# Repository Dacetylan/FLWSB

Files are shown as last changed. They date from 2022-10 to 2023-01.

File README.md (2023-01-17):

# FLSWB

Op deze webpagina kan je alle documentatie vinden over het Flexible LoRaWAN Development Board en alle onderdelen die daarbij horen.

Het project bestaat uit verschillende onderdelen:
- Printplaat met LoRaWAN verbinding
- Weerstation dat mee is geïntegreerd
- Backend die inkomende data verwerkt en opslaat
- Frontend om de metingen te kunnen weergeven

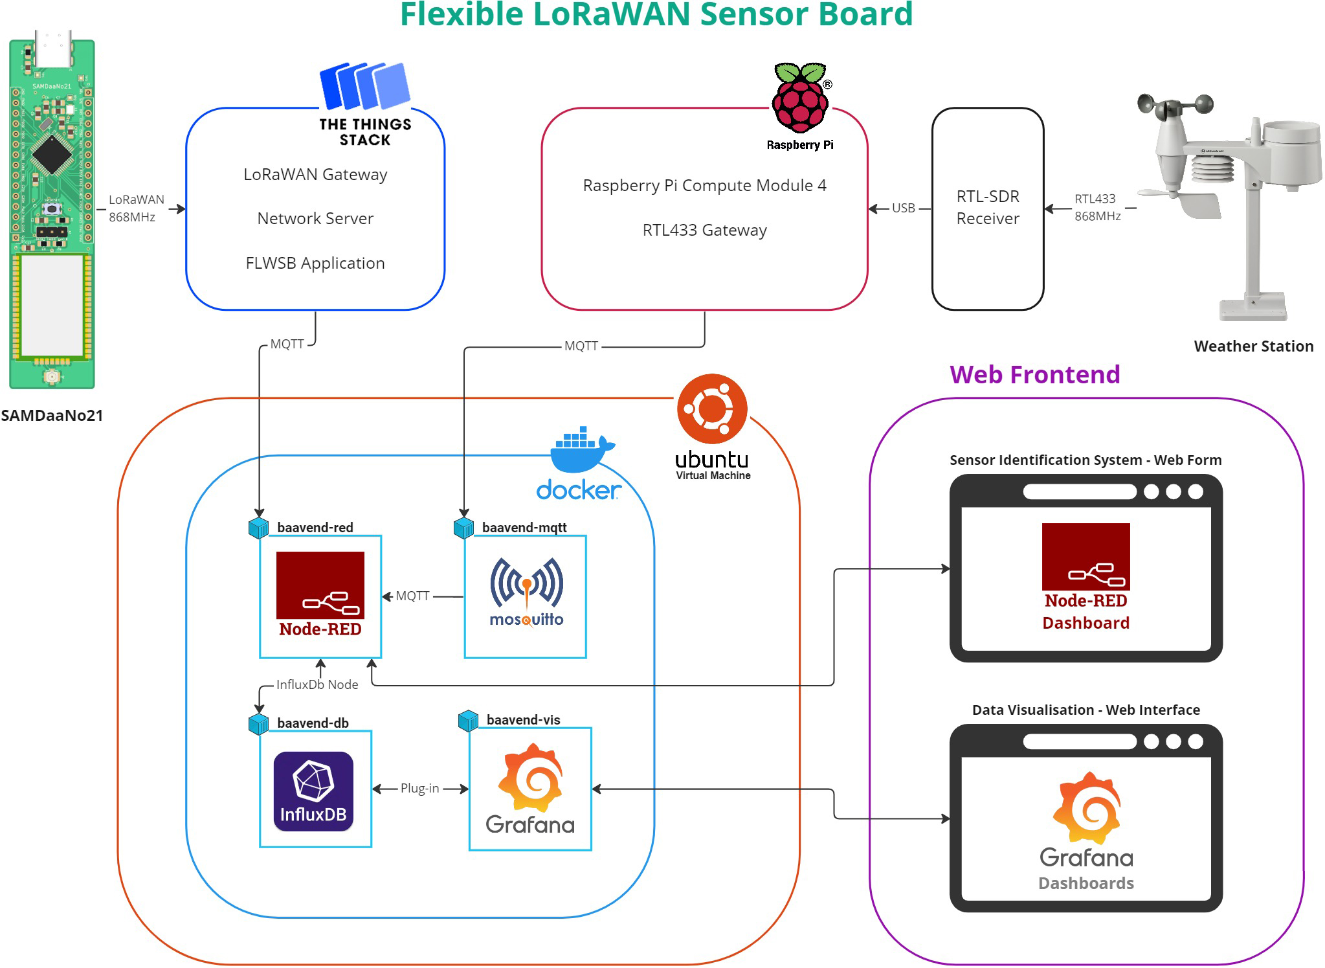
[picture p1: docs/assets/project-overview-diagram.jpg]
FLWSB Project overzichtsdiagram. Figuur 1: FLWSB Project overzichtsdiagram.


## Printplaat met LoRaWAN verbinding

* [Schema en bijhorende documentatie](./schematics/main-board.md)
* [Printplaat ontwerp en bijhorende documentatie](./printed-circuit-boards/main-board.md)
* [Connector Board schema en documentatie](./schematics/connector-board.md)

## Weerstation dat mee is geïntegreerd

* [Reverse Engineering](./weather-station/reverse-engineering.md)
* [Reading/Sending Data](./weather-station/data.md)

## Backend die inkomende data verwerkt en opslaat

* [BaaVend](./backend/baavend.md)

## Frontend om de metingen te kunnen weergeven

* [Mockup](./frontend/mockup.md)
* [Node-RED Dashboard](./frontend/dashboard.md)
* [Grafana](./frontend/grafana.md)

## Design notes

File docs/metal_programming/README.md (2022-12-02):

# Documentatie SAMDaaNo21 Programmatie

Dit is een korte handleiding om op weg te geraken met het programmeren van de SAMDaaNo21 (en andere SAMD chips). Deze handleiding gebruikt OpenOCD en gcc-arm-embedded in plaats van Atmel Studios. Atmel Studios maakt gebruik van dezelfde tools, toch werkt Atmel Studios enkel op Windows. Dit is geen optie aangezien er 3 operating systemen gebruikt worden in ons team (Windows, Mac OS, Linux Mint21). Het gebruik van open source tools zoals OpenOCD en gcc-arm-embedded maakt het een stuk makkelijker om samen de SAMDaaNo21 te programmeren.

Het is ook mogelijk de SAMDaaNo21 te programmeren zonder Atmel ICE. Dit kan met een RaspberryPI.

## Installatie

#### Mac OS

Om verder te kunnen is [Brew.sh](https://brew.sh/) nodig. Dit is een cli tool gelijkaardig aan apt-get op linux.

---

`brew install openocd --cask`

`brew install gcc-arm-embedded`

OpenOCD is een geweldige debug tool die met een groot bereik van microcontrollers werkt. Documentatie van OpenOCD is [hier](https://openocd.org/pages/documentation.html) te vinden. OpenOCD is ook verantwoordelijk voor het programmeren van de chip (de C code moet je uiteraard zelf nog schrijven).

gcc-arm-embedded is wat de C code compileert naar een binary file.

---

tijdens dat brew openocd aan het installeren is moet je een file aanmaken.

`touch openocd.cfg`

in deze file zet je het volgende:

```editorconfig
# Atmel-ICE JTAG/SWD in-circuit debugger.
interface cmsis-dap

# Chip info
set CHIPNAME at91samd21g16
source [find target/at91samdXX.cfg]
```

Als je een andere chip dan de SAMD21g16b gebruikt dan moet dit aangepast worden in de config file.

---

#### Windows

#### Linux

#### Raspberry Pi

## Verbinden

#### Atmel ICE

Op de user guide van de Atmel Ice ([hier te vinden](https://ww1.microchip.com/downloads/en/DeviceDoc/Atmel-ICE_UserGuide.pdf)) is een beschrijving van de pinout van de Atmel Ice. Deze is te vinden op pagina 22 onderaan in een tabel. De verbindingen met de SAMDaaNo21 zijn de volgende:

| Atmel Ice (SAM Port) | SAMDaaNo21 |
| --- | --- |
| SWDCLK | SWCLK |
| SWDIO | SWDIO |
| nSRST | RESET |
| VTG | 3V3 |
| GND | GND |

#### Raspberry Pi

## Compileren

#### Mac OS

Om op Mac OS een `.C` file te compileren naar een binaire file die geprogrammeerd kan worden op de SAMDaaNo21 moet er eerst een Makefile aangemaakt worden. 

`touch Makefile`

Zet de volgende code in de Makefile:

```makefile
# vervang hier samd21g16b_flash.ld en 
# __SAMD21G16B__ door de juiste chip als er 
# een andere chip gebruikt wordt.
LDSCRIPT = samd21g16b_flash.ld
PTYPE=__SAMD21G16B__

CC=arm-none-eabi-gcc
LD=arm-none-eabi-gcc
AR=arm-none-eabi-ar
AS=arm-none-eabi-as

ELF=$(notdir $(CURDIR)).elf
# vervang hier ./xdk-asf-3.52.0 door
# de juiste path naar ASF3.
# Let op. Dit kan een andere versie zijn!
ASF_ROOT=./xdk-asf-3.52.0

INCLUDES= \
        sam0/utils/cmsis/samd21/include \
        sam0/utils/cmsis/samd21/source \
        thirdparty/CMSIS/Include \
        thirdparty/CMSIS/Lib/GCC 

OBJS = startup_samd21.o main.o 

LDFLAGS+= -T$(LDSCRIPT) -mthumb -mcpu=cortex-m0 -Wl,--gc-sections
CFLAGS+= -mcpu=cortex-m0 -mthumb -g
CFLAGS+= $(INCLUDES:%=-I $(ASF_ROOT)/%) -I .
CFLAGS+= -D$(PTYPE)
CFLAGS+=-pipe -Wall -Wstrict-prototypes -Wmissing-prototypes -Werror-implicit-function-declaration \
-Wpointer-arith -std=gnu99 -fno-strict-aliasing -ffunction-sections -fdata-sections \
-Wchar-subscripts -Wcomment -Wformat=2 -Wimplicit-int -Wmain -Wparentheses -Wsequence-point \
-Wreturn-type -Wswitch -Wtrigraphs -Wunused -Wuninitialized -Wunknown-pragmas -Wfloat-equal \
-Wundef -Wshadow -Wbad-function-cast -Wwrite-strings -Wsign-compare -Waggregate-return \
-Wmissing-declarations -Wformat -Wmissing-format-attribute -Wno-deprecated-declarations \
-Wpacked -Wredundant-decls -Wnested-externs -Wlong-long -Wunreachable-code -Wcast-align \
--param max-inline-insns-single=500

$(ELF):    $(OBJS)
        $(LD) $(LDFLAGS) -o $@ $(OBJS) $(LDLIBS)

# compile and generate dependency info

%.o:    %.c
        $(CC) -c $(CFLAGS) $< -o $@
        $(CC) -MM $(CFLAGS) $< > $*.d

%.o:    %.s
        $(AS) $< -o $@

info:       
        @echo CFLAGS=$(CFLAGS)
        @echo OBJS=$(OBJS)

clean:
        rm -f $(OBJS) $(OBJS:.o=.d) $(ELF) $(CLEANOTHER)

debug:    $(ELF)
        arm-none-eabi-gdb -iex "target extended-remote localhost:3333" $(ELF)

-include    $(OBJS:.o=.d)
```

Vervolgens moet ASF (Advanced Software Framework) geïnstalleerd worden. ASF is gelijkaardig aan de Arduino Core, maar dan ontwikkeld door Atmel en gemaakt voor onder andere SAMD chips.

Download en unzip [hier](https://www.microchip.com/en-us/tools-resources/develop/libraries/advanced-software-framework#) ASF3. Hoewel er `Windows (x86/x64)` staat werkt deze ook op Mac OS.

Zet dan de unzipped ASF3 folder in je projectfolder. Er zijn een aantal files die nodig zijn uit deze framework. Deze kan je best ook kopieren naar je projectfolder. Met het commando `cp` is dit simpel.

`VERVANG_DIT_DOOR_ASF3_FOLDER/sam0/utils/cmsis/samd21/source/gcc/startup_samd21.c`

`VERVANG_DIT_DOOR_ASF3_FOLDER/sam0/utils/linker_scripts/samd21/gcc/samd21g16b_flash.ld`

Maak nu een `main.c` file. Hierin komt de `.C` code voor de SAMDaaNo21. Om te testen of dat compileren goed werkt is het mogelijk om het volgende blinky scriptje toe te voegen aan `main.c`. Verbind dan een LED aan PA02.

```c
#include <samd21.h>

static void delay(int n)
{
    int i;

    for (;n >0; n--)
    {
        for (i=0;i<100;i++)
            __asm("nop");
    }
}

int main(void)
{
    REG_PORT_DIR0 |= (1<<2);
    while (1)
    {
        REG_PORT_OUT0 &= ~(1<<2);
        delay(500);
        REG_PORT_OUT0 |= (1<<2);
        delay(500);
    }
}
```

Om nu deze `main.c` te compileren hoef je enkel nog een heel simpel commando uit te voeren:

`make`

#### Windows

#### Linux

#### Raspberry Pi

## Programmeren

Als OpenOCD en gcc-arm-embedded goed geïnstalleerd zijn dan zou het programmeren van de SAMDaaNo21 overal hetzelfde moeten werken.

Open een terminal venster, navigeer naar je projectfolder en voer daar het volgende commando in uit:

`openocd`

Open nu een tweede terminal venster, alle volgende commando's zullen uitgevoerd worden in dit tweede terminal venster

`telnet 127.0.0.1 4444`

> Als je een error krijgt dat telnet niet geïnstalleerd is dan kan je dat installeren met het volgende commando

> `sudo port install inetutils`

> Daarna is het mogelijk `telnet` te vervangen met `gtelnet`.

Eens deze opstelling behaald is kan de chip geprogrammeerd worden door het stappenplan hieronder te volgen

1. `init`

2. `targets`

3. `reset halt`

4. `at91samd21 bootloader 0`

5. `flash write_image [path naar de .elf file dat er gegenereerd is]`
   
   - Error bij dit commando?
     
     - `at91samd21 bootloader 0`
     
     - `at91samd21 chip-erase`
     
     - `reset`
     
     - druk op de reset knop van de SAMDaaNo21 en begin opnieuw vanaf stap 1

6. `flash verify_image [path naar de .elf file dat er gegenereerd is]`
   
   - Error bij dit commando?
     
     - `at91samd21 bootloader 0`
     
     - `at91samd21 chip-erase`
     
     - `reset`
     
     - druk op de reset knop van de SAMDaaNo21 en begin opnieuw vanaf stap 1

7. `at91samd21 bootloader 8192`

8. `reset`

9. druk op de reset knop van de SAMDaaNo21

Normaal gezien is nu de chip correct geprogrammeerd. Om na te kijken of dat dit ook werkt door met `targets` te kijken of er bij status `running` staat.

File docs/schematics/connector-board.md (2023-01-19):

# Connector board

Het connector board dient als verbindingspunt voor de SAMDaaNo21. Het is de tussenschakel om allerlei onderdelen te kunnen verbinden met de SAMD21 microcontroller. De focus ligt hier ook op fast prototyping en flexibiliteit. Dit wilt zeggen dat er enkel connectoren voorzien worden en geen sensoren rechtstreeks op dit bord zullen komen.

## Schema

FLWSB Connector Board schema v1.1

Het Connector Board is voorzien op een hele hoop aansluitingen:
 - Pin header voor SAMDaaNo21.
 - Pin header voor de Solar Power Manager.
 - Pin header voor +5 en +3V3 output naar sensoren.
 - Pin headers voor specifieke breakoutboard van sensoren.

 De laatst genoemde pin headers voor sensoren hebben een specifieke pinout voor bepaalde breakoutboards. Zo kunnen deze eenvoudig aangesloten worden op female pin headers, of rechtstreeks gesoldeerd. Maar deze kunnen uiteraard ook met andere sensoren verbonden worden, met aandacht voor de variërende pinouts.

Op de huidige iteratie van de SAMDaaNo21 zijn er geen LED's aanwezig voor visuele feedback. Dit geeft een lager stroomverbruik, maar voor debugging is dit niet zo handig.
Om die reden zijn er op dit Connector Board een aantal LED's aanwezig, te zien op het schema:
 - VIN (5V) van de SAMDaaNo21.
 - 3V3 van de SAMDaaNo21.
 - +3V3 op het Connector Board (LDL1117S33R).
 - RX en TX lijnen van UART connectoren.
 - RX en TX van de LoRa module.

Er is verder nog een pin header voorzien voor de LoRa RX en TX als testpunten.

## Blokdiagram

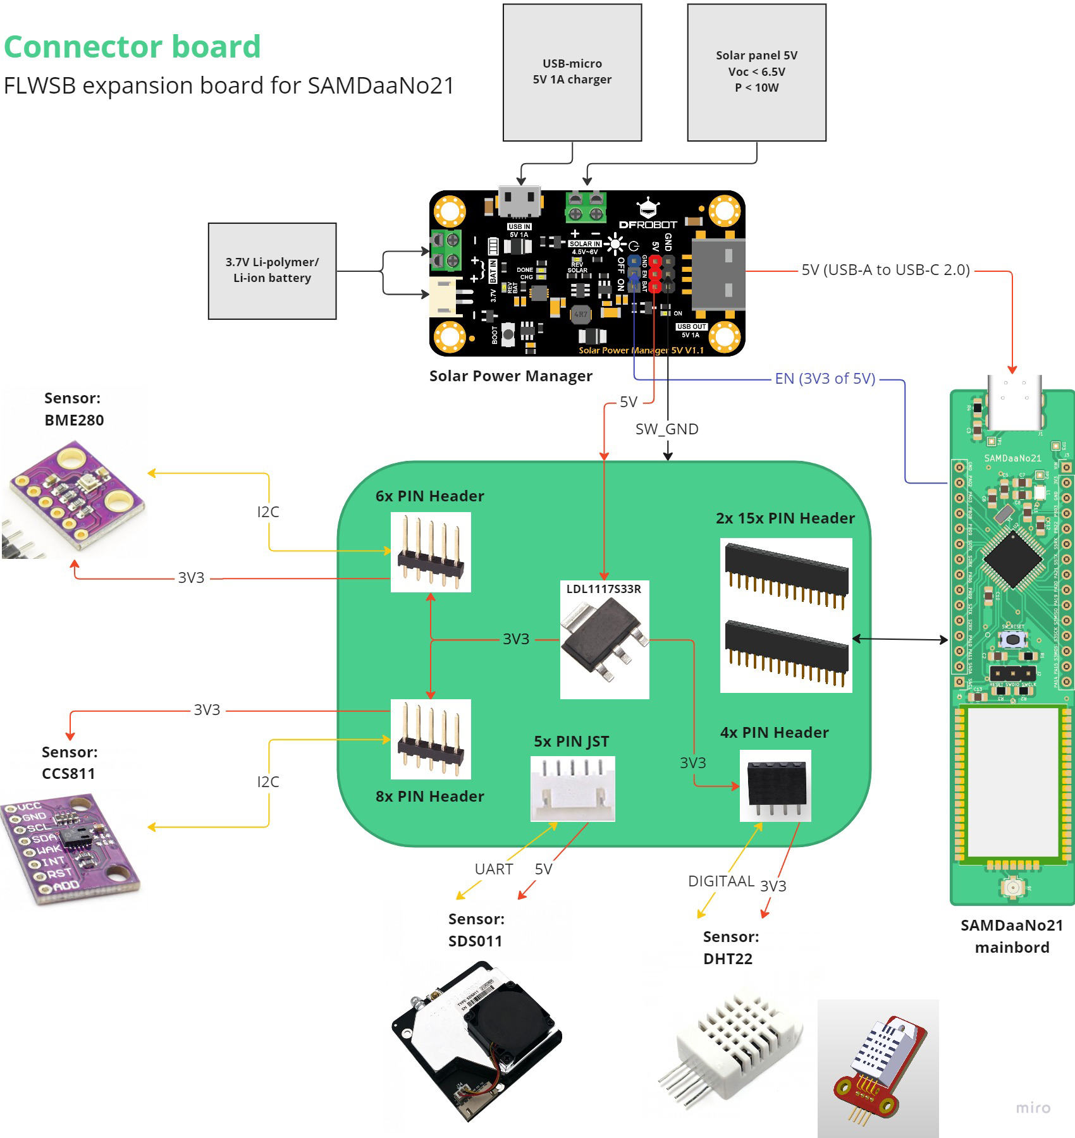
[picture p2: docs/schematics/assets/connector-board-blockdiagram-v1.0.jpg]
FLWSB Connector Board blokdiagram v1.0


*Note: in het ontwerp moet rekening gehouden worden met mechanische sterkte. De SAMDaaNo21 wordt gevoed via USB kabel. Deze kan echter loskomen. Dit moet voorkomen worden door het design.*

### Te connecteren onderdelen

- SAMDaaNo21 moederbord
- Zonne-energie (Solar Power) manager voor continu gebruik tussen batterij en zonnenpaneel.
- Sensoren:
  - [CCS811](https://www.sciosense.com/products/environmental-sensors/ccs811/): TVOC sensor met I2C op 1V8-3V3
  - [SDS011](https://www.tinytronics.nl/shop/nl/sensoren/lucht/stof/nova-sds011-hoge-precisie-laser-stofsensor): fijnstof sensor met UART 3V3 op 5V
  -  [BME280](https://www.bosch-sensortec.com/products/environmental-sensors/humidity-sensors-bme280/): temperatuur, barometer en luchtvochtigheid sensor met I2C op 1V8-3V3
  - ([DHT22](https://www.tinytronics.nl/shop/nl/sensoren/lucht/vochtigheid/dht22-thermometer-temperatuur-en-vochtigheids-sensor): temperatuur en luchtvochtigheid sensor alternatief met Digitale I/O op 3V3-6V)

### Uitbreidingsmogelijkheden

- 2x Extra I2C 3V3 met 3V3 voeding
- 1x Extra I2C met 5V voeding
- 1x Extra UART 3V3 met 3V3 voeding
- Mogelijke sensoren:
  - [SCD41](https://sensirion.com/products/catalog/SCD41/): CO2 met I2C op 3V3-5V
  - [SGP41](https://sensirion.com/products/catalog/SGP41/): TVOC en NOx met I2C op 1V8-3V3
  - [SPS30](https://sensirion.com/products/catalog/SPS30/): HVAC PM1.0, PM2.5, PM4 en PM10 met I2C en UART op 5V
  - [GY-NEO6MV2](https://www.tinytronics.nl/shop/nl/communicatie-en-signalen/draadloos/gps/modules/gy-neo6mv2-gps-module): GPS met UART 3V3 op 3V3-5V

### Stroomverbruik

Stroomverbruik per onderdeel en maximum wanneer alles aan is.

| Component | Stroomverbruik in operatie | Start-up | Meet periode | Stroomverbruik standby |
| --- | --- | --- | --- | --- |
| ATSAMD21G18A | I = 1 - 6 mA | n/a | n/a | I<sub>25-85°</sub> = 2.70 - 55.2µA |
| LDL1117S33R | ? | n/a | n/a | I<sub>Q typ.</sub> = 250µA
| CCS811  | I<sub>DD</sub> = 30mA , I<sub>DD peak</sub> = 54mA | 18 - 20ms | ? | I<sub>DD</sub> = 19µA |
| SDS011  | I<sub>rated</sub> = 70mA ±10mA | ? | <10s + 1s read | I < 4mA |
| BME280  | I<sub>DD H/P/T (1V8)</sub> = 340 / 714 / 350µA , I<sub>weather monitoring mode</sub> = 0.16µA | 2ms | <1s | I<sub>DD SB (1V8-3V6)</sub> = 0.2 - 0.5µA |
| DHT22  | I<sub>measuring (3V3)</sub> = 1mA | 1s | >2s | I<sub>stand-by (3V3)</sub> = 40µA |

*I<sub>Q</sub> = [Quiescent current](https://forum.digikey.com/t/what-is-quiescent-current-and-why-is-it-important/3894)*

I<sub>max. totaal</sub> = 6mA + (250µA * 2) + 54mA + 80mA + 714µA + 1mA

__I<sub>max. totaal</sub> = 142.214 mA__

---

#### Notes from the CCS811 datasheet

> Modes of Operation
The CCS811 has 5 modes of operation as follows
- Mode 0: Idle, low current mode
- Mode 1: Constant power mode, IAQ measurement every
second / 1 seconds
- Mode 2: Pulse heating mode IAQ measurement every 10
seconds
- Mode 3: Low power pulse heating mode IAQ
measurement every 60 seconds
- Mode 4: Constant power mode, sensor measurement
every 250ms

> In Modes 1, 2, 3, the equivalent CO2 concentration (ppm) and
eTVOC concentration (ppb) are calculated for every sample.
- Mode 1 reacts fastest to gas presence, but has a higher
operating current
- Mode 3 reacts more slowly to gas presence but has the
lowest average operating current.

> When a sensor operating mode is changed to a new mode with a
lower sample rate (e.g. from Mode 1 to Mode 3), it should be
placed in Mode 0 (Idle) for at least 10 minutes before enabling
the new mode. When a sensor operating mode is changed to a
new mode with a higher sample rate (e.g. from Mode 3 to Mode
1), there is no requirement to wait before enabling the new
mode.

> Mode 4 is intended for systems where an external host system
wants to run an algorithm with raw data and this mode provides
new sample data every 250ms. Mode 4 is also recommended
for end-of-line production test to save test time. For additional
information please refer to application note ScioSense
AN000373: CCS811 Factory test procedure.

---

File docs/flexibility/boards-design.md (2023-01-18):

# Flexibiliteit

## Introductie

Eén van de hoofddoelen van dit **Flexible LoRaWAN Sensor Board** project is een zo flexibel mogelijk modulair systeem bekomen. Hiervoor moet er rekening gehouden worden met dat er op elk afzonderlijk FLWS-board andere sensoren kunnen worden aangesloten. De metingen van deze sensoren moeten vervolgens draadloos verzonden worden aan de hand van LoRaWAN. Dit protocol verzend data geformatteerd in een bitstream. Hierbij moet er ook in acht genomen worden dat dit een batterij gevoede toepassing is. Elke extra bit die verzonden moet worden kost stroom en moet dus tot een minimum beperkt worden.
Om deze vraag te beantwoorden is er een modulair hardware design uitgewerkt samen met het **Sensor Identification System (SIS)**.

---

## Boards Design

Om tot een flexibel en modulair hardware systeem te komen is er gekozen om een opdeling te maken in twee boards. Een hoofd, of main, board die de microcontroller en LoRa radio module bevat, en een tweede connectie, of connector, board waar alle andere componenten op kunnen worden aangesloten.

Om deze twee boards van voeding te voorzien, aan de hand van batterij en zonne-energie, wordt er nog een derde Solar Power Manager board aangekocht.

In dit deel worden de ontwerp beslissingen rond deze drie boards besproken.

1. Main Board met LoRaWAN (SAMDaaNo21)
2. Connector Board
3. Solar Power Manager

Een behuizing hoort niet tot deze iteratie van het project en er zijn dus ook geen vereisten voor opgelegd.
In het hoofdstuk [Enclosure, of Behuizing](./enclosure/considerations.md), is wel een kijk genomen naar enkele overwegingen die in acht kunnen worden genomen. Er moet namelijk toch over nagedacht worden en rekening mee gehouden worden bij het ontwerpen.

#### Blokdiagram

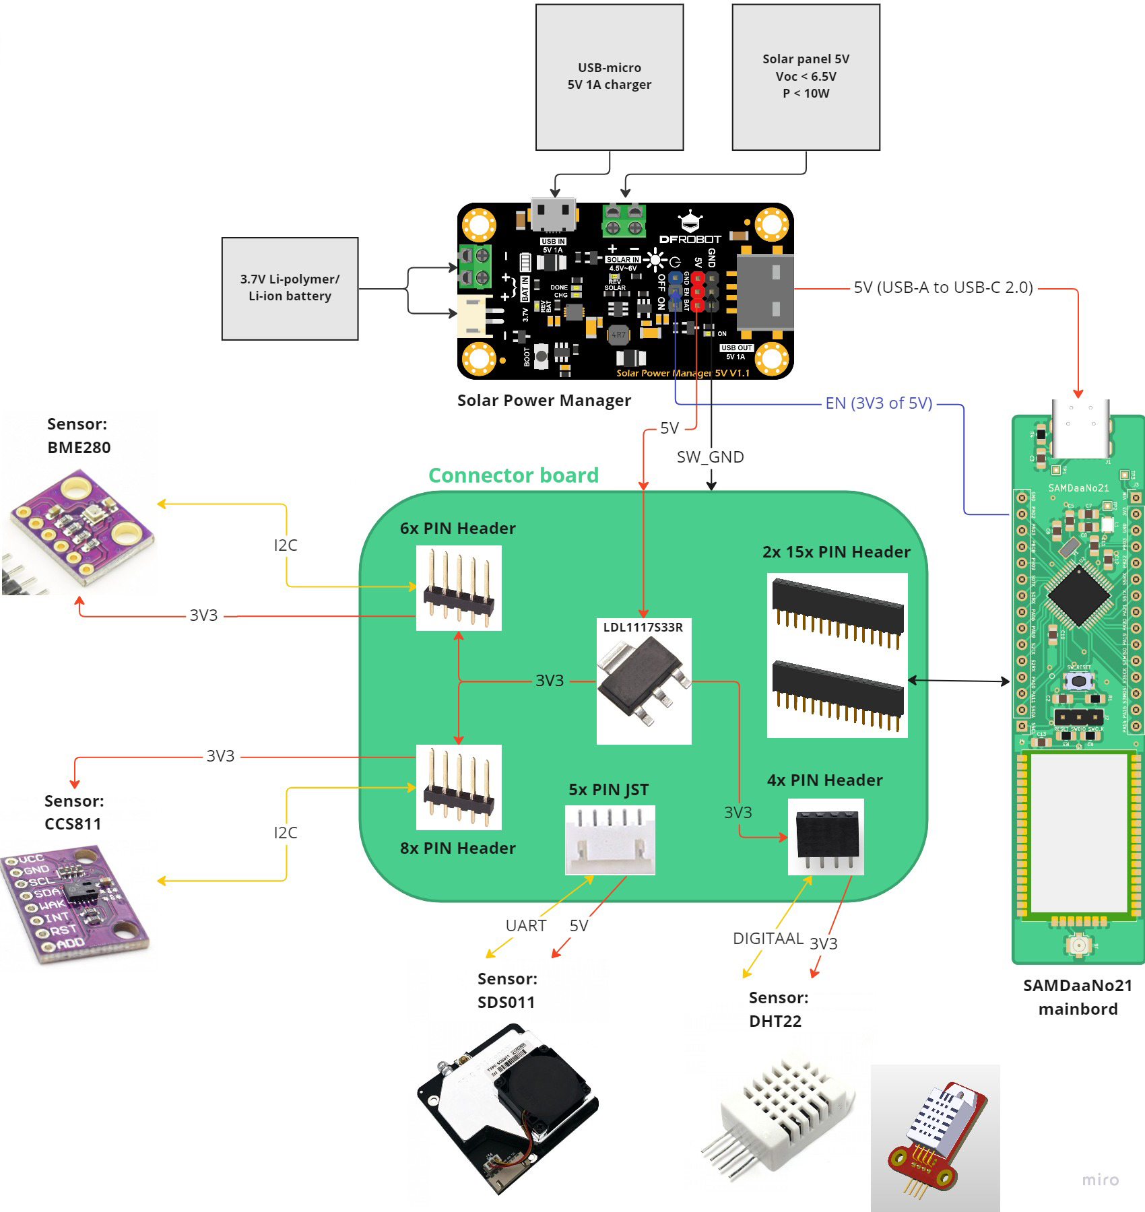
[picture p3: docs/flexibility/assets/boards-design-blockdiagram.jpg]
FLWSB Connector Board blokdiagram v1.0 Figuur 1: Overzicht blokdiagram van de drie boards.


*Note: in het ontwerp moet rekening gehouden worden met mechanische sterkte. De SAMDaaNo21 wordt gevoed via USB kabel. Deze kan echter loskomen. Dit moet voorkomen worden door het design.*

---

### Main Board met LoRaWAN (SAMDaaNo21)

Het FLWSB Main Board is een microcontroller bord gebaseerd op de ATSAM D21 in de vormfactor vergelijkbaar met een Arduino Nano. Het moet gemakkelijk zijn om dit bord in een breadboard te prikken en zo testen uit te voeren of schakelingen te bouwen.

De LoRa radio module zit hierop reeds geïntegreerd om zo de hoofdfunctie van het verzenden over LoRaWAN centraal te plaatsen.

#### Blokdiagram

Blokdiagram werking SAMDaaNo21 Figuur 2: Blokdiagram werking SAMDaaNo21.

---

### Connector Board

Het connector board dient als verbindingspunt voor de SAMDaaNo21. Het is de tussenschakel om allerlei onderdelen te kunnen verbinden met de SAMD21 microcontroller. De focus ligt hier ook op fast prototyping en flexibiliteit. Dit wilt zeggen dat er enkel connectoren voorzien worden en geen sensoren rechtstreeks op dit bord zullen komen.

#### Veresiten

##### Te connecteren onderdelen

- SAMDaaNo21 moederbord
- Zonne-energie (Solar Power) manager voor continu gebruik tussen batterij en zonnepaneel.
- Sensoren:
  - [CCS811](https://www.sciosense.com/products/environmental-sensors/ccs811/): TVOC sensor met I2C op 1V8-3V3
  - [SDS011](https://www.tinytronics.nl/shop/nl/sensoren/lucht/stof/nova-sds011-hoge-precisie-laser-stofsensor): fijnstof sensor met UART 3V3 op 5V
  -  [BME280](https://www.bosch-sensortec.com/products/environmental-sensors/humidity-sensors-bme280/): temperatuur, barometer en luchtvochtigheid sensor met I2C op 1V8-3V3
  - ([DHT22](https://www.tinytronics.nl/shop/nl/sensoren/lucht/vochtigheid/dht22-thermometer-temperatuur-en-vochtigheids-sensor): temperatuur en luchtvochtigheid sensor alternatief met Digitale I/O op 3V3-6V)

##### Uitbreidingsmogelijkheden

- 2x Extra I2C 3V3 met 3V3 voeding
- 1x Extra I2C met 5V voeding
- 1x Extra UART 3V3 met 3V3 voeding
- Mogelijke sensoren:
  - [SCD41](https://sensirion.com/products/catalog/SCD41/): CO2 met I2C op 3V3-5V
  - [SGP41](https://sensirion.com/products/catalog/SGP41/): TVOC en NOx met I2C op 1V8-3V3
  - [SPS30](https://sensirion.com/products/catalog/SPS30/): HVAC PM1.0, PM2.5, PM4 en PM10 met I2C en UART op 5V
  - [GY-NEO6MV2](https://www.tinytronics.nl/shop/nl/communicatie-en-signalen/draadloos/gps/modules/gy-neo6mv2-gps-module): GPS met UART 3V3 op 3V3-5V

#### Sensoren

Sensor analyse uit [AirQualitySensor documentatie](https://ap-it-gh.github.io/ssys21-docs-luchtsensor/#/./pagina/Hardware/PCB) (DHT22 toegevoegd):
<table>
    <tbody><tr>
        <th>Naam</th>
        <th width="40%">Eigenschappen</th>
        <th width="30%">Argumentatie</th>
        <th>Links</th>
    </tr>
    <tr>
        <td>CCS811</td>
        <td>
            <ul>
                <li><b>Temperatuur, eCO en eTVOC<sup>2</sup></b></li>
                <li>V<sub>cc</sub> = 1.8V-3.3V</li>
                <li>I<sub>max</sub> = 54mA</li>
                <li><a target="_blank" href="https://en.wikipedia.org/wiki/I%C2%B2C">I²C</a> protocol 3.3V</li>
                <li>Meetbereik temperatuur: -40°C ~ +85°C</li>
                <li>Meetbereik luchtvochtigheid: 10% ~ 95% </li>
                <li>Meetbereik eCO²: 400ppm<sup>1</sup> ~ 32768ppm</li>
                <li>Meetbereik eTVOC: 0ppb<sup>5</sup> ~ 29206ppb</li>
                <li>Leessnelheid: 100kHz (0.01ms)</li>
            </ul>
        </td>
        <td>Een minder bekende sensor maar zeker wel bekend in IoT toepassingen. Het kan temperatuur, eCO² en eTVOC meten. Het heeft geen opwarm tijd dus is direct bruikbaar en is ook een SMD component wat zeker een voordeel is om het zo compact mogelijk te maken.</td>
        <td>
            <a target="_blank" href="https://www.tinytronics.nl/shop/nl/sensoren/ccs811-luchtkwaliteit-sensor">Winkel</a><br>
            <a target="_blank" href="https://www.sciosense.com/wp-content/uploads/documents/SC-001232-DS-2-CCS811B-Datasheet-Revision-2.pdf">Datasheet</a><br>
            <a target="_blank" href="https://github.com/adafruit/Adafruit_CCS811">Bibliotheek</a>
        </td>
    </tr>
    <tr>
        <td>SDS011</td>
        <td>
            <ul>
                <li><b>Fijnstof</b></li>
                <li>V<sub>cc</sub> = 5V</li>
                <li>I<sub>rated</sub> = 70mA ±10mA</li>
                <li><a target="_blank" href="https://en.wikipedia.org/wiki/Universal_asynchronous_receiver-transmitter">UART</a> protocol 3.3V</li>
                <li>Baudrate: 9600</li>
                <li>Meetbereik PM2.5<sup>3</sup> &amp; PM10<sup>4</sup>: 0μg/m3 ~ 999.9 μg/m3</li>
                <li>Meetbereik luchtvochtigheid: 10% ~ 95% </li>
                <li>Leessnelheid: 1Hz (1s)</li>
            </ul>
        </td>
        <td>De SDS011 is een veel gebruikte fijnstof sensor voor DIY-projecten. Het zal niet de nauwkeurigste zijn, maar het geeft toch al een sterke indicatie van wat het fijnstof gehalte is in de lucht. Daarnaast het een goedkope modele.<br><br>
        Het werkt met een ventilator die de lucht binnentrekt. Het zal dus eerst moeten opgezet wordne om de huidige lucht erin te trekken vooraleer we kunnen meten.</td>
        <td>
            <a target="_blank" href="https://www.tinytronics.nl/shop/nl/sensoren/nova-sds011-hoge-precisie-laser-stofsensor">Winkel</a><br>
            <a target="_blank" href="https://cdn-reichelt.de/documents/datenblatt/X200/SDS011-DATASHEET.pdf">Datasheet</a><br>
            <a target="_blank" href="https://www.arduinolibraries.info/libraries/sds011-sensor-library">Bibliotheek</a>
        </td>
    </tr>
    <tr>
        <td>BME280</td>
        <td>
            <ul>
                <li><b>Temperatuur, Barometer &amp; Luchtvochtigheid</b></li>
                <li>V<sub>cc</sub> = 1.8 - 3.6V</li>
                <li>I<sub>max</sub> = 4.5mA</li>
                <li><a target="_blank" href="https://en.wikipedia.org/wiki/I%C2%B2C">I²C</a> protocol 3.3V</li>
                <li>Meetbereik temperatuur: -40°C ~ +85°C</li>
                <li>Meetbereik luchtvochtigheid: 0% ~ 100%</li>
                <li>Meetbereik luchtdruk: 300hPa ~ 1100hPa</li>
                <li>Leessnelheid: 1Hz (1s)</li>
            </ul>
        </td>
        <td>Deze digitale IC heeft een tal van metingen aanboord (temperatuur, luchtvochtigheid en druk). Het is ook een SMD component, dus makkelijk integreerbaar op een pcb.</td>
        <td>
            <a target="_blank" href="https://www.tinytronics.nl/shop/nl/sensoren/temperatuur-lucht-vochtigheid/bme280-digitale-barometer-druk-en-vochtigheid-sensor-module">Winkel</a><br>
            <a target="_blank" href="https://www.mouser.com/datasheet/2/783/BST-BME280_DS001-11-844833.pdf">Datasheet</a><br>
            <a target="_blank" href="https://github.com/adafruit/Adafruit_BME280_Library">Bibliotheek</a>
        </td>
    </tr>
    <tr>
        <td>DHT22</td>
        <td>
            <ul>
                <li><b>Temperatuur, Luchtvochtigheid</b></li>
                <li>V<sub>cc</sub> = 3.3-6V DC</li>
                <li>I<sub>max</sub> = ? mA</li>
                <li>Digital signal via single-bus (zie datasheet)</li>
                <li>Meetbereik temperatuur: -40°C ~ +80°C</li>
                <li>Meetbereik luchtvochtigheid: 0% - 100%</li>
                <li>Leessnelheid: 2Hz (~2s)</li>
            </ul>
        </td>
        <td>Een handige temperatuur én vochtigheid sensor.</td>
        <td>
            <a target="_blank" href="https://www.tinytronics.nl/shop/nl/sensoren/lucht/vochtigheid/dht22-thermometer-temperatuur-en-vochtigheids-sensor">Winkel</a><br>
            <a target="_blank" href="https://www.tinytronics.nl/shop/index.php?route=product/product/get_file&file=136/DHT22.pdf">Datasheet</a><br>
            <a target="_blank" href="">Bibliotheek</a>
        </td>
    </tr>
</tbody></table>

---

### Voeding

De flexibiliteit wordt ook doorgevoerd in de voeding van de schakeling.
Er is gekozen voor een voeding op batterij gecombineerd met zonnepanelen.
Zo kan de schakeling op batterij functioneren wanneer er geen zonlicht is, en wanneer die er wel is kan de voeding over gaan op zonne-energie waarmee ook de batterij terug wordt opgeladen.

#### Stroomverbruik

Stroomverbruik per onderdeel en maximum wanneer alles aan is.

| Component | Stroomverbruik in operatie | Start-up | Meet periode | Stroomverbruik standby |
| --- | --- | --- | --- | --- |
| ATSAMD21G18A | I = 1 - 6 mA | n/a | n/a | I<sub>25-85°</sub> = 2.70 - 55.2µA |
| LDL1117S33R | ? | n/a | n/a | I<sub>Q typ.</sub> = 250µA
| CCS811  | I<sub>DD</sub> = 30mA , I<sub>DD peak</sub> = 54mA | 18 - 20ms | ? | I<sub>DD</sub> = 19µA |
| SDS011  | I<sub>rated</sub> = 70mA ±10mA | ? | <10s + 1s read | I < 4mA |
| BME280  | I<sub>DD H/P/T (1V8)</sub> = 340 / 714 / 350µA , I<sub>weather monitoring mode</sub> = 0.16µA | 2ms | <1s | I<sub>DD SB (1V8-3V6)</sub> = 0.2 - 0.5µA |
| DHT22  | I<sub>measuring (3V3)</sub> = 1mA | 1s | >2s | I<sub>stand-by (3V3)</sub> = 40µA |

*I<sub>Q</sub> = [Quiescent current](https://forum.digikey.com/t/what-is-quiescent-current-and-why-is-it-important/3894)*

I<sub>max. totaal</sub> = 6mA + (250µA * 2) + 54mA + 80mA + 714µA + 1mA

__I<sub>max. totaal</sub> = 142.214 mA__

---

#### Zonne-energie manager

Eén van de doelen van het connector board is om continue stroom te kunnen voorzien. Dit door te kunnen schakelen tussen een oplaadbare batterij en een zonnepaneel die da batterij ook kan opladen.
Verder moet het ook voldoende spanning en stroom kunnen voorzien. De SAMDaaNo21 beschikt reeds over een 3V3 lineaire regelaar die gevoed kan worden via een VIN pin waarop ook een 5V USB-C poort zit. De zonne-energie manager moet best 5V kunnen leveren om sensoren op 5V ook te kunnen voeden en ook de VIN van de SAMDaaNo21.

Er wordt gekozen voor de DFRobot Zonne-energie Manager 5V v1.1 DFR0559.
Deze laat toe een heroplaadbare batterij op te laden

DFROBOT-DFR0559 foto Figuur 3: Foto van de DFROBOT-DFR0559.

##### Eigenschappen

- Model: DFROBOT-DFR0559
- Solar Power Management IC: CN3165
- Solar Input Voltage (SOLAR IN): 4.5V ~ 6V
  - Maximum open circuit voltage < 6.5V
- Battery Input (BAT IN): 3.7V Single cell Li-polymer/Li-ion Battery
- Charge Current(USB/SOLAR IN):
  - 900mA Max trickle charging
  - constant current
  - constant voltage three phases charging
- Charging Cutoff Voltage (USB/SOLAR IN): 4.2V ±1%
- Regulated Power Supply: 5V 1A
- Voltage Regulator IC: MT3608 DC-DC Boost 5V
- Regulated Power Supply Efficiency (3.7V BAT IN): 86% @ 50%Load
- USB/Solar Charge Efficiency: 73% @ 3.7V 900mA BAT IN
- Quiescent Current: <1 mA
- Operation Temperature: -40℃ ～ 85℃
- Dimension: 33.0mm x 63.0mm
- Protection Functions:
  - BAT IN: over charge/over discharge/over current/reverse connection protection
  - 5V/USB OUT: short circuit/over current/over heat protection
  - SOLAR IN: reverse connection protection
- Prijs: €9,50 per stuk op [TinyTronics](https://www.tinytronics.nl/shop/nl/power/bms-en-laders/zonneladers/dfrobot-zonne-energie-manager-5v)
- [DFRobot webshop pagina](https://www.dfrobot.com/product-1712.html)
- [Documentatie](https://wiki.dfrobot.com/Solar_Power_Manager_5V_SKU__DFR0559)
- [Schema](./assets/DFROBOT-DFR0559/DFR0559-schematic.pdf)

##### Features

- Constant voltage MPPT algorithm, maximizing solar panel efficiency
- Designed for 5V solar panel
- Double charging mode: solar/USB charger (900mA max charge current)
- 5V ON/OFF controllable regulated power supply for low-power applications
- All-round protection functions
- USB connector with ESD shell

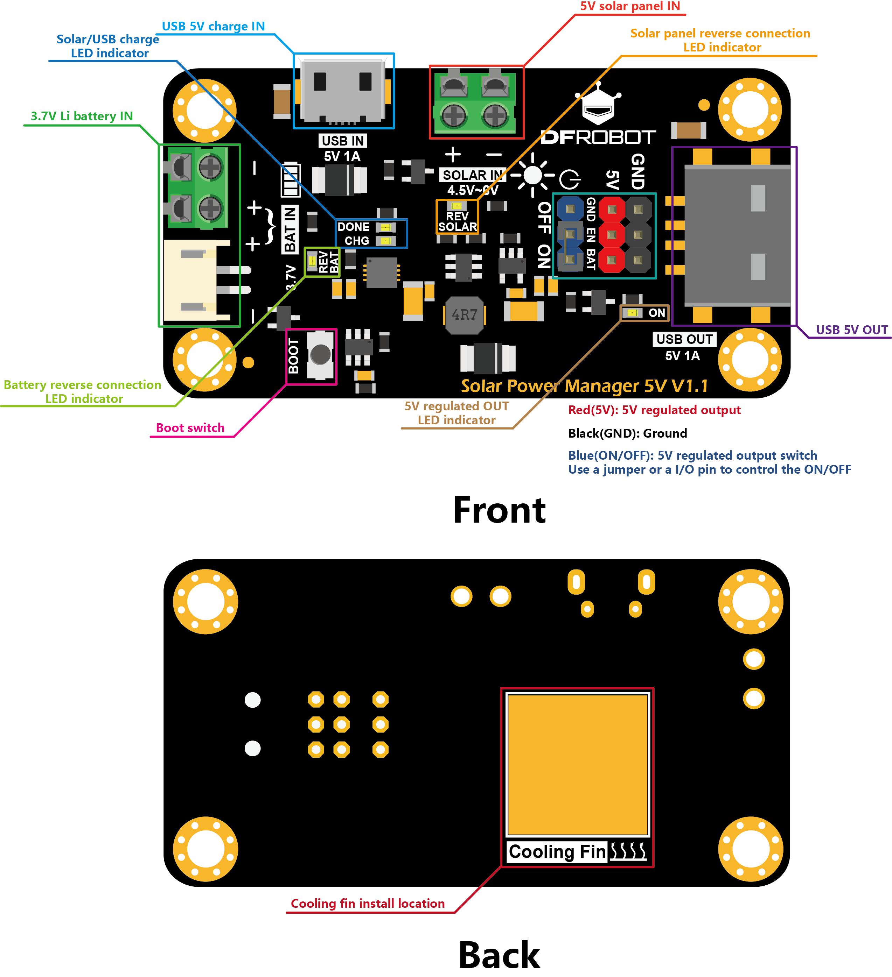
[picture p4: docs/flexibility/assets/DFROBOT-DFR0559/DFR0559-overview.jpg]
DFROBOT-DFR0559 overzicht Figuur 4: DFROBOT-DFR0559 overzicht


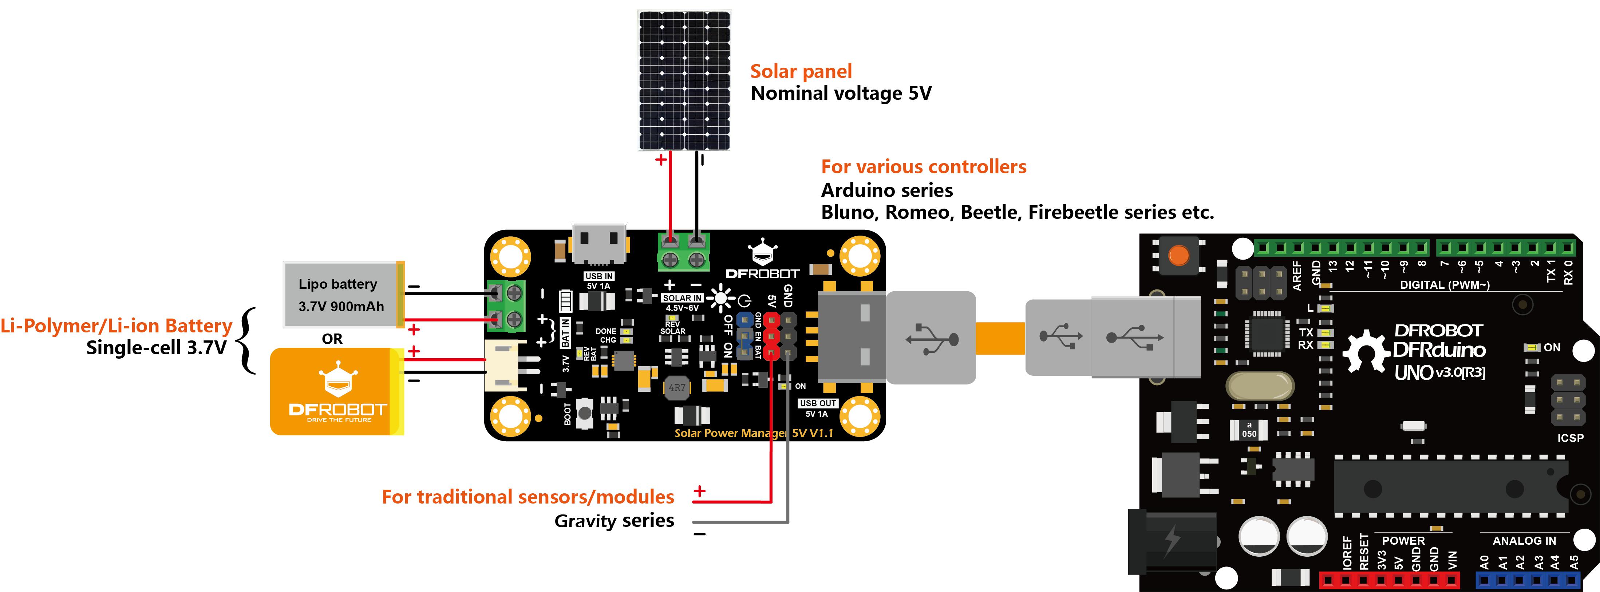
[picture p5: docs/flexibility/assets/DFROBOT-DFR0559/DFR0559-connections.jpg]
DFROBOT-DFR0559 connecties Figuur 5: DFROBOT-DFR0559 connecties


##### ON/OFF functie

Een zeer handige functie waarover de DFROBOT-DFR0559 beschikt is de mogelijkheid om de 5V output pins aan en uit te schakelen via een enable pin (EN). De USB output blijft hierbij wel nog 5V krijgen. Zo kan een MCU board ononderbroken gevoed worden via USB en via een GPIO pin de enable aansturen en de stroomvoorziening naar sensoren controleren. Via de BAT pin kan ook de batterij capaciteit uitgelezen worden met een analoge pin/ADC.

Hieronder een voorbeeld uit de [documentatie](https://wiki.dfrobot.com/Solar_Power_Manager_5V_SKU__DFR0559):

> This application example use the BME280 environmental sensor to record temperature, humidity and atmospheric pressure, VEML7700 ambient light sensor to record the the ambient illumination, and DS1307 RTC module to record time. Use the analog input A1 to monitor the battery voltage (equivalently the battery capacity). To achieve lower power consumption, use one Arduino digital IO pin to turn ON the power supply, read all the data from the sensors and turn them OFF. Cycle this pattern for a proper interval T to reduce the average power consumption. This can completely get rid of the quiescent power of the peripheral modules. Although single peripheral may consume little power, it can be considerable large for a number of them. This module provides users with effective methods to drive the peripheral modules into discontinuous (pulse) mode to achieve low power operation.
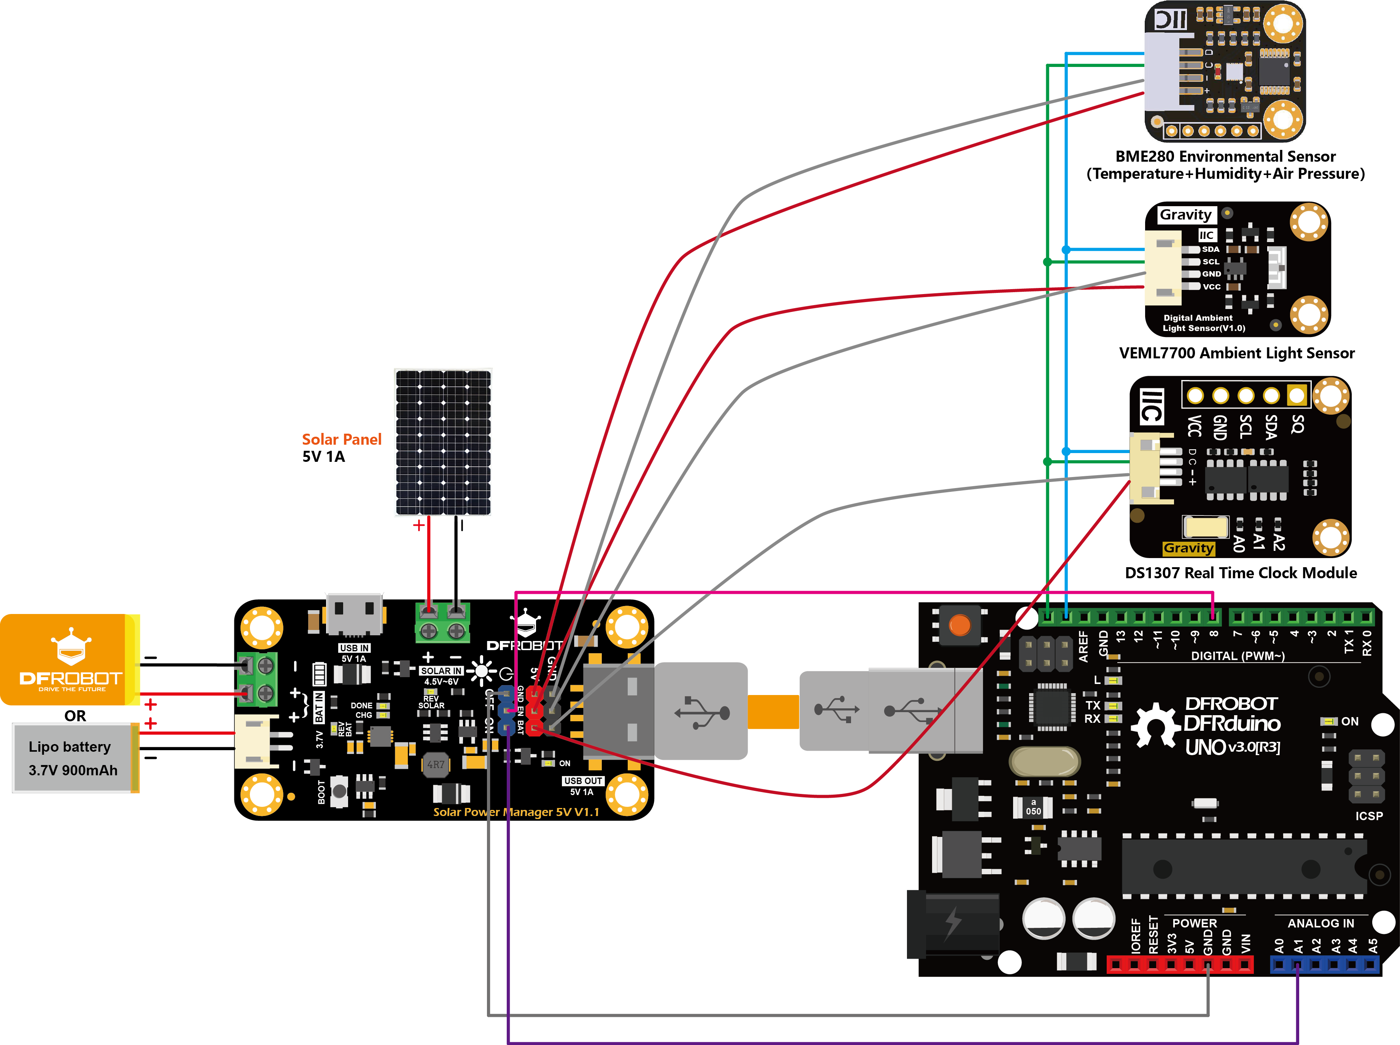
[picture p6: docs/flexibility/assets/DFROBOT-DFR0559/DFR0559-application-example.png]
DFROBOT-DFR0559 application example Figuur 6: DFROBOT-DFR0559 application example


--

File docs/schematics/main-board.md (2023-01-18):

 # Flexible LoRaWAN Sensor Board SAMDaaNo21

Het FLWSB Main Board is een microcontroller bord gebaseerd op de ATSAM D21 in de vormfactor vergelijkbaar met een Arduino Nano. Het moet gemakkelijk zijn om dit bord in een breadboard te prikken en zo testen uit te voeren of schakelingen te bouwen. Het elektrisch schema van dit bord ziet er als volgt uit:

Figuur 1: FLWSB-SAMDaaNo21 schema

Alle onderdelen worden verder toegelicht.

Figuur 2: Blokdiagram werking SAMDaaNo21

[ATSAM D21 Datasheet](https://ww1.microchip.com/downloads/en/DeviceDoc/SAM-D21DA1-Family-Data-Sheet-DS40001882G.pdf)

## Testpunten

Er zijn verschillende testpunten toegevoegd om op een gemakkelijke en toegankelijke manier verschillende parameters op het bord te kunnen meten.

| Testpunt nummer | Verbinding |
| --- | --- |
| TP1 | VBUS: 5 V afkomstig van USB |
| TP2 | VDD: 3,3 V gereguleerde spanning |
| TP3 | VIN: Ingangsspanning voordat het naar de lineaire regelaar gaat |

## LoRaWAN Module

Figuur 3: LoRaWAN module

Er is een RN2483 module mee geïmplementeerd op de printplaat. Deze is aangesloten op de UART bus van SERCOM 2.

## USB Interface & VIN

Figuur 4: USB Interface & VIN schema

Het schema voor de USB-interface is gebaseerd op een voorbeeld uit een Atmel handleiding. De zener diodes die zichtbaar zijn zorgen ervoor dat de kans op schade door elektrostatische ontlading (ESD) beperkt wordt.

Figuur 5: USB Interface & VIN schema

[Ref USB-applications note](https://ww1.microchip.com/downloads/en/DeviceDoc/Atmel-42261-SAM-D21-USB_Application-Note_AT06475.pdf)

[Ref schematic checklist](https://ww1.microchip.com/downloads/en/DeviceDoc/SAM-D21DA1-Family-Data-Sheet-DS40001882G.pdf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)

De Schottky diode (D6) is er om de USB-poort van je laptop te beschermen wanneer het bord van stroom wordt voorzien via de VIN pin. Het zou kunnen dat aan de VIN pin een hogere spanning wordt geleverd dan 5 V waardoor dit potentiaalverschil ongewenste stroom kan laten vloeien. Hetzelfde principe wordt toegepast bij de ESP32 DEVKIT.

`TP3` is een testpunt dat aanwezig is om op een toegankelijke manier de VIN-spanning te meten.

[Ref ESP32 schema](https://dl.espressif.com/dl/schematics/esp32_devkitc_v4-sch-20180607a.pdf)

## RESET & DEBUG

Figuur 6: RESET & DEBUG schema

De reset knop is opgebouwd zoals in de datasheet van de ATSAM D21 wordt weergegeven onder "Schematic Checklist Figure 45-4. External Reset Circuit Schematic".

## Low Dropout Lineair Regulator

Figuur 7: Low Dropout Lineair Regulator schema

In dit geval wordt er een LD1117 3,3 V regelaar gebruikt. Deze regelaar kan met een vrij groot ingangsbereik (tot 15 V) een uitgangsspanning van 3,3 V leveren.

`TP2` is een testpunt dat aanwezig is om op een toegankelijke manier de 3.3 V gereguleerde spanning te meten.

[LD1117 datasheet](https://www.st.com/resource/en/datasheet/ld1117.pdf)

## Power Supply Connections

Figuur 8: Power Supply Connections schema

Het schema voor de ontkoppelcondensatoren en spoel voor de ATSAM D21 komt ook rechtstreeks uit de datasheet. Wat belangrijk is bij deze componenten is dat alles rechts van de blauwe stippellijn zo dicht mogelijk bij de vermelde pinnen staat. Deze condensatoren vangen kleine storingen en rimpels op die zich voordoen in de bronspanning.

## Input / Output

Figuur 9: Input / Output schema

Dit zijn alle GPIO, SERCOM en power aansluitingen die via pinheaders naar buiten worden gebracht. De SERCOM poorten zijn alvast gedefinieerd zodat onder andere de pull-up weerstanden geplaatst kunnen worden. Alle andere poorten zijn voor algemeen gebruik. In de datasheet van de ATSAM D21 onder 7. I/O Multiplexing and Considerations kunnen alle verschillende mogelijkheden van deze aansluitingen gevonden worden (AC, ADC, DAC, PTC, DAC, IO, ...).

| I/O Pin | Pin | SERCOM | SERCOM-ALT | External Interrupt | ADC, DAC, AC, REF | Peripheral Touch Controller | TC/TCC | TCC | COM | Generic Clock Generator |
| --- | --- | --- | --- | --- | --- | --- | --- | --- | --- | --- |
| GND | PowerPin | Ground Reference | | | | | | | | |
| PA02 | 3 | | | EXTINT:2 | ADC:0<br/>VOUT | Y:0 | | TCC3/<br/>WO:0 | | |
| PA03 | 4 | | | EXTINT:3 | ADC:1<br/>VREFA | Y:1 | | TCC3/<br/>WO:1 | | |
| PB08 | 7 | | SCOM4/<br/>PAD:0 | EXTINT:8 | ADC:2 | Y:14 | TC4/<br/>WO:0  | TCC3/<br/>WO:6 | | |
| PB09 | 8 | | SCOM4/<br/>PAD:1 | EXTINT:9 | ADC:3 | Y:15 | TC4/<br/>WO:1  | TCC3/<br/>WO:7 | | |
| PA04 | 9 | | SCOM0/<br/>PAD:0 | EXTINT:4 | ADC:4<br/>AC:0 VREFB | Y:2 | TCC0/<br/>WO:0 | TCC3/<br/>WO:2 | | |
| PA05 | 10 | | SCOM0/<br/>PAD:1 | EXTINT:5 | ADC:5<br/>AC:1 | Y:3 | TCC0/<br/>WO:1 | TCC3/<br/>WO:3 | | |
| PA06 | 11 | | SCOM0/<br/>PAD:2 | EXTINT:6 | ADC:6<br/>AC:2 | Y:4 | TCC1/<br/>WO:0 | TCC3/<br/>WO:4 | | |
| PA07 | 12 | | SCOM0/<br/>PAD:3 | EXTINT:7 | ADC:7<br/>AC:3 | Y:5 | TCC1/<br/>WO:1 | TCC3/<br/>WO:5 | I2S/<br/>SD:0 | |
| PA08 | 13 | SCOM0/<br/>PAD:0 | SCOM2/<br/>PAD:0 | NMI | ADC:16 | X:0 | TCC0/<br/>WO:0 | TCC1/<br/>WO:2 | I2S/<br/>SD:1 | |
| PA09 | 14 | SCOM0/<br/>PAD:1 | SCOM2/<br/>PAD:1 | EXTINT:9 | ADC:17 | X:1 | TCC0/<br/>WO:1 | TCC1/<br/>WO:3 | I2S/<br/>MCK:0 | |
| PA10 | 15 | SCOM0/<br/>PAD:2 | SCOM2/<br/>PAD:2 | EXTINT:10 | ADC:18 | X:2 | TCC1/<br/>WO:0 | TCC0/<br/>WO:2 | I2S/<br/>SCK:0 | GCLK:4 |
| PA11 | 16 | SCOM0/<br/>PAD:3 | SCOM2/<br/>PAD:3 | EXTINT:11 | ADC:19 | X:3 | TCC1/<br/>WO:1 | TCC0/<br/>WO:3 | I2S/<br/>FS:0 | GCLK:5 |
| PA12 | 21 | SCOM2/<br/>PAD:0 | SCOM4/<br/>PAD:0 | EXTINT:12 | AC:0 | | TCC2/<br/>WO:0 | TCC0/<br/>WO:6 | | |
| PA13 | 22 | SCOM2/<br/>PAD:1 | SCOM4/<br/>PAD:1 | EXTINT:13 | AC:1 | | TCC2/<br/>WO:1 | TCC0/<br/>WO:7 | | |
| VIN | PowerPin | LDL1117S33 4.3 V - 15 V | | | | | | | | |
| 3V3 | PowerPin | 3.3V LDO output | | | | | | | | |
| GND | PowerPin | Ground Reference | | | | | | | | |
| PB03 | 48 | | SCOM5/<br/>PAD:1 | EXTINT:3 | ADC:11 | Y:9 | TC6/<br/>WO:1  | TCC3/<br/>WO:3 | | |
| PB22 | 37 | | SCOM5/<br/>PAD:2 | EXTINT:6 | | | TC7/<br/>WO:0  | TCC3/<br/>WO:0 | | GCLK:0 |
| PA23 | 32 | SCOM3/<br/>PAD:1 | SCOM5/<br/>PAD:1 | EXTINT:7 | | X:11 | TC4/<br/>WO:0  | TCC0/<br/>WO:5 | USB/<br/>SOF 1KhZ | GCLK:7 |
| PA22 | 31 | SCOM3/<br/>PAD:0 | SCOM5/<br/>PAD:0 | EXTINT:6 | | X:10 | TC4/<br/>WO:1  | TCC0/<br/>WO:4 | | GCLK:6 |
| PA21 | 30 | SCOM5/<br/>PAD:3 | SCOM3/<br/>PAD:3 | EXTINT:5 | | X:9 | TC7/<br/>WO:1  | TCC0/<br/>WO:7 | I2S/<br/>FS:0 | GCLK:5 |
| PA20 | 29 | SCOM5/<br/>PAD:2 | SCOM3/<br/>PAD:2 | EXTINT:4 | | X:8 | TC7/<br/>WO:0  | TCC0/<br/>WO:6 | I2S/<br/>SCK:0 | GCLK:4 |
| PA19 | 28 | SCOM1/<br/>PAD:3 | SCOM3/<br/>PAD:3 | EXTINT:3 | AC:1 | X:7 | TC3/<br/>WO:1  | TCC0/<br/>WO:3 | I2S/<br/>SD:0 | |
| PA18 | 27 | SCOM1/<br/>PAD:2 | SCOM3/<br/>PAD:2 | EXTINT:2 | AC:0 | X:6 | TC3/<br/>WO:0  | TCC0/<br/>WO:2 | | |
| PA17 | 26 | SCOM1/<br/>PAD:1 | SCOM3/<br/>PAD:1 | EXTINT:1 | | X:5 | TCC2/<br/>WO:1 | TCC0/<br/>WO:7 | | GCLK:3 |
| PA16 | 25 | SCOM1/<br/>PAD:0 | SCOM3/<br/>PAD:0 | EXTINT:0 | | X:4 | TCC2/<br/>WO:0 | TCC0/<br/>WO:6 | | GCLK:2 |
| PA15 | 24 | SCOM2/<br/>PAD:3 | SCOM4/<br/>PAD:3 | EXTINT:15 | | | TC3/<br/>WO:1  | TCC0/<br/>WO:5 | | GCLK:1 |
| PA14 | 23 | SCOM2/<br/>PAD:2 | SCOM4/<br/>PAD:2 | EXTINT:14 | | | TC3/<br/>WO:0  | TCC0/<br/>WO:4 | | GCLK:0 |

### Legende

`SERCOM`: Serial Communication, keuze tussen: USART, I²C, SPI of SMBus

`EXTINT[n]`: External Interrupts

`AIN[n]`: ADC Analog Inputs

`X[n]`, `Y[n]`: Peripheral Touch Controller - PTC Input

`TC4/WO[n]`, `TC6/WO[n]`: Waveform/PWM Outputs

`TCC3/WO[n]`: Waveform/PWM Outputs/ Capture Inputs

`AC/CMP[n]`: AC Comparator Outputs

`I2S/FS[n]`: Inter-IC Sound Controller, I²S Word Select or TDM Frame Sync

`GCLK_IO[n]`: Generic Clock (source clock or generic clock generator output)

## Bill of Materials

[Open BOM in nieuw tablad.](/schematics/assets/ibom.html  ':ignore')

[poc board bill of materials](./assets/ibom.html ':include :type=iframe width=100% height=1024px')

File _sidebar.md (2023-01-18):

* [Introduction](./README.md)

* Flexibility

  * [Boards Design](./flexibility/boards-design.md)

  * [Sensor Identification System](./flexibility/sis.md)

* Data Formatting

  * [Data Overzicht](./data-formatting/data-overzicht.md)

  * [Data Structuur](./data-formatting/data-structuur.md)

  * [Real Data](./data-formatting/real-data.md)

* Schematics

  * [Main Board with LoRaWAN](./schematics/main-board.md)

  * [Connector Board](./schematics/connector-board.md)

* PCB

  * [Main Board with LoRaWAN](./printed-circuit-boards/main-board.md)

* Embedded Programming

  * [Bare-Metal](./embedded-programming/bare-metal.md)

  * [Arduino Core](./embedded-programming/arduino-core.md)

  * [PoC Code](./embedded-programming/poc-code.md)

* Enclosure

  * [Considerations](./enclosure/considerations.md)

  * [Measuring Climate Data](./enclosure/measuring-climate.md)

  * [Solar Power](./enclosure/solar-power.md)

* Weather Station

  * [Reverse Engineering](./weather-station/reverse-engineering.md)

  * [Reading/Sending Data](./weather-station/data.md)

* Backend

  * [BaaVend](./backend/baavend.md)

  * [Linux VM](./backend/linux-vm.md)

  * [Node-RED](./backend/nodered.md)

  * [InfluxDb](./backend/influxdb.md)

  * [Mosquitto](./backend/mosquitto.md)

  * [Security](./backend/security.md)

  * [Testdata](./backend/testdata.md)

* Frontend

  * [Node-RED Dashboard](./frontend/dashboard.md)

  * [Grafana](./frontend/grafana.md)

* Demo

  * FLWSB

  * Weather Station

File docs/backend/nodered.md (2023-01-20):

# Backend

## Node-RED

Node-RED vormt het sleutelpunt van de backend. Het is een node-based omgeving voor visueel programmeren met JavaScript. Hier wordt er gesubscribed op MQTT servers voor de connectiviteit en wordt de data geformatteerd en weggeschreven naar de InfluxDb database.
Ook een deel van de frontend, het SIS web formulier, wordt hier gecodeerd.
Enkel de connectie tussen InfluxDb en Grafana gebeurt niet via Node-RED, want daar is een plug-in voor in Grafana zelf.

---

### Flows

De functionaliteiten in Node-RED worden onderverdeeld in *flows*.
Dit zijn:
 - sis-form: het Sensor Identification System (SIS) webformulier, aan de hand van Node-RED Dashboard.
 - ttn-flwsb: data verwerking voor de FLWSB-board met The Things Network (TTN).
 - ttn-sis-flwsb: data verwerking voor de FLWSB-board via The Things Network (TTN), met gebruik van SIS.
 - weather-station-sis: data verwerking voor de weerstations via de Mosquitto MQTT broker, met gebruik van SIS.
 - mqtt-logging: opslag van logging van de Mosquitto MQTT broker naar de InfluxDB database.

__*Broncode voor elke flow kan gevonden worden in deze repository onder `src\backend\node-red-flows`.
Deze kan in Node-RED geïmporteerd worden om de flow te creëren.*__

Een voorbeeld van effectieve data voor flows kan gevonden worden in [Real Data](data-formatting/real-data.md).

---

#### Sensor Identification System (SIS) Webformulier (sis-form)

Om data te kunnen ingeven in het Sensor Identification System is er een web formulier gemaakt aan de hand van Node-RED Dashboard.

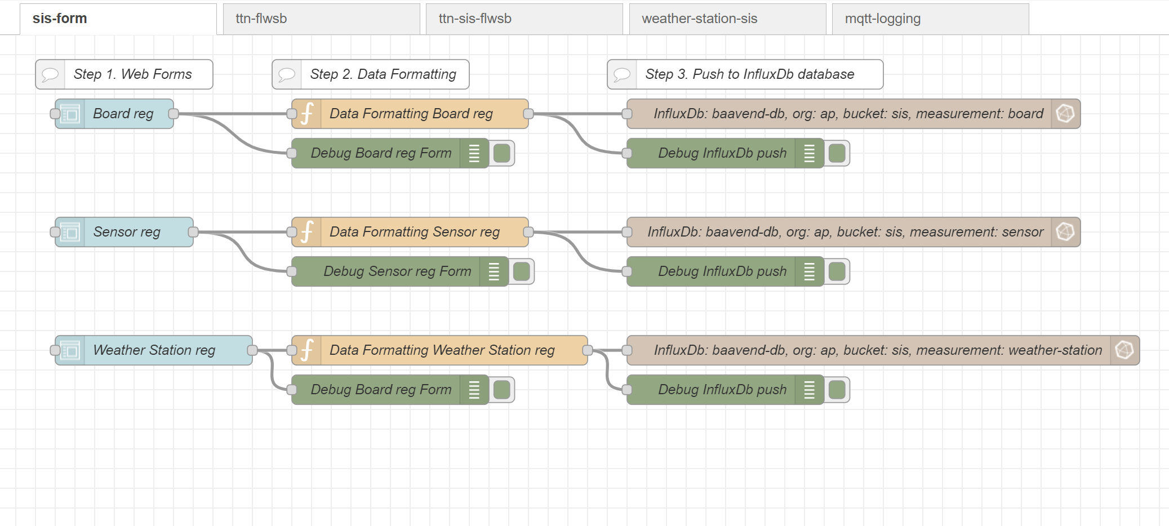
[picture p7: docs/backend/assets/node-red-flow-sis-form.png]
Node-RED flow sis-form. Figuur 1: Node-RED flow sis-form.


Deze bestaat uit:
1. [Node-Red Dashboard](https://flows.nodered.org/node/node-red-dashboard) `form` nodes (niet standaard, apart te installeren).
2. `function` nodes voor de Data Formatting.
3. `influx out` [InfluxDB nodes](https://flows.nodered.org/node/node-red-contrib-influxdb) (niet standaard, apart te installeren)

##### Web Formulier

De `form` nodes creëren volgende web pagina:

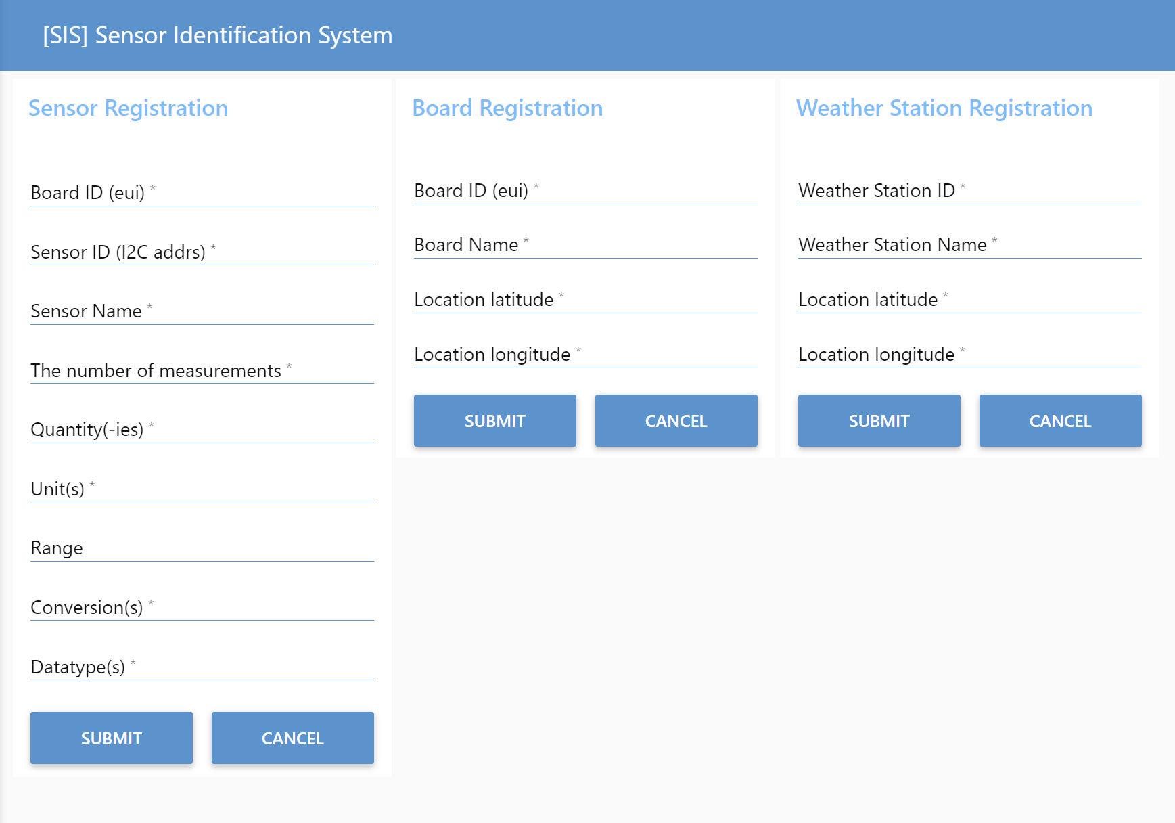
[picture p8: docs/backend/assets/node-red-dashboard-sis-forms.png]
SIS Registration Form webpagina. Figuur 2: SIS Registration Form webpagina.


##### Data Formatting

De `function` nodes bevatten volgende JavaScript code om de inkomende forms te verwerken en te formateren naar een JSON object voor de push naar InfluxDB.
Dit wordt gedaan zoals bepaald in het [Data Structuur](data-formatting/data-structuur.md) onderdeel.

###### Data Formatting Board reg

```javascript
var form = msg.payload

msg.payload = [
    {
        board_name: form.board_name,
        latitude: form.latitude,
        longitude: form.longitude,
        time: new Date()
    },
    {
        board_id: form.board_id,
    }
];

return msg;
```

###### Data Formatting Sensor reg

```javascript
var form = msg.payload

msg.payload = [
    {
        sensor_name: form.sensor_name,
        nr_of_measurements: form.nr_of_measurements,
        quantity: form.quantity,
        unit: form.unit,
        range: form.range,
        conversion: form.conversion,
        datatype: form.datatype,
        time: new Date()
    },
    {
        board_id: form.board_id,
        sensor_id: form.sensor_id,
    }
];

return msg;
```

###### Data Formatting Weather Station reg

```javascript
var form = msg.payload

msg.payload = [
    {
        name: form.name,
        latitude: form.latitude,
        longitude: form.longitude,
        time: new Date()
    },
    {
        id: form.id,
    }
];

return msg;
```

##### Push naar de InfluxDb database

Om een push te kunnen doen met de `influx out` node moeten twee zaken correct ingesteld worden:
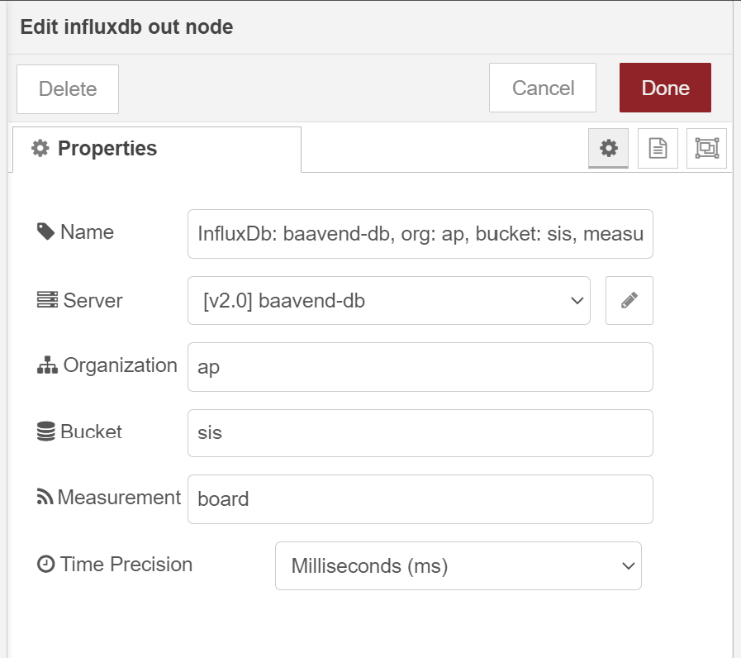
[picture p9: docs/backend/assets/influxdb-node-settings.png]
InfluxDb influx-out node instellingen voorbeeld. Figuur : InfluxDb influx-out node instellingen voorbeeld.
1. De node instellingen: 

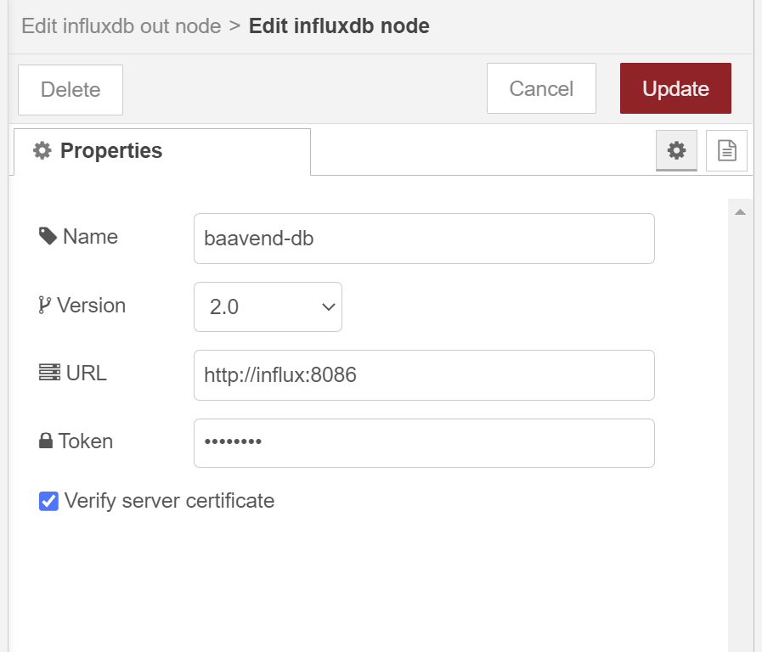
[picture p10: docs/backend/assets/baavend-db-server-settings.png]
InfluxDb server instellingen voorbeeld. Figuur : InfluxDb server instellingen voorbeeld.
2. De server instellingen: 

Hierbij is de *Bucket* vergelijkbaar met een collection of afzonderlijke database, en *Measurement* vergelijkbaar met een document of tabel.
SIS heeft zijn eigen afzonderlijke Bucket met een Measurement per groep, namelijk: board, sensor, en weather-station.

Vervolgens gebeurt de push automatisch als het inkomende bericht het juiste formaat heeft.

---

#### FLWSB-board Dataverwerking (ttn-flwsb & ttn-sis-flwsb)

Data verwerking voor FLWSB-board met gebruik van The Things Network voor LoRaWAN connectiviteit.

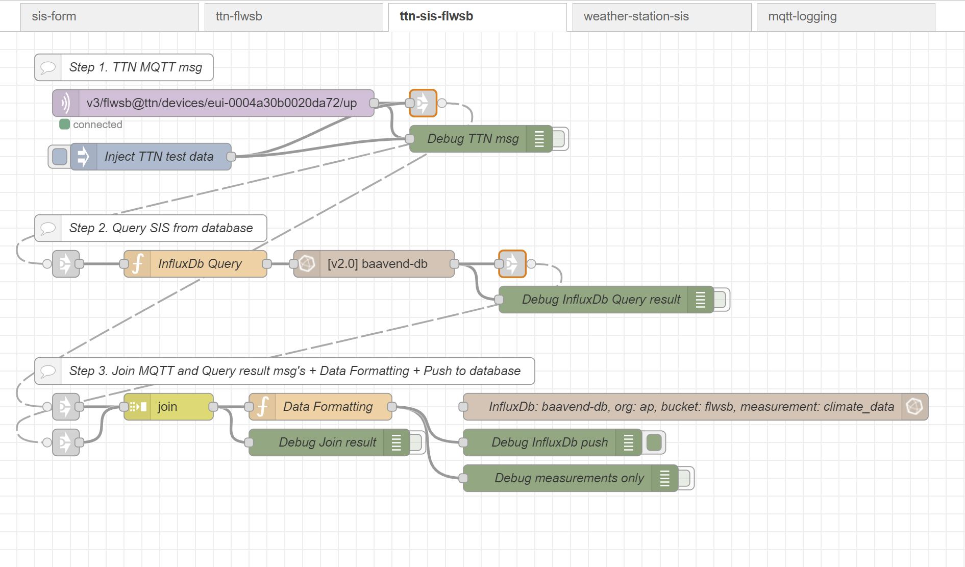
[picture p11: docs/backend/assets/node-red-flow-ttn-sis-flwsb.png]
Node-RED flow ttn-sis-flwsb. Figuur 3: Node-RED flow ttn-sis-flwsb.


Deze flow bestaat uit drie, of eerder vijf, stappen:
1. MQTT msg van de TTN applicatie.
2. Flux query naar de InfluxDb database voor SIS informatie over het board en aangesloten sensoren.
3. 3a) Samenvoeging van het MQTT bericht en het query resultaat.
4. 3b) Data Formatting.
5. 3c) Push naar InfluxDb.

##### TTN MQTT msg

Voor het FLWSB-board moet er data binnen gehaald worden over MQTT vanuit de The Things Network (TTN) applicatie.

Om te kunnen subscriben zijn er drie zaken vereist:
 - TTN server adres: eu1.cloud.thethings.network
 - TTN username: "flwsb@ttn" (applicatie-naam@ttn)
 - TTN password/API key: aan te maken in de TTN applicatie.

Meer informatie beschikbaar in de [TTN MQTT documentatie](https://www.thethingsindustries.com/docs/integrations/mqtt/).

De instellingen van de node zijn als volgt:

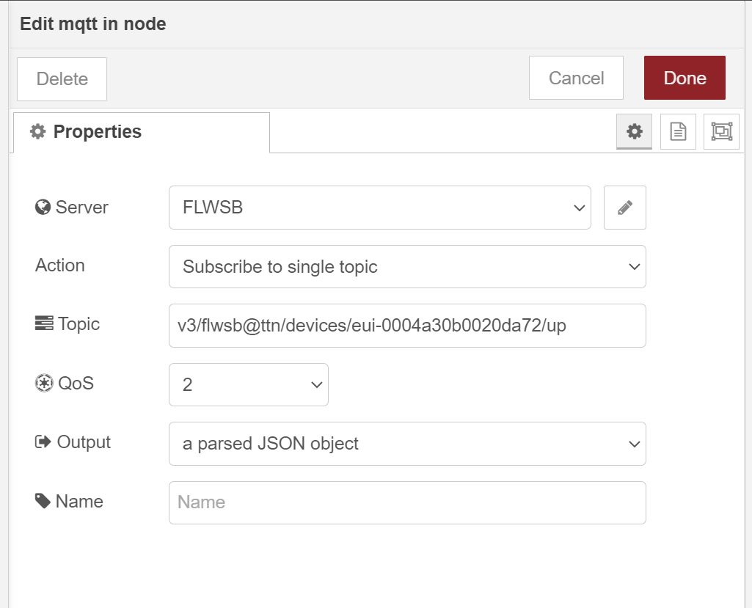
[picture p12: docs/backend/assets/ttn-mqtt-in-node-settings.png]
TTN MQTT in node instellingen. Figuur 4: TTN MQTT in node instellingen.


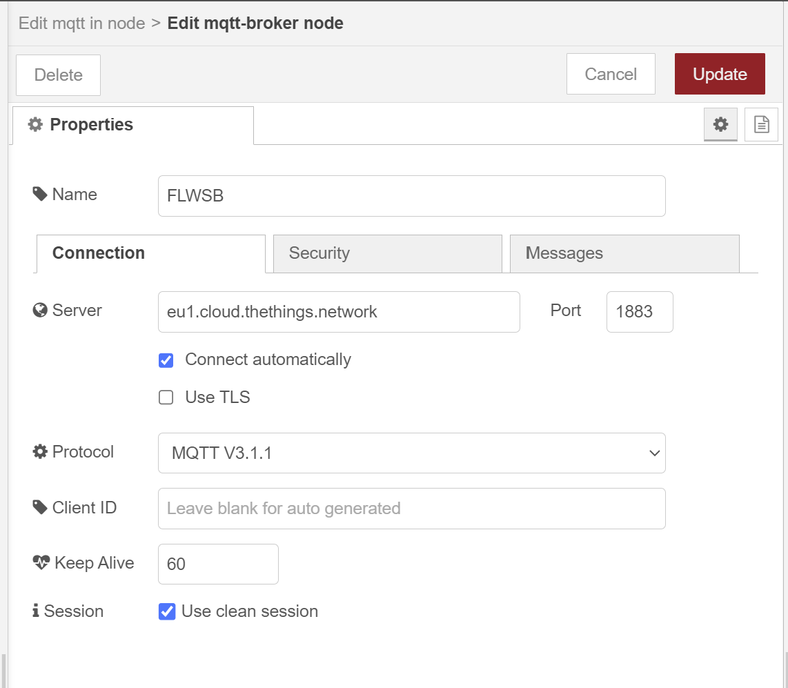
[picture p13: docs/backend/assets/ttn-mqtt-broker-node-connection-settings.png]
TTN MQTT broker node connection instellingen. Figuur 5: TTN MQTT broker node connection instellingen.


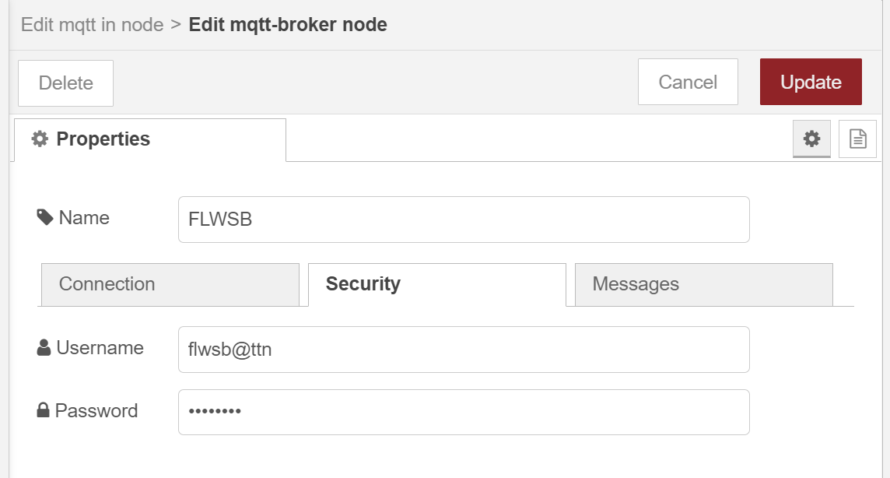
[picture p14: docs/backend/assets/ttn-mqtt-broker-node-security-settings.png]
TTN MQTT broker node security instellingen. Figuur 6: TTN MQTT broker node security instellingen.


##### Flux Query

Om data op te halen uit het SIS moet er een query gebeuren, geschreven in Flux query-taal.
Deze haalt alle nodige informatie op om de data correct te kunnen interpreteren en formateren.

```flux
const board_id = msg.payload.end_device_ids.device_id;

// Flux query
msg.query = `from(bucket: "sis")
  |> range(start: -100y, stop: now())
  |> filter(fn: (r) => r["_measurement"] == "sensor" or r["_measurement"] == "board")
  |> filter(fn: (r) => r["board_id"] == "${board_id}")
  |> filter(fn: (r) => r["_field"] == "board_name" or r["_field"] == "latitude" or r["_field"] == "longitude" or r["_field"] == "conversion" or r["_field"] == "nr_of_measurements" or r["_field"] == "quantity" or r["_field"] == "sensor_name" or r["_field"] == "datatype")
  |> aggregateWindow(every: 1y, fn: last, createEmpty: false)
  |> yield(name: "last")`

return msg;
```

##### Join

Deze node combineerd beide inkomende berichten eenvoudig weg door de msg.payload te combineren in een array.

#### Data formatting

Onderstaande code dient om een ontvangen bitstream aan de hand van het SIS te formatteren.
Er zitten echter nog fouten in, vermoedelijk een memoryleak, waardoor bij gebruik Node-RED vastloopt.

```javascript
const ttn = msg.payload[0]; // TTN MQTT msg
const sis = msg.payload[1]; // SIS query result msg

// ID & Timestamp from TTN msg
const id = ttn.end_device_ids.device_id;
const timestamp = new Date(ttn.received_at);  // timestamp TTN

// Board info from SIS query
const board_name = (sis.find(obj => obj._field == "board_name"))["_value"];
const latitude = (sis.find(obj => obj._field == "latitude"))["_value"];
const longitude = (sis.find(obj => obj._field == "longitude"))["_value"];
// node.warn(`location: ${latitude}, ${longitude}`);  // Debug info

// Bitstream
function base64ToArrayBuffer(value) {
	var load = value.replace(/\s+/g, '');  // remove any whitespace
	value = Buffer.from(load, 'base64');
	return value;
}

const bitstream = base64ToArrayBuffer(ttn.uplink_message.frm_payload);
node.warn(bitstream); // Debug info

// Sensor ID
const sensor_id = bitstream[0]; // Only for signle byte ID's
node.warn(`sensor_id: ${sensor_id}`); // Debug info

// Sensor info from SIS query by Sensor ID
const sensor_name = (sis.find(obj => obj._field == "sensor_name" && obj.sensor_id == sensor_id))["_value"];
const nr_of_measurements = (sis.find(obj => obj._field == "nr_of_measurements" && obj.sensor_id == sensor_id))["_value"];
const datatype = (sis.find(obj => obj._field == "datatype" && obj.sensor_id == sensor_id))["_value"];
const quantity = (sis.find(obj => obj._field == "quantity" && obj.sensor_id == sensor_id))["_value"];
const conversion = (sis.find(obj => obj._field == "conversion" && obj.sensor_id == sensor_id))["_value"];

// Formatting the payload for InfluxDb push
msg.payload = [
	[{
		latitude: latitude,
		longitude: longitude,
		consumed_airtime: +(ttn.uplink_message.consumed_airtime.slice(0, -1)), // remove "s" and convert to number
		time: timestamp
	},
	{
		board_id: id,  // device-id TTN en SIS
		board_name: board_name,
	}]
];

let sensor_data = [
	{
		// temp: ((((bitstream[1] << 8) + bitstream[2]) / 100) - 40),
		// pressure: ((bitstream[3] << 8) + bitstream[4]),
		// humidity: bitstream[5],
		time: timestamp
	},
	{
		board_id: id,  // device-id TTN en SIS
		sensor_id: sensor_id,
		sensor_name: sensor_name,
	}
];

if (nr_of_measurements > 1) {
	// Sensor info for multiple measurements to Arrays
	const quantities = quantity.split(", ");
	node.warn(`quantities: ${quantities}`); // Debug info
	const conversions = conversion.split(", ");
	node.warn(`conversions: ${conversions}`); // Debug info
	const datatypes = datatype.split(", ");
	node.warn(`datatypes: ${datatypes}`); // Debug info

	// Define iteration length
	let length = nr_of_measurements;
	for (let i = 1; i < length; i++) { // Skip the first byte(s) of the bitstream, the sensor_id.
		node.warn(datatypes[i]);
		if (!(datatypes[i] == "byte")) {
			length++;
		}
	}
	node.warn(`length: ${length}`); // Debug info

	// Values array
	let values = [];
	for (let i = 1; i < length; i++) { // Skip the first byte(s) of the bitstream, the sensor_id.
		node.warn(datatypes[i]);
		if (datatypes[i] == "byte") {
			values[i] = bitstream[i];
		}
		else {
			values.push((bitstream[i] << 8) + bitstream[i + 1]);
			i++;
		}
	}

	// Quantities and Measurement data to key value pairs
	for (let i = 0; i < nr_of_measurements; i++) {
		sensor_data[0][`${quantities[i]}`] = values[i];
	}

	//sensor_data[0]["test"] = ((bitstream[3] << 8) + bitstream[4]),
}
else {
	if (datatype == "byte") {
		sensor_data[0][`${quantity}`] = bitstream[1];
	}
	else {
		sensor_data[0][`${quantity}`] = (bitstream[1] << 8) + bitstream[2];
	}
}

node.warn(sensor_data[0]); // Debug info
msg.payload.push(sensor_data);

return msg;
```

##### PoC Flow

Een vereenvoudigde versie van de flow specifiek voor de SAMDaaNo21 Proof-of-Concept verbonden met een BME280:

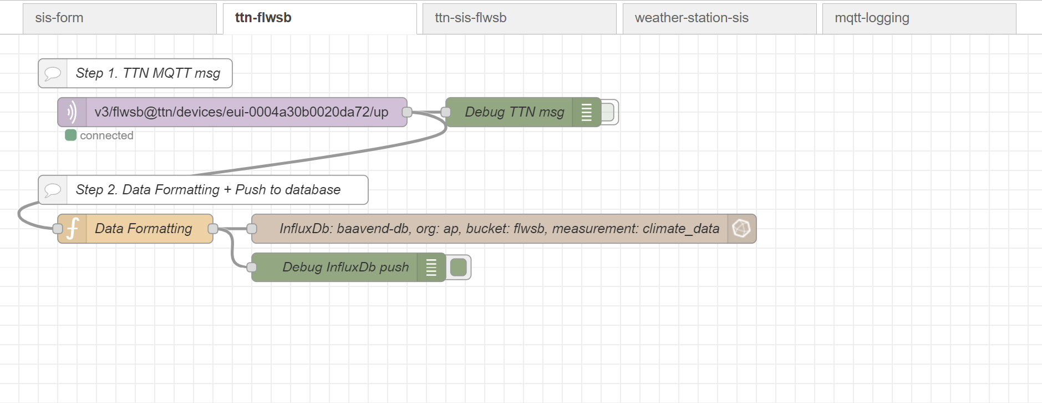
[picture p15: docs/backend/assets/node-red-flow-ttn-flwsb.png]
Node-RED flow ttn-flwsb. Figuur 7: Node-RED flow ttn-flwsb.


---

#### Weerstations Dataverwerking (weather-station-sis)

Data verwerking voor de weerstations.

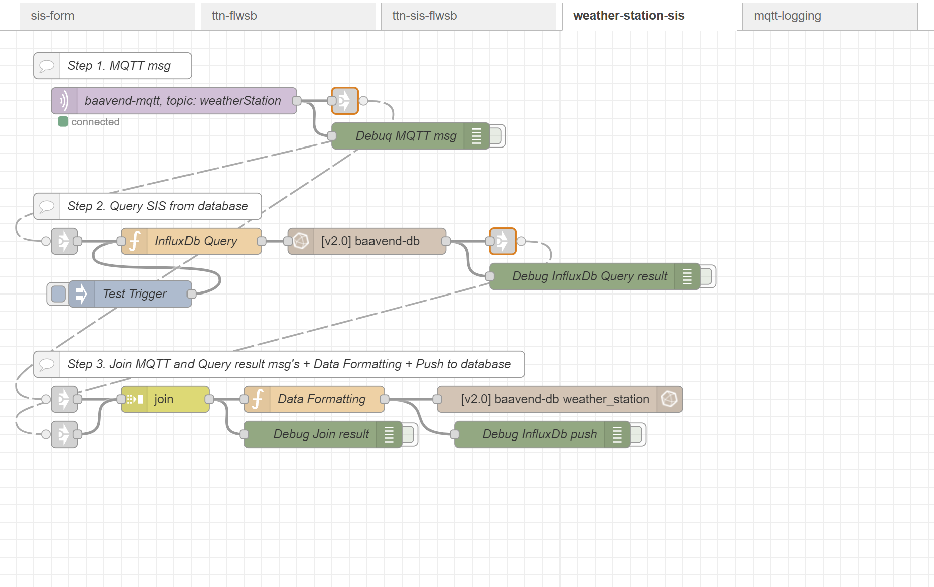
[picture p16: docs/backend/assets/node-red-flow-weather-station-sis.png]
Node-RED flow weather-station-sis. Figuur 8: Node-RED flow weather-station-sis.


Deze flow gebeurt zeer gelijkaardig aan de *ttn-sis-flwsb* flow.

##### Mosquitto MQTT

De instellingen van de MQTT node zijn als volgt:

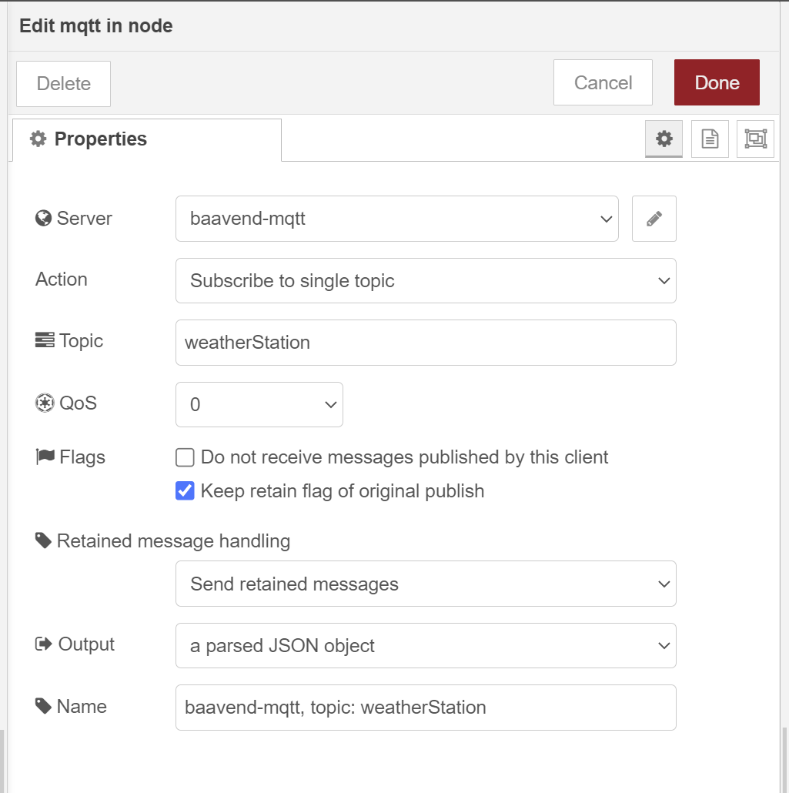
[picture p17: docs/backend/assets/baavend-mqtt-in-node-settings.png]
Mosquitto MQTT (baavend-mqtt) in node instellingen. Figuur 9: Mosquitto MQTT (baavend-mqtt) in node instellingen.


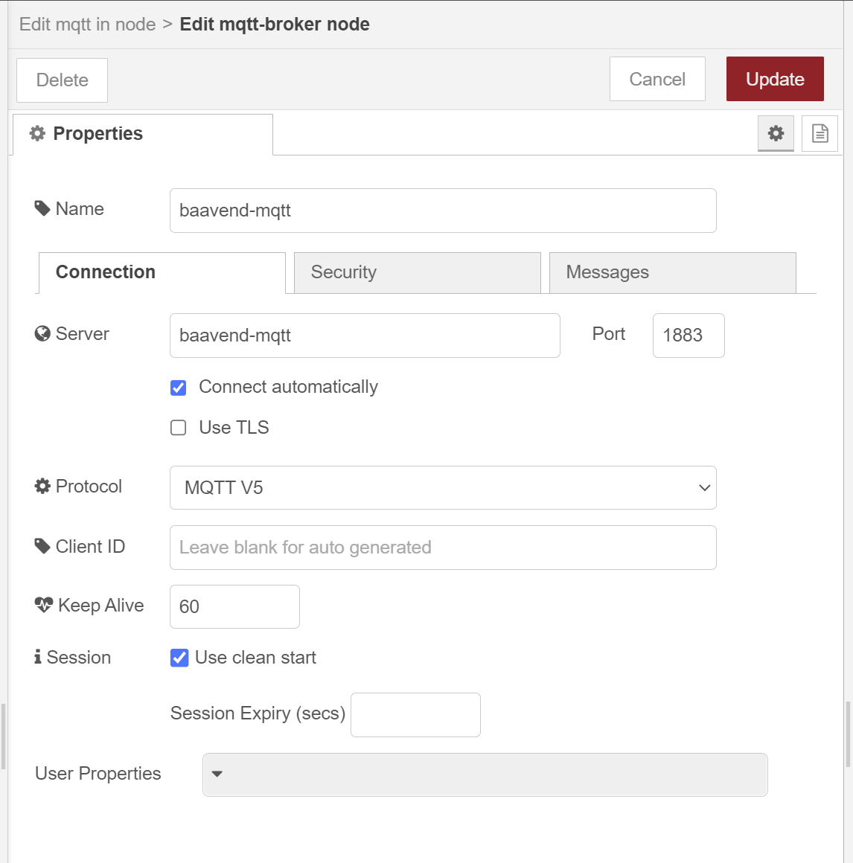
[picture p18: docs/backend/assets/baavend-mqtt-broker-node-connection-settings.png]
Mosquitto MQTT (baavend-mqtt) broker node connection instellingen. Figuur 10: Mosquitto MQTT (baavend-mqtt) broker node connection instellingen.


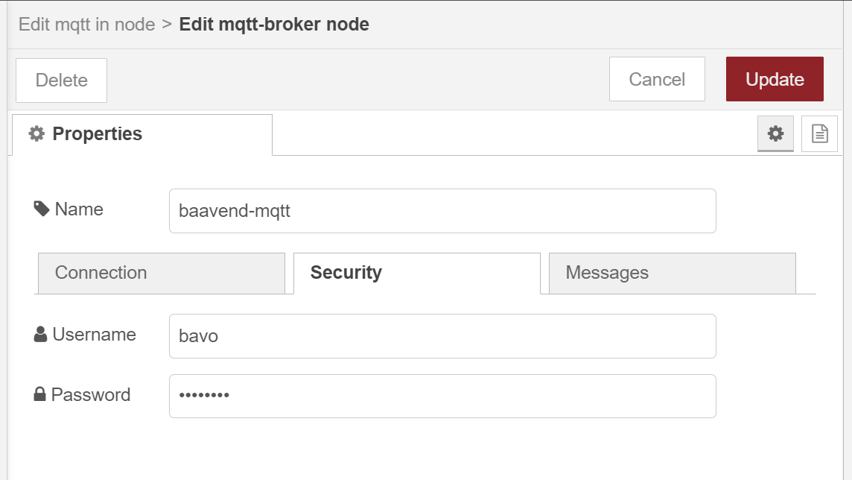
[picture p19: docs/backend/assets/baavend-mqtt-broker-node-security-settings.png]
Mosquitto MQTT (baavend-mqtt) broker node security instellingen. Figuur 11: Mosquitto MQTT (baavend-mqtt) broker node security instellingen.


##### Flux Query

```flux
msg.query = `from(bucket: "sis")
  |> range(start: -100y, stop: now())
  |> filter(fn: (r) => r["_measurement"] == "weather-station")
  |> filter(fn: (r) => r["_field"] == "name")
  |> aggregateWindow(every: 1y, fn: last, createEmpty: false)
  |> yield(name: "last")`

return msg;
```

##### Data formatting

```javascript
let mqtt = msg.payload[0];
let sis = msg.payload[1];

let source_id = (sis.find(obj => obj.id == mqtt.id))["_value"];

msg.payload = [
	{
		temp: mqtt.temperature_C,          // buiten temperatuur, °C, float
		humidity: mqtt.humidity,           // buiten luchtvochtigheid, %, int
		wind_speed: mqtt.wind_avg_m_s,     // windsnelheid, m/s, float
		wind_gust: mqtt.wind_max_m_s,      // windsnelheid, m/s, float
		wind_direction: mqtt.wind_dir_deg, // windrichting, hoek in graden °, int
		rain: mqtt.rain_mm,                // neerslag, mm/10min, float
		time: new Date(mqtt.time)		  // timestamp, YYYY-MM-DD hh:mm:ss
	},
	{
		source: source_id
	}];

return msg;
```

---

#### Mosquitto MQTT Broker Logging (mqtt-logging)

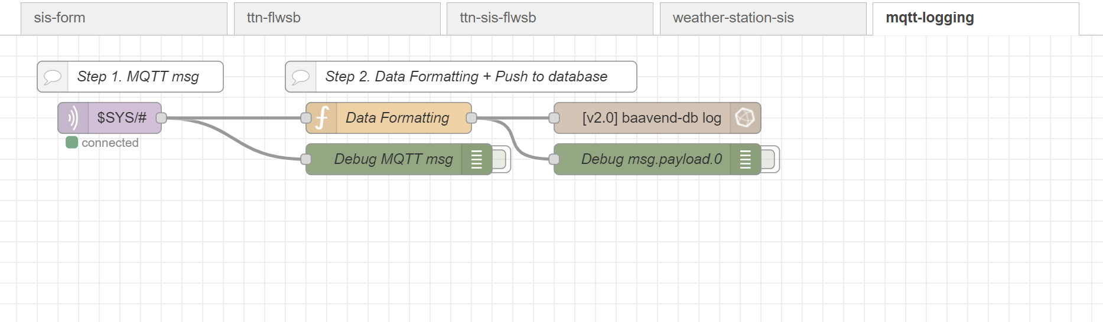
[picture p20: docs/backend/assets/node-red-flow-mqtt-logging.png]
Node-RED flow mqtt-logging. Figuur 12: Node-RED flow mqtt-logging.


```javascript

```

---

### Troubleshooting

#### Docker op Linux Virtual Machine

Bij het opstarten van de Node-RED container op een Linux Virtual Machine kan je stuiten op volgende error:

```bash
baavend-red  | <date time> - [error] Failed to start server:
baavend-red  | <date time> - [error] Error: EACCES: permission denied, mkdir '/data/node_modules'
```

Dit gebeurt omdat er volumes gemount worden en de user van de Docker container geen rechten heeft om in de directories van de host user te schrijven.
Voor Node-RED is de container user uid 1000. Om deze error op te lossen moet er dus schrijf rechten gegeven worden aan deze uid, zoals beschreven in [deze oplossing op stackoverflow](https://stackoverflow.com/questions/74487200/can-i-run-node-red-under-docker-on-vm-eflow-azure-iot-edge-on-windows-device/74488060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).
Voor baavend-red wordt dit commando:

```bash
sudo chown -R 1000:1000 ~/baavend/baavend-red/
```

#### Credentials error bij Deployment

Bij het herstarten van docker krijg je een error over dat de credentials decryption niet lukt en dat er nieuwe credentials gemaakt worden met `$$$` achtervoegsel.

Errors:
```bash
"Flushing file /data/flows_cred.json to disk failed : Error: EBUSY: resource busy or locked, rename '/data/flows_cred.json.$$$' -> '/data/flows_cred.json'"

"Error saving flows: EBUSY: resource busy or locked, rename '/data/flows_cred.json.$$$' -> '/data/flows_cred.json'"
```

Voer de volgende commandos uit om deze te kunnen gebruiken en terug te kunnen deployen.

```bash
rm flows.json
rm flows_cred.json
cp 'flows.json.$$$' flows.json
cp 'flows_cred.json.$$$' flows_cred.json
hmod +x flows.json
chmod +x flows_cred.json
```

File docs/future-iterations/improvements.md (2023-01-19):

# Toekomstige Iteraties

## Mogelijke verbeteringen en uitbreidingen

In dit onderdeel wordt er bekeken wat er nog kan komen aan verbeteringen en uitbreidingen in volgende iteraties van het project.

### SAMDaaNo21

- Momenteel zijn er geen mounting holes aanwezig, dat vonden we nog niet prioritair.
  - Mouning holes of inkepingen aan de randen van de printplaat zijn dus nog mogelijk en kunnen ook zeker van pas komen.
  - Een printplaat in de stijl van de Arduino Nano Every lijkt ons ook interessant. Dan zouden er geen componenten op de onderkant kunnen staan en zorgen we voor rat-bites aan de zijkant van de printplaat. Op deze manier kan de PCB gebruikt worden als SMD-component.
- De impedantie van het pad naar de antenne-aansluiting is niet theoretisch berekend. Dit is iets waar in een volgende versie over kan worden nagedacht.
- LED's toevoegen voor visuele feddback, vb power LED. Nu nog geen aanwezig op SAMDaaNo21 zelf.
- Op het silkscreen staat een fout, `PA07` staat op het silkscreen als `PA09`. 
- Het schema bevat een fout die de LoRaWAN module onbruikbaar maakt. RX en TX van de UART-verbinding moeten omgewisseld worden.

### Arduino Core

- In het `Tools` menu van de Arduino IDE kunnen nog instellingen worden toegevoegd zoals kloksnelheid.
- Echte release maken zodat de boards via de Board Manager geïnstalleerd worden zoals bij de ESP32.

### Embedded Programming

- SIS implementeren

### Connector Board en Behuizing

- Behuizing ontwerpen of aankopen dat geschikt is voor deployment in Tanzania en Ghana met zonnepanelen. Reeds onderzocht in hoofdstuk Enclosure/Behuizing.
- Connector Board PCB ontwerpen samen met behuizing.
- Eigen implementatie van de Solar Power Manager in het Connector Board zelf.

### Weerstations

- Analyse naar de correctheid van de verkregen data uit de gebruikte applicatie.
- Onderzoek naar hoe deze data juist/beter visualiseren.

### Backend

- SIS niet volledig geïmplementeerd geraakt. De ttn-sis-flwsb flow in Node-RED is onvolledig, doet nog geen conversies. Er zit zelfs vermoedelijk een dataleak in waardoor Node-RED vast loopt wanneer er data in komt.
- MQTT topic van TTN veresit een specifiek device. Hierdoor is er een flow per device nodig. In de eerste iteratie van het Zanzibar project is er voor dit probleem een script ontwikkeld. Deze kan ook hier toegepast worden, mits aanpassingen.
- TLS/SSL beveiliging implementeren voor gebruik van HTTPS.
- Automatische backup functionaliteit voor InfluxDb. Mogelijk met ingebouwd commando mits TLS werkt.
- Weerstations pushen nu op de zoveel seconden data in twee verschillende vormen. Dit zorgt voor onnodige belasting en mogelijks foutieve data. De MQTT msg's kunnen in Node-RED over een bepaalde tijdspanne verzameld worden, zodat na een bepaalde periode, vb elk half uur, een gemiddelde kan berekend worden en een volledige push kan gebeuren naar de database, zonder *undefined* waarden.

### Frontend

- Uitbreiden SIS web form met tooltips en voorbeelden.
- Validatie van ingevoerde data in het SIS web form.
- Grafana dashboards opbouwen geschikt voor de te visualiseren data, vb. windroos voor windrichting.

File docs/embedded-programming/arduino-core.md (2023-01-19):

# Embedded Programming

## Arduino core

SAMDaaNo21 toevoegen aan de Arduino IDE.

Om de SAMDaaNo21 werkende te krijgen met een IDE zoals die van Arduino moeten we eerst een compatibele bootloader op de MCU hebben staan. Wij maken gebruik van de ATSAMD21G16B en spijtig genoeg zijn hier geen kant-en-klare bootloaders voor. Omdat we de printplaat zelf hebben ontworpen zijn er uiteraard ook geen volledig compatibele configuraties beschikbaar.

Het toevoegen voor ondersteuning verloopt in een aantal stappen:

- Bootloader voor de [ATSAMD21G16B](https://www.microchip.com/en-us/product/ATSAMD21G16) vinden
- Bootloader flashen
- Een Arduino variant toevoegen voor de SAMDaaNo21
  - Linker script aanpassen
  - OpenOCD script aanpassen
  - Pinout en functies definiëren

Bij deze stappen hebben we ons gebaseerd op de Arduino Zero. Deze heeft echter een ATSAMD21G18A, dat is een variant met meer geheugen.

Alle nodige broncode is te verkrijgen van de [ArduinoCore-samd](https://github.com/arduino/ArduinoCore-samd) GitHub repository. ([Onze fork specifiek voor de SAMDaaNo21](https://github.com/DaanDekoningKrekels/ArduinoCore-samd))

Belangrijke mappen en bestanden:

| Naam | Beschrijving |
| --- | --- |
| bootloaders/ | Map met bootloader broncode voor alle type Arduino's. |
| variants/ | Map met broncode voor alle verschillende varianten van Arduino's om compatibel te zijn met de Arduino bibliotheken. |
| boards.txt | Bestand met definities en instellingen voor Arduino borden weer te geven in de Arduino IDE onder `tools`-> `board: xxx` |

## Bootloader

### Adafruit UF-2

Eerst leek het ons interessant om de Adafruit bootloader aan te passen aan de SAMDaaNo21. Die maakt het gemakkelijk om met de Arduino IDE te werken maar ook om met CircuitPython.

https://github.com/DaanDekoningKrekels/uf2-samdx1

https://learn.adafruit.com/adafruit-feather-m4-express-atsamd51/uf2-bootloader-details

De UF2 bootloader van Adafruit is BOSSA compatible, wat wil zeggen dat deze ook werkt met de Arduino IDE. Spijtig genoeg is het ons niet gelukt om een werkende versie van deze bootloader te compileren.

### Arduino Core voor SAMD21 CPU

Hiervoor speelt alles zich af in een vroegere versie van de [./bootloaders/](https://github.com/DaanDekoningKrekels/ArduinoCore-samd/tree/d43b5cc60e3d2cf1adc67d0252b6663a6e49250b/bootloaders/samdaano21) folder op de GitHub repo. 

In de meest recente versie zal er enkel de Microchip bootloader te vinden zijn en de bestanden om deze te flashen. 

We hebben de folder van de Arduino Zero `zero/` gedupliceerd en hernoemd naar `samdaano21/`.

Belangrijke bestanden:

| Naam | Beschrijving |
| --- | --- |
| Makefile | Beschrijft alle instellingen voor de compiler. |
| board_definitions.h | Lijst de verschillende borden op. |
| board_definitions_samdaano21.h | Bestand gebaseerd op board_definitions_zero.h, specifiek voor de SAMDaaNo21. Bevat instellingen voor de bootloader zoals USB VID, PID en CPU frequentie. |
| bootloader_samd21x16.ld | Bestand gebaseerd op bootloader_samd21x18.ld, is een linker script waar onder andere de geheugen regio's in worden beschreven. |

#### Board definitions

We dupliceren `board_definitions_zero.h` en hernoemen de kopie naar `board_definitions_samdaano21.h`. 

In dit bestand passen we enkel de USB-instellingen aan en het `BOOT_DOUBLE_TAP_ADDRESS`. Dat adres is afhankelijk van de hoeveelheid ram. Op het moment dat er dubbel gedrukt wordt op de RESET knop, zal de bootloader in de laatste 4 bytes van het geheugen uitvoeren. Het adres is dus de totale RAM - 4 bytes. $8\text{kb} - 4\text{b} = 0\text{x}2000 - 0\text{x}4 = 0\text{x}1FFC$

`board_definitions_samdaano21.h`

```c
[...]
/*
 * USB device definitions
 */
#define STRING_PRODUCT "SAMDaaNo21"
#define USB_VID_HIGH   0x03     // Atmel
#define USB_VID_LOW    0xEB
#define USB_PID_HIGH   0x24     // Generic HID device
#define USB_PID_LOW    0x02
/*
 * If BOOT_DOUBLE_TAP_ADDRESS is defined the bootloader is started by
 * quickly tapping two times on the reset button.
 * BOOT_DOUBLE_TAP_ADDRESS must point to a free SRAM cell that must not
 * be touched from the loaded application.
 */
//#define BOOT_DOUBLE_TAP_ADDRESS           (0x20007FFCul)
// https://forum.arduino.cc/t/how-to-upload-arduino-bootloader-to-a-custom-samd21-usig-jlink-mini/906434/13
#define BOOT_DOUBLE_TAP_ADDRESS           (0x20001FFCul) // 8kb ram - 4 bytes = 10x8188 0x1FFC
#define BOOT_DOUBLE_TAP_DATA              (*((volatile uint32_t *) BOOT_DOUBLE_TAP_ADDRESS))
[...]
```

`board_definitions.h` moet nu aangepast worden om ons nieuwe bestand te kunnen includen.

Pas het volgende aan:

`board_definitions.h`

```c
#if defined(BOARD_ID_samdaano21)
  #include "board_definitions_samdaano21.h"
#elif defined(BOARD_ID_arduino_zero)
  #include "board_definitions_arduino_zero.h"
[...]
```

#### Linker script

Referentie: https://forum.arduino.cc/t/how-to-upload-arduino-bootloader-to-a-custom-samd21-usig-jlink-mini/906434/11

Zeer goede documentatie: https://blog.thea.codes/the-most-thoroughly-commented-linker-script/

`bootloader_samd21x18.ld` -> `bootloader_samd21x16.ld `

Dit is het linker script. Daarin is enkel de memory mapping aangepast. De ATSAMD21x18 versie heeft 256kb flash en 32kb SRAM. De ATSAMD21x16 heeft 64kb flash en 8kb SRAM. Deze waardes zijn hexadecimaal in het linker script geplaatst.

`bootloader_samd21x16.ld`

```c
MEMORY
{
  FLASH (rx) : ORIGIN = 0x00000000, LENGTH = 0x2000 /* First 8KB used by bootloader */
  RAM (rwx) : ORIGIN = 0x20000000, LENGTH = 0x00002000-0x0400 /* last 4 bytes used by bootloader to keep data between resets, but reserves 1024 bytes for sketches to have same possibility */
}
```

#### Makefile

De makefile geeft de compiler de juiste instructies om de bootloader te kunnen samenstellen. Hier passen we het `BOARD_ID` aan, de verwijzing naar het `LD_SCRIPT` en veranderen bij compiler options de MCU van G18A naar G16A.

`Makefile`

```makefile
[...]
# Boards definitions
BOARD_ID?=samdaano21
[...]
CFLAGS_EXTRA=-D__SAMD21G16A__ -DBOARD_ID_$(BOARD_ID) -D$(SAM_BA_INTERFACES)
[...]
LD_SCRIPT=bootloader_samd21x16.ld
[...]
```

#### Compileren

Met het commando `make clean all` kan de gehele bootloader gecompileerd worden.

Er zal een `samd21_sam_ba.hex` en een `samd21_sam_ba.bin` bestand aangemaakt worden.

#### Problemen

Het had fijn geweest moest het werk geloond hebben, maar deze bootloader hebben we niet werkende gekregen. Het lukte niet om via de Arduino IDE code te uploaden naar de SAMDaaNo21. Via een programmer lukte het echter wel om bootloader + code te draaien.

Als alternatief zijn we terechtgekomen bij de standaard bootloader die Microchip aanbiedt voor hun SAMD lijn, de SAM-BA bootloader. 

SAM-BA maakt het mogelijk om via USB te communiceren met een AT SAM microcontroller. Op deze manier is er geen externe programmer nodig!

Wetende dat deze bootloader bestaat, is het enkel nog zoeken naar de download link... Alle verwijzingen in de volgende PDF's zien er als volgt uit:

>The user guide comes with the SAM-BA package available on www.atmel.com.

Enkele links over SAM-BA (SAM Boot Assist):

-  [AN_42438 - AT09423: SAM-BA Overview and Customization Process (PDF)](https://ww1.microchip.com/downloads/en/DeviceDoc/Atmel-42438-SAM-BA-Overview-and-Customization-Process_ApplicationNote_AT09423.pdf) 
-  [AN_42366 - AT07175: SAM-BA Bootloader for SAM D21 (PDF)](https://ww1.microchip.com/downloads/en/DeviceDoc/Atmel-42366-SAM-BA-Bootloader-for-SAM-D21_ApplicationNote_AT07175.pdf)
-  [AN_42728 - AT15004:Using SAM-BA for Linux on SAM Devices (PDF)](https://ww1.microchip.com/downloads/en/DeviceDoc/Atmel-42728-Using-SAM-BA-for-Linux-on-SMART-ARM-based-Microcontrollers_ApplicationNotes_AT15004.pdf) 
-  [SAM-BA Monitor for ROMless Cortex M Devices - SAM-BA® Monitor for ROMless Cortex Devices Application Note (PDF)](https://ww1.microchip.com/downloads/en/DeviceDoc/00002565A.pdf) 
-  [How to Customize ASFv3 SAM-BA Bootloader on Cortex- (PDF)](https://ww1.microchip.com/downloads/en/DeviceDoc/How-to-Customize-ASFv3-SAM-BA-Bootloade-on-Cortex-M0-Microcontrollers-DS90003190A.pdf) 
-  [Where can I download the official ATSAM D21 bootloader and how to burn it??](https://www.avrfreaks.net/s/topic/a5C3l000000Uiu3EAC/t185718)
-  [SAM-BA Bootloader for SAMD21G15B](https://www.avrfreaks.net/s/topic/a5C3l000000Uf3qEAC/t170949)
-  [SAM-BA Bootloader! (ZIP)](http://ww1.microchip.com/downloads/en/DeviceDoc/Atmel-42366-SAM-BA-Bootloader-for-SAM-D21_ApplicationNote_AT07175.zip)

De laatste link gaat rechtstreeks naar de download van de bootloader. De inhoud zit er als volgt uit:

```
.
├── LED_Toggle_0x1000.bin
├── LED_Toggle_0x2000.bin
├── load sam-ba
│   ├── samd21e15a
│   ├── samd21e16a
│   ├── samd21e17a
│   ├── samd21e18a
│   ├── samd21g15a
│   ├── samd21g16a
│   │   ├── samd21_sam_ba_both_interfaces.hex
│   │   ├── samd21_sam_ba_uart.hex
│   │   └── samd21_sam_ba_usbcdc.hex
│   ├── samd21g17a
│   ├── samd21g18a
│   ├── samd21j15a
│   ├── samd21j16a
│   ├── samd21j17a
│   └── samd21j18a
└── sam-ba_monitor.zip
```

Enkel de bootloader `samd21_sam_ba_both_interfaces.hex` in de map `samd21g16a` is voor ons van toepassing. Met deze bootloader werkt uploaden vanaf de Arduino IDE!

Hoe je deze bootloader kan flashen kan je [hier](bootloader-flashen.md) lezen.

Een belangrijke kanttekening: De Arduino IDE gebruikt de programmerings-tool [BOSSA](https://github.com/shumatech/BOSSA) om binaries naar een SAM-BA apparaat te sturen. Deze tool ondersteunt standaard de ATSAMD21G16 **niet**. Om die reden moet een [aangepaste versie van BOSSA](https://github.com/mattairtech/BOSSA) gebruikt worden, namelijk deze van Justin Mattair (mattairtech).

Nu we een bootloader hebben, moet deze naar de SAMDaaNo21 geschreven worden. Zie documentatie in het volgende hoofdstuk.

## Arduino variant

Wanneer de bootloader op de SAMDaaNo21 straat en je sluit de USB-poort aan, zal je onder `tools`-> `port` een apparaat zien staan!

We kunnen echter nog niets programmeren naar de SAMDaaNo21 omdat de Arduino IDE niet weet hoe het apparaat werkt. In de volgende stappen voegen we een Arduino variant toe aan de IDE.

Hiervoor speelt het meeste zich af in de `./variants/` folder van de GitHub repo, `boards.txt` passen we ook aan.

| Naam | Beschrijving |
| --- | --- |
| boards.txt | Bestand met definities en instellingen voor Arduino borden weer te geven in de Arduino IDE onder `tools`-> `board: xxx` |
| variants/samdaano21/ | |
| [variant.h](https://github.com/DaanDekoningKrekels/ArduinoCore-samd/blob/master/variants/samdaano21/variant.h) | Bestand waar alle pin-namen die via de Arduino IDE aanspreekbaar zijn worden gedefinieerd. |
| [variant.cpp](https://github.com/DaanDekoningKrekels/ArduinoCore-samd/blob/master/variants/samdaano21/variant.cpp) | Bestand waar alle beschikbare pinnen en hun functies in één array worden samengebracht. |
| openocd_scripts/samdaano21.cfg | OpenOCD script om te communiceren met de MCU. |
| linker_scripts/gcc/flash_with_bootloader.ld | Linker script dat wederom de geheugen regio's weergeeft, ditmaal met een offset van 8kb om de bootloader niet te overschrijven. |
| linker_scripts/gcc/flash_without_bootloader.ld | Linker script dat wederom de geheugen regio's weergeeft. |

### variant.cpp en variant.h

In het `variant.cpp` bestand zit een grote array waarin iedere bruikbare pin definitie wordt bijgehouden. De opties voor individuele pinnen zijn gedefinieerd in `WVariant.h`, dat bestand kan je vinden in de core folder.

Per pin op de SAMDaaNo21 zijn er functies die toegewezen worden. Om de juiste functies toe te wijzen aan de pinnen refereer je naar de [datasheet](https://ww1.microchip.com/downloads/en/DeviceDoc/SAM-D21DA1-Family-Data-Sheet-DS40001882G.pdf) hoofdstuk 7 I/O Multiplexing and Considerations. Mogelijke functies:

[`WVariant.h`](https://github.com/DaanDekoningKrekels/ArduinoCore-samd/blob/master/cores/arduino/WVariant.h#L201)

```cpp
/* Types used for the table below */
typedef struct _PinDescription
{
  EPortType       ulPort ;
  uint32_t        ulPin ;
  EPioType        ulPinType ;
  uint32_t        ulPinAttribute ;
  EAnalogChannel  ulADCChannelNumber ; /* ADC Channel number in the SAM device */
  EPWMChannel     ulPWMChannel ;
  ETCChannel      ulTCChannel ;
  EExt_Interrupts ulExtInt ;
} PinDescription ;
```

Deze functies worden in [`variant.cpp`](https://github.com/DaanDekoningKrekels/ArduinoCore-samd/blob/master/variants/samdaano21/variant.cpp) op volgende manier weergegeven:

```cpp
{ PORTA,  2, PIO_ANALOG, PIN_ATTR_ANALOG, ADC_Channel0, NOT_ON_PWM, NOT_ON_TIMER, EXTERNAL_INT_2 }, // ADC/AIN[0]
```

PA02 is dus een analoge pin die gebruik maakt van ADC:0. Er is geen PWM mogelijkheid en geen timer, wel een externe interrupt EXTINT:2.

Bovenstaande lijn code staat op index 0 van de `g_APinDescription` array. In [`variant.h`](https://github.com/DaanDekoningKrekels/ArduinoCore-samd/blob/master/variants/samdaano21/variant.h) moet de pin daar nog worden ingesteld als analoge pin.

[`variant.h`](https://github.com/DaanDekoningKrekels/ArduinoCore-samd/blob/master/variants/samdaano21/variant.h)

```cpp
/*
 * Analog pins
 */
#define PIN_A0               (0ul) // Index 0 van eerdere voorbeeldcode
#define PIN_A1               (1ul)
#define PIN_A2               (2ul)
#define PIN_A3               (3ul)
#define PIN_A4               (6ul)
#define PIN_A5               (14ul)
#define PIN_DAC0             (26ul)

static const uint8_t A0  = PIN_A0;
static const uint8_t A1  = PIN_A1;
static const uint8_t A2  = PIN_A2;
static const uint8_t A3  = PIN_A3;
static const uint8_t A4  = PIN_A4;
static const uint8_t A5  = PIN_A5;
static const uint8_t DAC0 = PIN_DAC0;
#define ADC_RESOLUTION		12
```

Op deze manier worden de pinnen gedefinieerd voor Arduino code. Nu kan er gebruik gemaakt worden van `A0` in de code om een analoge pin uit te lezen.

Om gebruik van de SAMDaaNo21 gemakkelijker te maken zijn alle pinnen die omschreven zijn op de slikscreen (PCB zelf) ook voorgedefinieerd.

**Let op dat `PA07` op de slikscreen staat aangegeven als `PA09`. Dit is een fout die in versie 2 zal worden rechtgezet.**

```cpp
#define PA02        (0ul)
#define PA03        (1ul)
#define PB08        (2ul)
#define PB09        (3ul)
#define PA04        (4ul)
#define PA05        (5ul)
#define S0TX        (4ul) // TX SERCOM0 UART
#define S0RX        (5ul) // RX
#define PA06        (6ul)
#define PA07        (7ul)
#define PA08        (8ul)
#define PA09        (9ul)
#define S2TX        (8ul) // TX SECOM 2 UART
#define S2RX        (9ul) // RX
#define PA10        (10ul)
#define PA11        (11ul)
#define PA12        (12ul)
#define PA13        (13ul)
#define S4SDA       (12ul) // SDA SERCOM 4 I2C
#define S4SCL       (13ul) // SCL

// Andere kant
#define PB03        (14ul)
#define PB22        (15ul)
#define PA23        (16ul)
#define PA22        (17ul)
#define S5RX        (16ul) // RX SERCOM 5 UART
#define S5TX        (17ul) // TX
#define PA21        (18ul)
#define PA20        (19ul)
#define PA19        (20ul)
#define PA18        (21ul)
#define PA17        (22ul)
#define PA16        (23ul)
#define S3SS        (20ul) // SS SERCOM 3 SPI
#define S3MISO      (21ul) // MISO
#define S3SCK       (22ul) // SCK
#define S3MOSI      (23ul) // MOSI
#define PA15        (24ul)
#define PA14        (25ul)
```

Ook de SERCOM poorten zijn in dit bestand geformuleerd.

## Mogelijke verbeteringen en uitbreidingen

- In het `Tools` menu van de Arduino IDE kunnen nog instellingen worden toegevoegd zoals kloksnelheid.
- Echte release maken zodat de boards via de Board Manager geïnstalleerd worden zoals bij de ESP32.

## Bronnen

- S. (2016, 30 juli). Porting Arduino Zero to another samd21g variant. Arduino Forum. https://forum.arduino.cc/t/porting-arduino-zero-to-another-samd21g-variant/400138/3
- Instructables. (2019, 15 mei). Arduino IDE: Creating Custom Boards. https://www.instructables.com/Arduino-IDE-Creating-Custom-Boards/
- Docs: How the variant system works on Arduino Zero boards | Details | Hackaday.io. (z.d.). https://hackaday.io/project/8007-hack/log/41354-docs-how-the-variant-system-works-on-arduino-zero-boards
- Smart | Connected | Secure | Microchip Technology. (z.d.). https://www.microchip.com/
- H. (2021, 18 september). How to upload arduino bootloader to a custom samd21 usig Jlink mini. Arduino Forum. https://forum.arduino.cc/t/how-to-upload-arduino-bootloader-to-a-custom-samd21-usig-jlink-mini/906434/11
- Adafruit Feather M4 Express. (2018, 11 juli). Adafruit Learning System. https://learn.adafruit.com/adafruit-feather-m4-express-atsamd51/uf2-bootloader-details

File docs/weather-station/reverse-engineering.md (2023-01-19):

# Weerstation

## Reverse Engineering Onderzoek

### Introductie

Om snel aan bruikbare data te geraken maken we gebruik van een bestaand draadloos weerstation.
Dit is de [Alecto WS-4800](https://alectohome.nl/products/alecto-ws-4800-professioneel-weerstation-met-draadloze-buitensensor-wit) wat eigenlijk een Nederlandse rebranding is van de [Bresser 5-in-1 New](https://www.bresser.de/nl/bresser-bresser-3/Weercenters/BRESSER-Weather-Center-5-in-1-wit.html).
Deze werkt aan de hand van 868MHz waarmee de data van de buitensensoren naar de scherm module worden gestuurd.
Deze zending kan onderschept worden en zo kan de data naar de backend gestuurd worden waar de data wordt bijgehouden in een database.

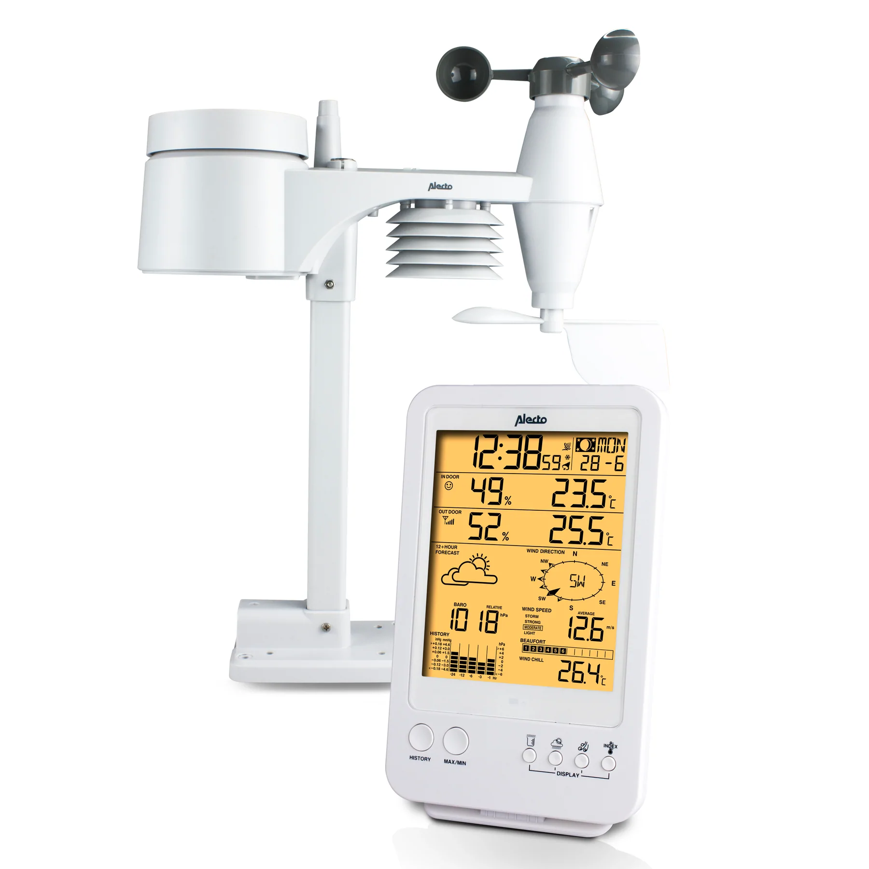
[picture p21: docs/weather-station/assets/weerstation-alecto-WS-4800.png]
Weerstation Alecto WS-4800 :size=300
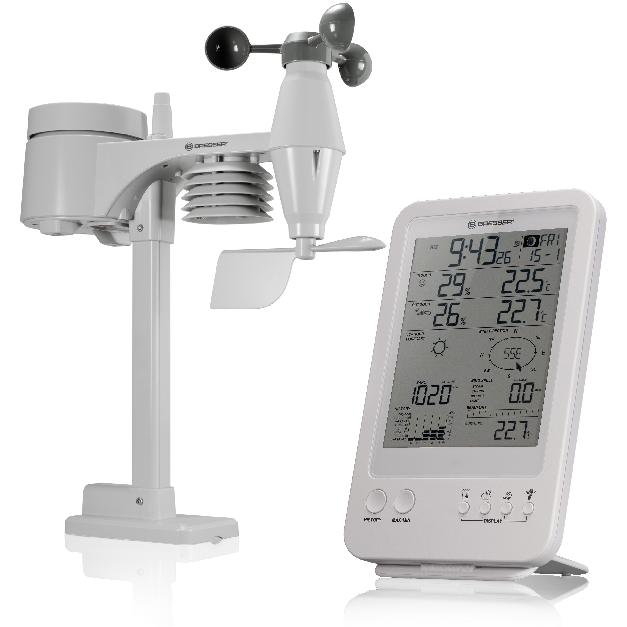
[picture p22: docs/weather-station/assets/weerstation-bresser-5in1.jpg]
Weerstation Bresser 5-in-1 :size=300
 

*fig. 1, Alecto WS-4800 weerstation*; *fig. 2, Bresser 5-in-1 (New) weerstation*

### Op voorhand:

- In het hoofdstuk Data Formatting onder [Data Overzicht](./data-formatting/data-overzicht.md) staat er in detail beschreven welke data er wordt verzameld door het weerstation.

- Er is een [bestaand project](https://www.skyon.be/maak-je-weerstation-geconnecteerd-en-slim/) met hetzelfde weerstation. Dit wordt gebruikt als referentie.

### Hands on:

#### Weerstation opbouwen en uittesten

We krijgen data binnen van het weerstation op de GUI dat meekwam met het weerstation.

#### [Dit project](https://www.skyon.be/maak-je-weerstation-geconnecteerd-en-slim/) volgen stap voor stap

We hebben het commando hieronder uitgevoerd. We hebben de parameters ingevuld met onze eigen mqtt server.

```
/usr/local/bin/rtl_433 -R 119 -f 868M -s 1024k -F mqtt://<mqtt_server_ip> 1883 retain 0 devices rtl_433[/id]
```

rtl_433 is een open-source project op GitHub dat het demoduleren en decoderen van radiosignalen van een groot bereik van weerstations mogelijk maakt. Toen wij het commando hierboven uitvoerde was er geen zichtbare data binnen gekomen op onze MQTT server. Wij hebben ook een aantal varianten geprobeerd.

1. Misschien werkt MQTT niet
   
   We hebben MQTT getest door testdata door te sturen, dit werkt. We hebben ook het commando uitgevoerd met de terminal als output in plaats van MQTT. **Nog steeds geen data**.

2. Misschien is de sample rate verkeerd
   
   We hebben het commando uitgevoerd met verschillende sample rates. **Nog steeds geen data**.

3. Misschien is de frequentie verkeerd
   
   We hebben het commando uitgevoerd met verschillende frequenties rond 868MHz. **Nog steeds geen data**.

4. Mischien gebruiken we een verkeerd algoritme
   
   We hebben naar de lijst van algoritmes gekeken op de GitHub van rtl_433. Met CTRL+F hebben we gezocht naar "Bresser"
   
   1. [52]  Bresser Thermo-/Hygro-Sensor 3CH
   
   2. [119]  Bresser Weather Center 5-in-1
   
   3. [172]  Bresser Weather Center 6-in-1, [...]
   
   4. [173]  Bresser Weather Center 7-in-1

Zoals eerder besproken is onze weerstation een variant op de Bresser Weather Center 5-in-1. Tussen de lijst van algoritmes staat er maar 1 die overeenkomt met de 5-in-1. Het algoritme dat we gebruiken in het commando hierboven klopt dus. **Nog steeds geen data**.

Later zullen we nog ontdekken waarom dat we geen data ontvangen.

#### Met een HackRF proberen onderscheppen

Met behulpt van GQRX is ontdekt dat het weerstation werkt op 868.3MHz met FM modulatie. Dit is te zien aan de twee pieken in *fig 3*. Dit is niet onlogisch. 863MHz tot 870MHz is binnen Europa vrij te gebruiken, daarom dat veel consumer technology gebruik maakt van deze frequenties. 

Eens er geweten is wat de centerfrequentie is kan het signaal vervolgens gedemoduleerd worden. Om het signaal succesvol te demoduleren is er eerst gekeken naar bestaande projecten. [Dit](https://github.com/andreafabrizi/BresserWeatherCenter) project van andreafabrizi is daar een voorbeeld van. 

Tijdens het volgen van dat project werden er een aantal opmerkelijkheden ontdekt:

1. In dat project staat dat er AM modulatie gebruikt wordt.

2. Wij hebben geobserveerd dat er FM modulatie aanwezig is.

3. In een [tweede project](https://github.com/merbanan/rtl_433/blob/master/src/devices/bresser_5in1.c) dat gebruik maakt van andreafabrizi's project wordt vermeld dat het weerstation gebuik maakt van "FSK-PCM" modulatie.

Wij hebben dus nu twee bronnen die iets compleet verschillend zeggen plus onze eigen observatie van FM modulatie op het signaal. Opmerkelijk.

Voor de volgende stap is er besloten om dit FM signaal te proberen demoduleren. Aangezien we een FM signaal observeren zullen we deze ook demoduleren als FM signaal. De projecten die eerder vermeld werden zullen wij gebruiken tijdens het decoderen van het signaal, aangezien dat dit is waar de focus op ligt bij die projecten.

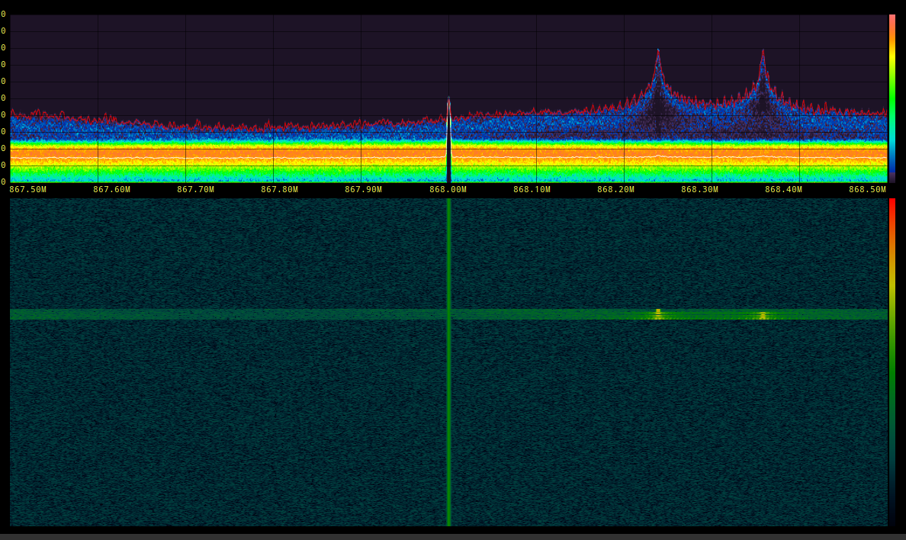
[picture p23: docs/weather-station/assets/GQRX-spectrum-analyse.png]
GQRX spectrum analyse


*fig. 3, GQRX spectrum analyse*

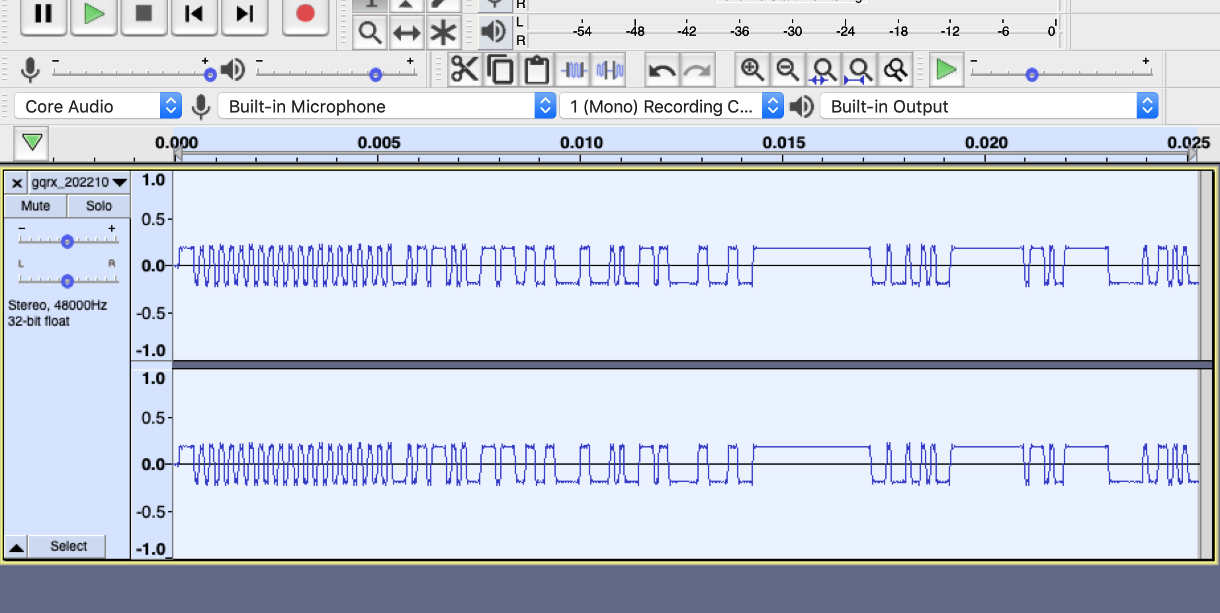
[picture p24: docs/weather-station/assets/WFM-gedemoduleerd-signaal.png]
WFM gedemoduleerd signaal


*fig 4, WFM gedemoduleerd signaal*

In *fig 3* is te zien hoe dat een spectrum analyse eruit ziet. Het is heel duidelijk dat er twee pieken zijn rond de centerfrequentie (868.3MHz). Binnen GQRX is een functie om een FM signaal te demoduleren. Door dit toe te passen hebben wij ontdekt dat het geen FM signaal is maar een WFM signaal. Na de demodulatie door gebruik te maken van GQRX is het signaal zichtbaar op *fig 4*.

Merk op: in het project van andreafabrizi staat een heel gelijkaardige foto. Het signaal dat daar gedemoduleerd is ziet er heel gelijkaardig uit. Een preamble met dan de data die erna komt. Dit is goed nieuws en betekent dat we mogelijks toch gebruik kunnen maken van de twee projecten op GitHub.

Voor dat we dit signaal kunnen decoderen moeten we het wel kunnen demoduleren met GNURadio  Companion. De reden hiervoor is dat GRC een python file genereerd dat op eender welk systeem uitgevoerd kan worden. Dit is natuurlijk handiger om op te schalen dan een grafisch programma.

Dit bleek veel moeilijker dan verwacht. We hebben besloten om eens te kijken wat er binnenin het weerstation gebeurt om ook een  plan B te onderzoeken.

#### Weerstation open maken

We hebben het weerstation open gemaakt om zo toch al een alternatief te onderzoeken voor als de data niet makkelijk onderschept kan worden met een SDR.

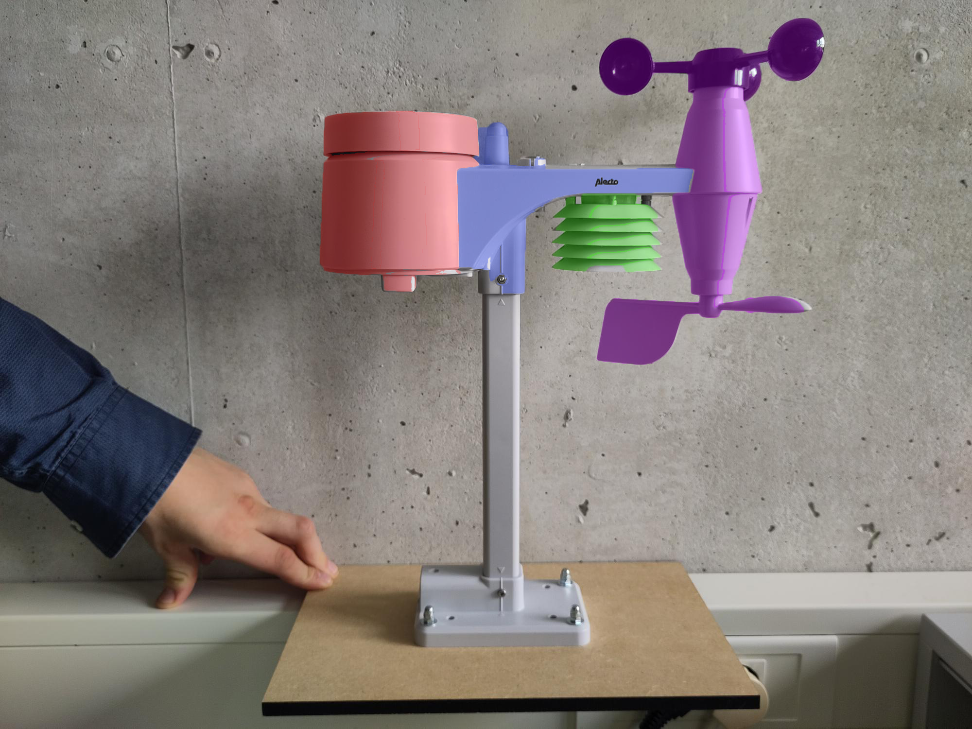
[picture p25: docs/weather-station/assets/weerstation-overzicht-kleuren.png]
Overzicht weerstation onderdelen


*fig 5, Overzicht weerstation onderdelen*

Op de bovenstaande foto heb ik een aantal onderdelen een kleur gegeven.

- **Rood**: Dit onderdeeel meet de hoeveelheid regen dat gevallen is

- **Blauw**: In dit onderdeel zitten de PCB's die verantwoordelijk zijn voor het bewerken en versturen van de data vanuit de sensoren

- **Groen**: Dit onderdeel is verantwoordelijk voor de metingen rond vochtigheid en temperatuur

- **Paars**: Dit is een anemometer. Hier wordt de windsnelheid en richting gemeten.

Weerstation binnenkant

*fig 6, Weerstation binnenkant*

Regenmeter foto 1

*fig 7, Regenmeter binnenkant foto 1*

Regenmeter foto 2

*fig 8, Regenmeter binnenkant foto 2*

##### Regenmeter

De regenmeter werkt met een simpel principe. Als het lepeltje opgevuld is dan kantelt het en valt al het water eruit. Door deze kantelbeweging kan een magnetische sensor een magneet detecteren en dus detecteren dat er een bepaalde hoeveelheid regen gevallen is (deze hoeveelheid is de inhoud van het lepeltje)

##### PCB

PCB van weerstation

*fig 9, PCB van weerstation*

Op de PCB van het weerstation is niet veel te zien. Het is duidelijk waar de antenne is en waar de data van de sensoren binnekomt. Het is niet duidelijk welke microcontroller er gebruikt wordt omdat deze gecoat zijn met een zwarte beschermende laag.

##### Anemometer

Windrichting binnenkant foto 1

*fig 10, Windrichting binnenkant foto 1*

Windrichting binnenkant foto 2

*fig 11, Windrichting binnenkant foto 2*

De windrichting wordt op een interessante manier gelezen. Er is een cirkelvormige array van IR receivers. Deze passen in een vorm waar een gat in zit. Afhankelijk van de positie van deze vorm zullen er enkel 1 of 2 IR receivers tegelijk werken. Daaruit kan je afleiden in welke orientatie dat de wind zit.

Anemometer

*fig 12, Anemometer*

Dit is een soort van magnetische sensor dat gebruikt wordt om de de windsnelheid te meten. Het werkt gelijkaardig aan de werking van een speedometer op een fiets.

@reboot rtl_433 -f 868.3MHz -R 172 -F "mqtt://167.71.75.179:1883, user=bavo, pass=s120267, retain=0,events=weatherStation" -M time:unix:utc:tz:iso:usec -F kv

#### RTL_433

Om te onderzoeken hoe dat de gedemoduleerde data gedecodeert kon worden werden de C-files op de GitHub van RTL_433 geraadpleegd. RTL_433 is zoals eerder vermeld een open-source project op GitHub dat zich bezig houdt met het demoduleren en decoderen van radiosignalen op de ISM band. Onder andere ook weerstations zoals die van ons.

Er werd gebruik gemaakt van de zoekfunctie op GitHub om alle files te doorzoeken naar zoektermen. Zo werd er gezocht op "5-in-1" om alle files te vinden die zich bezig houden met het decoderen, demoduleren, en documenteren van de Bresser 5-in-1.

Toen werd er ontdekt dat in de C-file die zich bezig houdt met de Bresser 6-in-1 het volgende staat:

```md
Decoder for Bresser Weather Center 6-in-1.
- also Bresser Weather Center 7-in-1 indoor sensor.
- also Bresser new 5-in-1 sensors.
- also Froggit WH6000 sensors.
- also rebranded as Ventus C8488A (W835)
- also Bresser 3-in-1 Professional Wind Gauge / Anemometer, PN 7002531
- also Bresser soil temperature and moisture meter, PN 7009972
- also Bresser Thermo-/Hygro-Sensor 7 Channel 868 MHz, PN 7009999

```

Het algoritme voor de Bresser 6-in-1 werkt ook met de nieuwe Bresser 5-in-1. Opmerkelijk.

Dit werd uiteraard meteen getest. **Nu ontvangen we data van het weerstation**. De volgende stap is om deze data ook inneens binnen te halen op de backend via MQTT. Daarvoor moet wel de data een timestamp krijgen om te werken met influxDB. Dan moet er nog voor gezorgd worden dat dit commando altijd runt, ook bij startup van de raspberry pi. Met deze aanpassing ziet het commando er alst volgt uit.

`rtl_433 -f 868.3MHz -R 172 -F "mqtt://167.71.75.179:1883, user=bavo, pass=s120267, retain=0,events=weatherStation" -M time:unix:utc:tz:iso:usec -F kv`

Dit commando wordt dan in een crontab gezet met de `@reboot` functie zodat deze opstart samen met de raspberry pi.

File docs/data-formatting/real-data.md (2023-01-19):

# Data Formatting

## Effectieve Data

In het onderdeel [Data Structuur](./data-formatting/data-structure.md) is uiteengezet hoe de data er kan uitzien enkele stappen in de datastroom. Er wordt ook toegelicht hoe deze verwerkt kan worden.

In dit onderdeel worden de datastromen van effectieve (real) data bekeken.

1. Sensor data SAMDaaNo21 over LoRaWAN
2. Weather Station data over MQTT

FLWSB Project overzichtsdiagram. Figuur 1: FLWSB Project overzichtsdiagram.

---

### Sensor data SAMDaaNo21 over LoRaWAN

Een illustratie van hoe de data van een meting van de BME280, die temperatuur, luchtdruk en luchtvochtigheid bevat, wordt verzonden en verwerkt wordt in de backend.

#### SIS Web Formulieren

Voor er data wordt verzonden moeten zowel het board als de hierop eengesloten sensoren worden geregistreerd in het SIS, of Sensor Identification System, via een web formulier.

SIS web forms voorbeeld. Figuur 2: SIS web forms voorbeeld.

Dit werkt met volgende Node-RED flow:

SIS web forms Node-RED flow. Figuur 3: SIS web forms Node-RED flow.

Dit brengt volgende msg's in Node-RED binnen:

```javascript
{
  "payload":
  {
    "board_id":"eui-0004a30b0020da72",
    "sensor_id":8,
    "sensor_name":"BME280",
    "nr_of_measurements":3,
    "quantity":"temp, pressure, humidity",
    "unit":"°C, hPa, %",
    "range":"-40.00 85.00, 300 1100, 0 100",
    "conversion":"/100 -40, 1, 1",
    "datatype":"float, uint16_t, byte"
  },
  "socketid":"ScYUaiaHGHdfmQYWAAAT",
  "_msgid":"804621b4d4723594"
}
```

```javascript
{
  "payload":
  {
    "board_id":"eui-0004a30b0020da72",
    "board_name":"samdaano21-poc",
    "latitude":51.22999030805754,
    "longitude":4.416285765591264
  },
  "socketid":"ScYUaiaHGHdfmQYWAAAT",
  "_msgid":"a973b9015232c834"
}
```

Met resulterende push naar de InfluxDb database:

```javascript
[
  {
    "sensor_name":"BME280",
    "nr_of_measurements":3,
    "quantity":"temp, pressure, humidity",
    "unit":"°C, hPa, %",
    "range":"-40.00 85.00, 300 1100, 0 100",
    "conversion":"/100 -40, 1, 1",
    "datatype":"float, uint16_t, byte",
    "time":"2023-01-17T21:50:37.960Z"
  },
  {
    "board_id":"eui-0004a30b0020da72",
    "sensor_id":8
  }
]
```

```javascript
[
  {
    "board_name":"samdaano21-poc",
    "latitude":51.22999030805754,
    "longitude":4.416285765591264,
    "time":"2023-01-17T21:50:42.690Z"
  },
  {
    "board_id":"eui-0004a30b0020da72"
  }
]
```

Het resultaat in de InfluxDb database Data Explorer web interface.

SIS data in InfluxDb Data Explorer web interface. Figuur 4: SIS data in InfluxDb Data Explorer web interface.

#### Bitstream

De meting wordt opgevraagd en omgezet van een byte array naar een bitstream.
Dit is vrij uitgebreide en complexe code terug te vinden in het onderdeel [PoC Code (example sketches)](embedded-programming/poc-code.md).

De verzonden bitstream, of toch enkel de data zelf, ziet er als volgt uit:

```c
00001000
00010111
11010100
00000011
11101001
00110000
```

Dit representeerd volgende bytes array: `[8,23,212,3,233,48]`.

#### TTN Uplink message

Eens ontvangen door The Things Network wordt de bitstream omgezet in een Uplink message om te verzenden over MQTT en wordt vervolgens ontvangen in Node-RED.

De bitstream wordt omgezet naar `CBfUA+kw` in [Base64 (RFC 3548, RFC 4648)](https://cryptii.com/pipes/base64-to-binary) codering. Deze komt terecht in `msg.payload.uplink_message.frm_payload`.

Er is verder een hele hoop extra data aan toegevoegd.
Onderstaande code is het volledige msg object. Hierbij representeerd `data` de `msg.payload`.

```javascript
{
  "name": "as.up.data.forward",
  "time": "2022-12-23T16:58:11.318059995Z",
  "identifiers": [
    {
      "device_ids": {
        "device_id": "eui-0004a30b0020da72",
        "application_ids": {
          "application_id": "flwsb"
        },
        "dev_eui": "0004A30B0020DA72",
        "join_eui": "0004A30B0020DA72",
        "dev_addr": "260B386C"
      }
    }
  ],
  "data": {
    "@type": "type.googleapis.com/ttn.lorawan.v3.ApplicationUp",
    "end_device_ids": {
      "device_id": "eui-0004a30b0020da72",
      "application_ids": {
        "application_id": "flwsb"
      },
      "dev_eui": "0004A30B0020DA72",
      "join_eui": "0004A30B0020DA72",
      "dev_addr": "260B386C"
    },
    "correlation_ids": [
      "as:up:01GMZYQEFJ9WFPS1RANANBJK6A",
      "ns:uplink:01GMZYQE8VDPC2WR4K8R9C359Q",
      "pba:conn:up:01GM367NPGXHWVSHN6JFKFKPVR",
      "pba:uplink:01GMZYQE8RVEDGBZC7S9ZJ7RJZ",
      "rpc:/ttn.lorawan.v3.GsNs/HandleUplink:01GMZYQE8VN437T3PHHFFF16ZN",
      "rpc:/ttn.lorawan.v3.NsAs/HandleUplink:01GMZYQEFH6D3MQKT445TBD0ET"
    ],
    "received_at": "2022-12-23T16:58:11.314080290Z",
    "uplink_message": {
      "session_key_id": "AYU/6AGa+vh+WfbYP5XQGA==",
      "f_port": 1,
      "f_cnt": 33,
      "frm_payload": "CBfUA+kw",
      "decoded_payload": {
        "bytes": [
          8,
          23,
          212,
          3,
          233,
          48
        ]
      },
      "rx_metadata": [
        {
          "gateway_ids": {
            "gateway_id": "packetbroker"
          },
          "packet_broker": {
            "message_id": "01GMZYQE8RVEDGBZC7S9ZJ7RJZ",
            "forwarder_net_id": "000013",
            "forwarder_tenant_id": "ttnv2",
            "forwarder_cluster_id": "ttn-v2-legacy-eu",
            "forwarder_gateway_eui": "7276FF0000062E94",
            "forwarder_gateway_id": "eui-7276ff0000062e94",
            "home_network_net_id": "000013",
            "home_network_tenant_id": "ttn",
            "home_network_cluster_id": "eu1.cloud.thethings.network"
          },
          "time": "2022-12-23T16:58:09.998443Z",
          "fine_timestamp": "955291031",
          "rssi": -111,
          "signal_rssi": -113,
          "channel_rssi": -111,
          "snr": 1,
          "frequency_offset": "4464",
          "location": {
            "latitude": 51.22994085,
            "longitude": 4.41383496,
            "altitude": 30
          },
          "uplink_token": "eyJnIjoiWlhsS2FHSkhZMmxQYVVwQ1RWUkpORkl3VGs1VE1XTnBURU5LYkdKdFRXbFBhVXBDVFZSSk5GSXdUazVKYVhkcFlWaFphVTlwU25Oa2F6RkRWakJzYWxJelNtOVBWVnBMVFRJMWRFbHBkMmxrUjBadVNXcHZhVmRYZUZkV1ZGRXlVWHBWTVZKck1IUlZVekV3WWxjMVdFMVhiRmxSVTBvNUxqUlRUMWg1YkU1R01HZG5Ra1EwVnpsTmF6WnJUMEV1TVdnMU9IaGtjMWRNVjFNNU5FSmhTQzVVTW5ONFIxSllWMmxwWlV4NVZYaGpaMGs0UVZSaU9HbFZORGhaZWt4UGNWbEVaRlY2Tlc5SGVrSnBMVU5rYXpJMGRGQkxaVVpMYWpVMWRXNU5Tbk14UTBOd2NpMVRkbTFoT0Y5SGRFTmxTVXRIUzBWNFR6Rm9jMlExVTBoT05HTm1UV3BOV2xFNE5tZGlWRE4zUkZWSWFWTndlazQyYlZkclgyZzFaak5ZUkVablQzVXpUWFZaYlRKMlVqWTNkSEV0UXpBMFNVUnplVFZ5VkVrd1NtdGlWM0JxVkd4RFIwZE1iRnBZZW1OVkxrTklhMVk0V0hCbGRHcEJTa1JpVFRGaVJsaFpSbEU9IiwiYSI6eyJmbmlkIjoiMDAwMDEzIiwiZnRpZCI6InR0bnYyIiwiZmNpZCI6InR0bi12Mi1sZWdhY3ktZXUifX0=",
          "received_at": "2022-12-23T16:58:11.093770044Z"
        },
        {
          "gateway_ids": {
            "gateway_id": "packetbroker"
          },
          "packet_broker": {
            "message_id": "01GMZYQE8RVEDGBZC7S9ZJ7RJZ",
            "forwarder_net_id": "000013",
            "forwarder_tenant_id": "ttnv2",
            "forwarder_cluster_id": "ttn-v2-legacy-eu",
            "forwarder_gateway_eui": "7276FF0000062E94",
            "forwarder_gateway_id": "eui-7276ff0000062e94",
            "home_network_net_id": "000013",
            "home_network_tenant_id": "ttn",
            "home_network_cluster_id": "eu1.cloud.thethings.network"
          },
          "antenna_index": 1,
          "time": "2022-12-23T16:58:09.998443Z",
          "rssi": -112,
          "signal_rssi": -117,
          "channel_rssi": -112,
          "rssi_standard_deviation": 1,
          "snr": -4,
          "frequency_offset": "4457",
          "uplink_token": "eyJnIjoiWlhsS2FHSkhZMmxQYVVwQ1RWUkpORkl3VGs1VE1XTnBURU5LYkdKdFRXbFBhVXBDVFZSSk5GSXdUazVKYVhkcFlWaFphVTlwU25Oa2F6RkRWakJzYWxJelNtOVBWVnBMVFRJMWRFbHBkMmxrUjBadVNXcHZhVmRYZUZkV1ZGRXlVWHBWTVZKck1IUlZVekV3WWxjMVdFMVhiRmxSVTBvNUxqUlRUMWg1YkU1R01HZG5Ra1EwVnpsTmF6WnJUMEV1TVdnMU9IaGtjMWRNVjFNNU5FSmhTQzVVTW5ONFIxSllWMmxwWlV4NVZYaGpaMGs0UVZSaU9HbFZORGhaZWt4UGNWbEVaRlY2Tlc5SGVrSnBMVU5rYXpJMGRGQkxaVVpMYWpVMWRXNU5Tbk14UTBOd2NpMVRkbTFoT0Y5SGRFTmxTVXRIUzBWNFR6Rm9jMlExVTBoT05HTm1UV3BOV2xFNE5tZGlWRE4zUkZWSWFWTndlazQyYlZkclgyZzFaak5ZUkVablQzVXpUWFZaYlRKMlVqWTNkSEV0UXpBMFNVUnplVFZ5VkVrd1NtdGlWM0JxVkd4RFIwZE1iRnBZZW1OVkxrTklhMVk0V0hCbGRHcEJTa1JpVFRGaVJsaFpSbEU9IiwiYSI6eyJmbmlkIjoiMDAwMDEzIiwiZnRpZCI6InR0bnYyIiwiZmNpZCI6InR0bi12Mi1sZWdhY3ktZXUifX0=",
          "received_at": "2022-12-23T16:58:11.093770044Z"
        }
      ],
      "settings": {
        "data_rate": {
          "lora": {
            "bandwidth": 125000,
            "spreading_factor": 7,
            "coding_rate": "4/5"
          }
        },
        "frequency": "867100000"
      },
      "received_at": "2022-12-23T16:58:11.099382830Z",
      "consumed_airtime": "0.051456s",
      "network_ids": {
        "net_id": "000013",
        "tenant_id": "ttn",
        "cluster_id": "eu1",
        "cluster_address": "eu1.cloud.thethings.network"
      }
    }
  },
  "correlation_ids": [
    "as:up:01GMZYQEFJ9WFPS1RANANBJK6A",
    "ns:uplink:01GMZYQE8VDPC2WR4K8R9C359Q",
    "pba:conn:up:01GM367NPGXHWVSHN6JFKFKPVR",
    "pba:uplink:01GMZYQE8RVEDGBZC7S9ZJ7RJZ",
    "rpc:/ttn.lorawan.v3.GsNs/HandleUplink:01GMZYQE8VN437T3PHHFFF16ZN",
    "rpc:/ttn.lorawan.v3.NsAs/HandleUplink:01GMZYQEFH6D3MQKT445TBD0ET"
  ],
  "origin": "ip-10-100-4-181.eu-west-1.compute.internal",
  "context": {
    "tenant-id": "CgN0dG4="
  },
  "visibility": {
    "rights": [
      "RIGHT_APPLICATION_TRAFFIC_READ"
    ]
  },
  "unique_id": "01GMZYQEFP4GQ5WK1EW6PWYFV2"
}
```

##### Payload formatter

De `decoded_payload` wordt toegevoegd als er een Payload formatter voorzien wordt in de TTN applicatie. Hier is de standaard formatter gebruikt als debugging methode. Zo kan de base64 string die in `frm_payload` zit, de verzonden bitstream, al worden gelezen als afzonderlijke bytes.

Deze Payload formatter is, net zoals de code in Node-RED, JavaScript.
De volgende code, de standaard code die gegeven wordt door TTN onder *Custom Javascript formatter* is gebruikt.

```JavaScript
function decodeUplink(input) {
  return {
    data: {
      bytes: input.bytes
    },
    warnings: [],
    errors: []
  };
}
```

TTN FLWSB applicatie default payload formatter. Figuur 5: TTN FLWSB applicatie default payload formatter.

Er wordt in dit project verder gekozen om geen gebruik te maken van de Payload formatter in de TTN applicatie om de controle over het formatteren in de eigen backend in Node-Red te houden. Dit geeft bnetere flexibiliteit.

#### Base64

De `frm_payload` bevat de bitstream die door TTN ontvangen is. Deze is echter gecodeerd als een base64 string. Om de data te kunnen formatteren moet deze eerst worden omgezet in een byte array.

Omzetting functie van base64 naar bytes array, of Buffer:

```javascript
function base64ToArrayBuffer(value) {
	var load = value.replace(/\s+/g, '');  // remove any whitespace
	value = Buffer.from(load, 'base64');
	return value;
}
```

Links:
- [Node-RED javascript code om base64 om te zetten in een bytes Buffer](https://github.com/node-red/node-red-nodes/blob/master/parsers/base64/70-base64.js)
- [Base64 data omzetter](https://cryptii.com/pipes/base64-to-binary)

#### Formateren in Node-RED JavaScript

Om de data nu te gaan schrijven naar de InfluxDb database moet deze gestructureerd worden om aan het bepaalde model te voldoen.

Node-RED ttn-sis-flwsb flow. Figuur 6: Node-RED ttn-sis-flwsb flow.

Eerst gebeurt er een query naar de `sis` bucket inde InfluxDb database voor de nodige informatie.

```javascript
const board_id = msg.payload.end_device_ids.device_id;

// Flux query
msg.query = `from(bucket: "sis")
  |> range(start: -100y, stop: now())
  |> filter(fn: (r) => r["_measurement"] == "sensor" or r["_measurement"] == "board")
  |> filter(fn: (r) => r["board_id"] == "${board_id}")
  |> filter(fn: (r) => r["_field"] == "board_name" or r["_field"] == "latitude" or r["_field"] == "longitude" or r["_field"] == "conversion" or r["_field"] == "nr_of_measurements" or r["_field"] == "quantity" or r["_field"] == "sensor_name" or r["_field"] == "datatype")
  |> aggregateWindow(every: 1y, fn: last, createEmpty: false)
  |> yield(name: "last")`

return msg;
```

Vervolgens wordt de `ttn` data geformatteerd aan de hand van deze `sis` query.

```javascript
const ttn = msg.payload[0]; // TTN MQTT msg
const sis = msg.payload[1]; // SIS query result msg

// ID & Timestamp from TTN msg
const id = ttn.end_device_ids.device_id;
const timestamp = new Date(ttn.received_at);  // timestamp TTN

// Board info from SIS query
const board_name = (sis.find(obj => obj._field == "board_name"))["_value"];
const latitude = (sis.find(obj => obj._field == "latitude"))["_value"];
const longitude = (sis.find(obj => obj._field == "longitude"))["_value"];
// node.warn(`location: ${latitude}, ${longitude}`);  // Debug info

// Bitstream
function base64ToArrayBuffer(value) {
	var load = value.replace(/\s+/g, '');  // remove any whitespace
	value = Buffer.from(load, 'base64');
	return value;
}

const bitstream = base64ToArrayBuffer(ttn.uplink_message.frm_payload);
node.warn(bitstream); // Debug info

// Sensor ID
const sensor_id = bitstream[0]; // Only for signle byte ID's
node.warn(`sensor_id: ${sensor_id}`); // Debug info

// Sensor info from SIS query by Sensor ID
const sensor_name = (sis.find(obj => obj._field == "sensor_name" && obj.sensor_id == sensor_id))["_value"];
const nr_of_measurements = (sis.find(obj => obj._field == "nr_of_measurements" && obj.sensor_id == sensor_id))["_value"];
const datatype = (sis.find(obj => obj._field == "datatype" && obj.sensor_id == sensor_id))["_value"];
const quantity = (sis.find(obj => obj._field == "quantity" && obj.sensor_id == sensor_id))["_value"];
const conversion = (sis.find(obj => obj._field == "conversion" && obj.sensor_id == sensor_id))["_value"];

// Formatting the payload for InfluxDb push
msg.payload = [
	[{
		latitude: latitude,
		longitude: longitude,
		consumed_airtime: +(ttn.uplink_message.consumed_airtime.slice(0, -1)), // remove "s" and convert to number
		time: timestamp
	},
	{
		board_id: id,  // device-id TTN en SIS
		board_name: board_name,
	}]
];

let sensor_data = [
	{
		// temp: ((((bitstream[1] << 8) + bitstream[2]) / 100) - 40),
		// pressure: ((bitstream[3] << 8) + bitstream[4]),
		// humidity: bitstream[5],
		time: timestamp
	},
	{
		board_id: id,  // device-id TTN en SIS
		sensor_id: sensor_id,
		sensor_name: sensor_name,
	}
];

if (nr_of_measurements > 1) {
	// Sensor info for multiple measurements to Arrays
	const quantities = quantity.split(", ");
	node.warn(`quantities: ${quantities}`); // Debug info
	const conversions = conversion.split(", ");
	node.warn(`conversions: ${conversions}`); // Debug info
	const datatypes = datatype.split(", ");
	node.warn(`datatypes: ${datatypes}`); // Debug info

	// Define iteration length
	let length = nr_of_measurements;
	for (let i = 1; i < length; i++) { // Skip the first byte(s) of the bitstream, the sensor_id.
		node.warn(datatypes[i]);
		if (!(datatypes[i] == "byte")) {
			length++;
		}
	}
	node.warn(`length: ${length}`); // Debug info

	// Values array
	let values = [];
	for (let i = 1; i < length; i++) { // Skip the first byte(s) of the bitstream, the sensor_id.
		node.warn(datatypes[i]);
		if (datatypes[i] == "byte") {
			values[i] = bitstream[i];
		}
		else {
			values.push((bitstream[i] << 8) + bitstream[i + 1]);
			i++;
		}
	}

	// Quantities and Measurement data to key value pairs
	for (let i = 0; i < nr_of_measurements; i++) {
		sensor_data[0][`${quantities[i]}`] = values[i];
	}
}
else {
	if (datatype == "byte") {
		sensor_data[0][`${quantity}`] = bitstream[1];
	}
	else {
		sensor_data[0][`${quantity}`] = (bitstream[1] << 8) + bitstream[2];
	}
}

node.warn(sensor_data[0]); // Debug info
msg.payload.push(sensor_data);

return msg;
```

*Conversions, of omzettingen, zijn nog niet geïmplementeerd in deze code.*

#### InfluxDb query voor visualisatie in Grafana

Een query in Flux, de gespesialiseerde query taal van InfluxDb, om de data op te vragen voor visualisatie.
De time range wordt in het dashboard van Grafana ingesteld.

```flux
from(bucket: "flwsb")
  |> range(start: v.timeRangeStart, stop: v.timeRangeStop)
  |> filter(fn: (r) => r["_measurement"] == "climate_data")
  |> filter(fn: (r) => r["_field"] == "temp, pressure, humidity")
  |> filter(fn: (r) => r["board_id"] == "eui-0004a30b0020da72")
  |> aggregateWindow(every: v.windowPeriod, fn: mean, createEmpty: false)
  |> yield(name: "mean")
```

Het resultaat in Grafana Dashboard:

Query resultaat visualisatie in Grafana dashboard van climate_data van de SAMDaaNo21, meer precies temperatuur, luchtdruk en luchtvochtigheid. Figuur 7: Query resultaat visualisatie in Grafana dashboard van climate_data van de SAMDaaNo21, meer precies temperatuur, luchtdruk en luchtvochtigheid.

---

### Weather Station data over MQTT

#### Weerstation

Het weerstation zelf is een blackbox. Hoe de data hier juist verwerkt wordt is onbekend.

#### Raspberry Pi met RTL-SDR

De verwerking hier gebeurd geautomatiseerd door de gebruikte applicatie.
Er zijn beperkte opties voor het formateren van deze data beschikbaar.
Het betreft een open-source applicatie met repository op GitHub, maar hoe deze applicatie juist werkt is niet noodzakelijk te weten voor deze toepassing.
Voor meer info zie [ Weather STation: Reading/Sending Data](./weather-station/data.md).

#### Mosquitto MQTT Broker
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

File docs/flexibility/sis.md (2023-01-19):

# Flexibiliteit

## Sensor Identification System (SIS)

### Principe

Om een modulair systeem te behouden en tegelijkertijd de hoeveelheid data die verzonden moet worden te beperken wordt er gewerkt met het Sensor Identification System (SIS). Dit koppelt een uniek sensor-id aan elke sensor die aangeeft over wat voor data het gaat en welke grote deze heeft. Zo hoeft het FLWSB-board enkel de data door te sturen waarover het daadwerkelijk beschikt. De backend weet vervolgens ook over wat voor data het gaat en kan deze correct verwerken en opslagen.

### Sensor-id

De sensor-id kan één of twee bytes zijn. Is de eerste bit een "1" dan bestaat het uit twee bytes. Is de eerste bit een "0" dan is er maar één byte gebruikt voor het sensor-id. Zo kan er eerst gewerkt worden met maar één byte, maar kan er ook voldoende uitgebreid worden indien nodig.
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

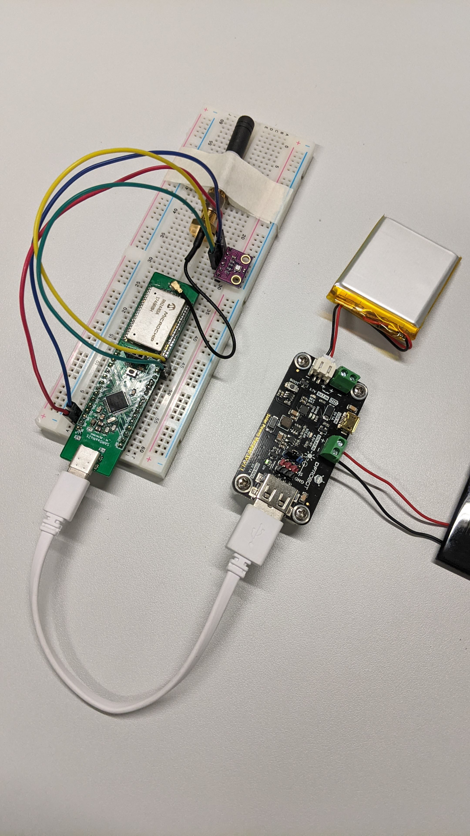
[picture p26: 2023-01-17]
docs/demo/assets/flwsb-demo-overview-woSolar-angle.jpg

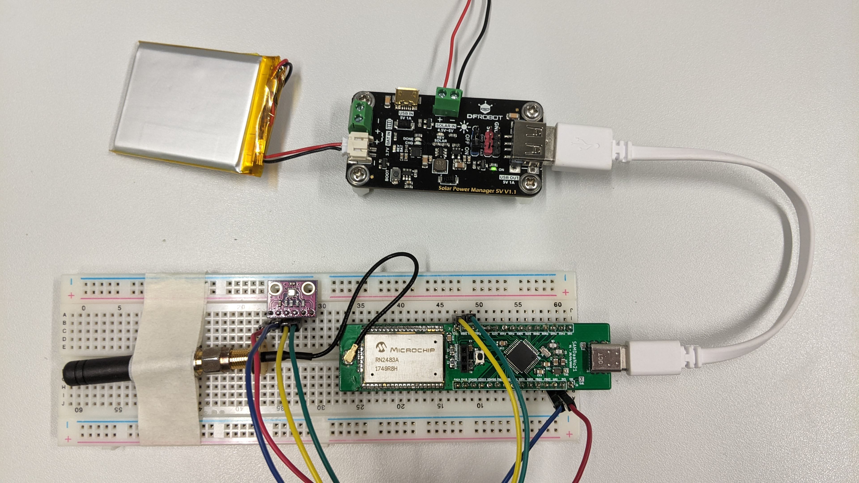
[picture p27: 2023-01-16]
docs/demo/assets/flwsb-demo-overview-woSolar-top.jpg

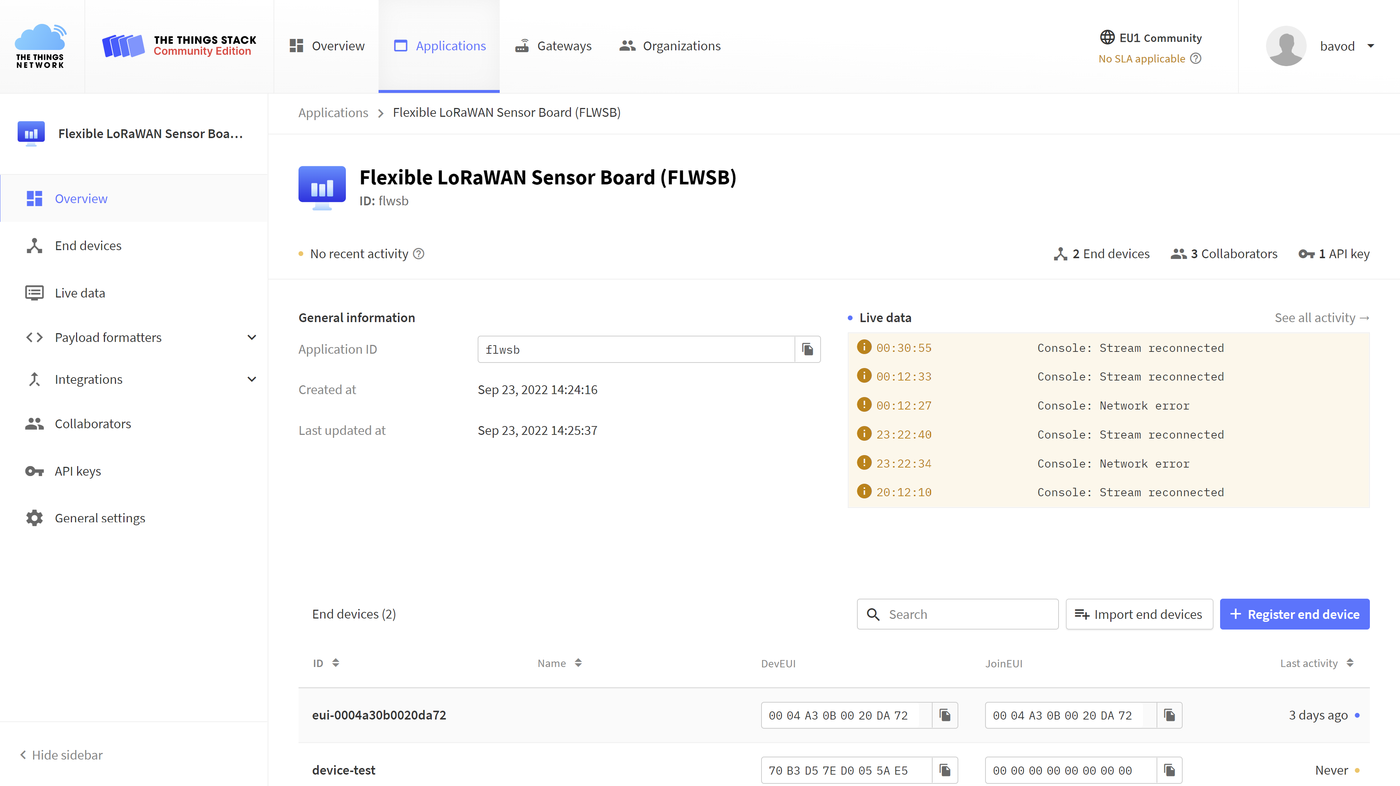
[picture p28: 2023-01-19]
docs/data-formatting/assets/ttn-flwsb-app-overview.png

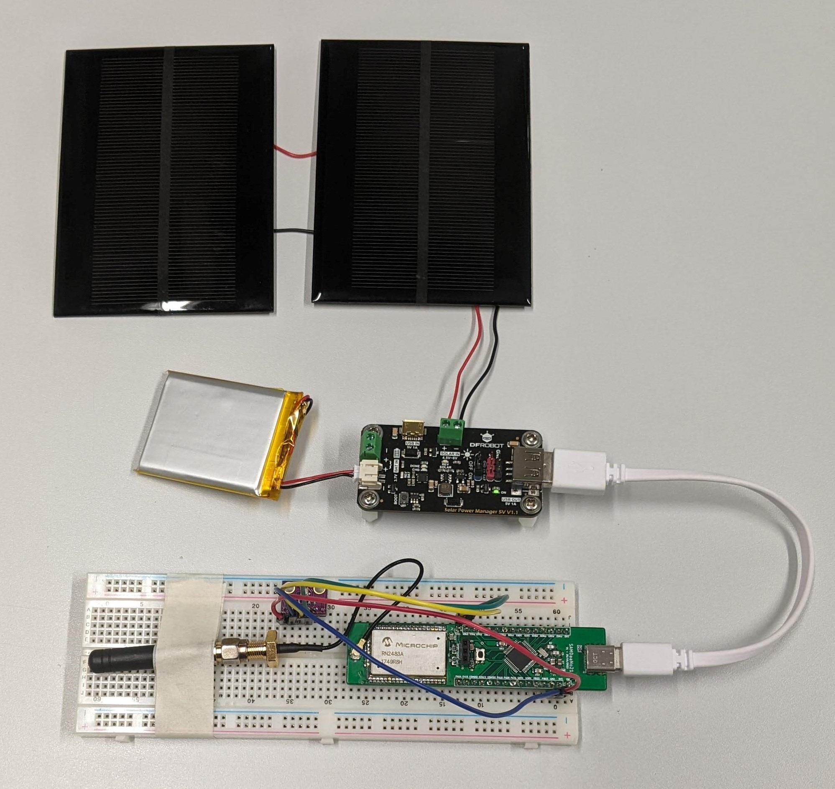
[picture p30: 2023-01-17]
docs/demo/assets/flwsb-demo-overview-top.jpg

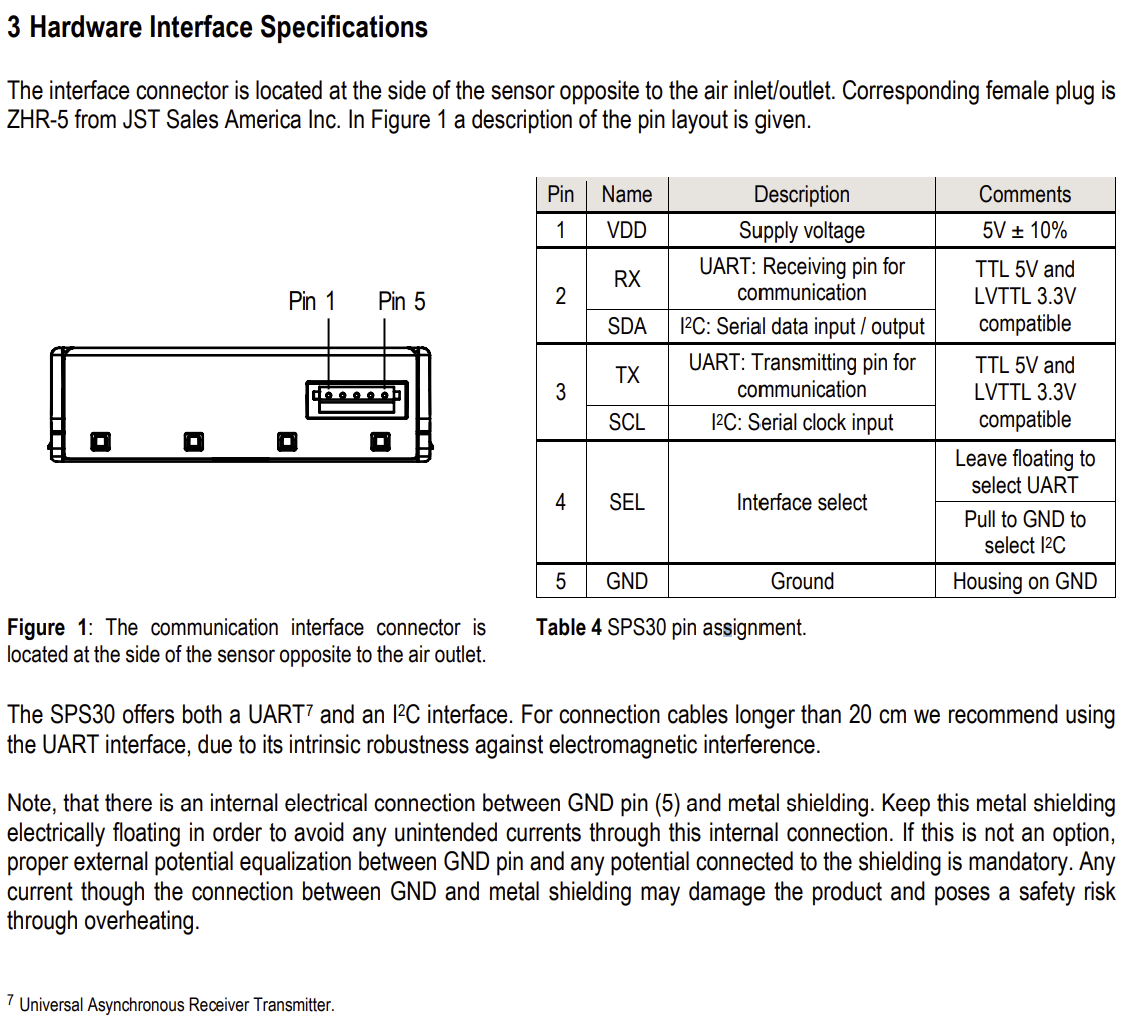
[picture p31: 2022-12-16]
docs/flexibility/assets/sensoren/SPS30-interface-specs.png

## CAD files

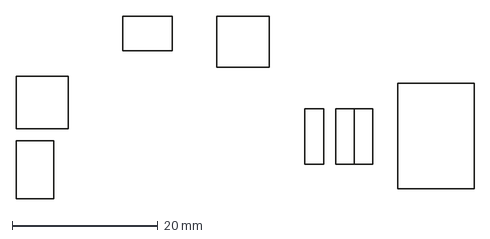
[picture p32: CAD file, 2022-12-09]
docs/flexibility/assets/DFROBOT-DFR0559/DFROBOT-DFR0559-footprint.dxf
62.8 x 25.1 mm

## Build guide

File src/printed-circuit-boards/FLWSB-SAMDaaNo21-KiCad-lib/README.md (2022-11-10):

# SAMDaaNo21 KiCad bibliotheek

De SAMDaaNo21 is een printplaat gebaseerd op de vormfactor van een Arduino NANO en dergelijke developmentbordjes. Het is handig om een printplaat te kunnen ontwikkelen waar de SAMDaaNo21 opgeprikt kan worden.

Om dit proces te vergemakkelijken is er een KiCad bibliotheek ontwikkeld, die bevat een symbol, footprint en 3D-model.

Het is aangeraden om bibliotheken die niet standaard in KiCad zitten mee in de projectmap te steken en te importeren als projectbibliotheek. Als je je projectmap dan deelt met derden zullen zij meteen beschikken over alle nodige bibliotheken.

Tutorial: [How to import into KiCad V6 & later?](https://support.snapeda.com/en/articles/5995733-how-to-import-into-kicad-v6-later)

[SAMDaaNo21 symbol (./FLWSB.kicad_sym)](./FLWSB.kicad_sym)

[SAMDaaNo21 footprint (./FLWSB.pretty/FLWSB-SAMDaaNo21-v1.kicad_mod)](./FLWSB.pretty/FLWSB-SAMDaaNo21-v1.kicad_mod)

[SAMDaaNo21 3D-model (FLWSB-SAMDaaNo21-3D-model.step)](./FLWSB-SAMDaaNo21-3D-model.step)

FLWSB-SAMDaaNo21-v1-symbol

FLWSB-SAMDaaNo21-v1-footprint

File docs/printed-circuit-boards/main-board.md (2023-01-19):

 # Flexible LoRaWAN Sensor Board SAMDaaNo21

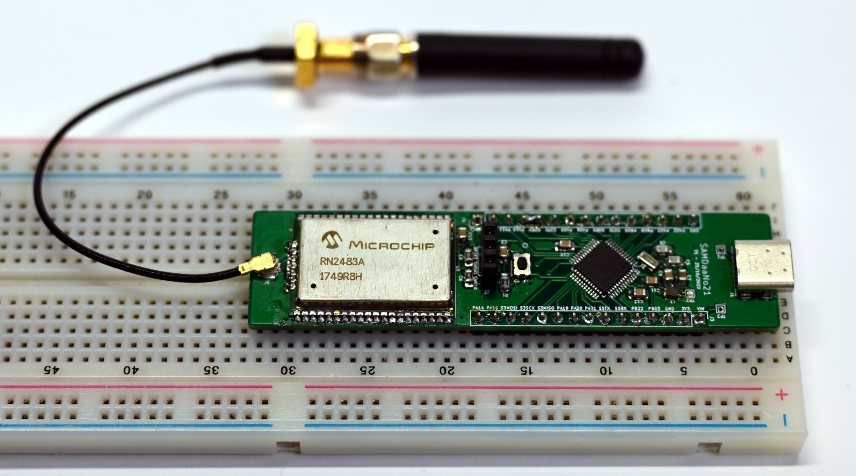
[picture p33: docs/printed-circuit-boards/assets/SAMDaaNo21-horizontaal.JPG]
SAMDaaNo21 Horizontaal Figuur 1: SAMDaaNo21 printplaat op breadboard


SAMDaaNo21 Figuur 2: Pinout diagram SAMDaaNo21

[PDF versie van de pinout diagram](/printed-circuit-boards/assets/SAMDaaNo21-pinout.pdf ':ignore')

Het FLWSB Main Board is een microcontroller bord gebaseerd op de ATSAM D21 in de vormfactor vergelijkbaar met een Arduino Nano. Het moet gemakkelijk zijn om dit bord in een breadboard te prikken en zo testen uit te voeren of schakelingen te bouwen. Het elektrisch schema is [hier](../schematic/main-board) te vinden.

## KiCad bibliotheken

Het is handig om een printplaat te kunnen ontwikkelen waar de SAMDaaNo21 opgeprikt kan worden.

Om dit proces te vergemakkelijken is er een KiCad bibliotheek ontwikkeld, die bevat een symbol, footprint en 3D-model.

Het is aangeraden om bibliotheken die niet standaard in KiCad zitten mee in de projectmap te steken en te importeren als projectbibliotheek. Als je je projectmap dan deelt met derden zullen zij meteen beschikken over alle nodige bibliotheken.

Tutorial: [How to import into KiCad V6 & later?](https://support.snapeda.com/en/articles/5995733-how-to-import-into-kicad-v6-later)

[SAMDaaNo21 bibliotheek bestanden](https://github.com/Dacetylan/FLWSB/tree/SAMDaaNo21/src/printed-circuit-boards/FLWSB-SAMDaaNo21-KiCad-lib)

FLWSB-SAMDaaNo21-v1-symbol Figuur 3: SAMDaaNo21 KiCad symbol
FLWSB-SAMDaaNo21-v1-footprint Figuur 4: SAMDaaNo21 KiCad footprint

## Testpunten

Er zijn verschillende testpunten toegevoegd om op een gemakkelijke en toegankelijke manier verschillende parameters op het bord te kunnen meten.

Er is gekozen voor through hole testpunten zodat het gemakkelijk is om deze met een probe te meten. Alle testpunten zijn te vinden nabij de USB-poort.

| Testpunt nummer | Verbinding |
| --- | --- |
| TP1 | VBUS: 5 V afkomstig van USB |
| TP2 | VDD: 3,3 V gereguleerde spaning |
| TP3 | VIN: Ingangsspanning voordat het naar de lineaire regelaar gaat |

## LoRaWAN Module

De RN2483 zit mee op de printplaat en bevindt zich aan het uiteinde. Er kan een antenne aangesloten worden via een U.FL connector.  

[Productpagina connector](https://be.farnell.com/hirose-hrs/u-fl-r-smt-1-10/rf-coaxial-u-fl-straight-jack/dp/1688077)

## USB Interface & VIN

Het bordje kan voorzien worden van stroom via de USB-C poort. Een LDO (Low Dropout regelaar) zal de spanning afkomstig van de computer reguleren naar een stabiele 3,3 V.

De LDO is een LD1117S33 en ondersteunt een minimale ingangsspanning van 4,3 V en een maximale van 15 V. Dat kan worden aangelegd via de VIN pin. Er is een Schottky diode voorzien om ervoor te zorgen dat de spanning van VIN niet op de USB-poort komt te staan.

*Let op dat je met een lineaire regelaar te maken hebt. Hoe hoger de ingangsspanning, hoe warmer de LDO zal worden!*

Het is ook mogelijk om de regelaar over te slaan en rechtstreeks 3,3 V te leveren via de 3V3 pin. Dit kan handig zijn bij een situatie waarin we zo zuinig mogelijk willen zijn en een efficiëntere 3,3 V regelaar gebruiken van een andere pcb. *Belangrijk is dat deze spanning niet te hard mag afwijken van 3,3 V!*

## RESET & DEBUG

Als er nog geen bootloader op de ATSAMD staat of als we een bare metal installatie gebruiken zullen we gebruik moeten maken van de program en debug header. Dat zijn de 3 pinnen centraal op de printplaat voor de LoRaWAN module. De pinout van links naar recht is: RESET, SWDIO, SWCLK. 

De ATSAMD maakt gebruik van Serial Wire Debugging (SWD), dat maakt het mogelijk om via fuses in te stellen, binaries in te laden en zelfs break-points aan je code toe te voegen.

## Input / Output

Dit zijn alle GPIO, SERCOM en power aansluitingen die via pinheaders naar buiten worden gebracht. De SERCOM poorten zijn alvast gedefinieerd zodat onder andere de pull-up weerstanden geplaatst kunnen worden. Alle andere poorten zijn voor algemeen gebruik. In de datasheet van de ATSAM D21 onder 7. I/O Multiplexing and Considerations kunnen alle verschillende mogelijkheden van deze aansluitingen gevonden worden (AC, ADC, DAC, PTC, DAC, IO, ...). 

PA12 en PA13 zijn onderdeel van de I²C bus en hebben al een pull-up weerstand van 4,7 K voorzien. *Bij het plaatsen van nog externe pull-up weerstanden zullen zij in parallel staan en zal de weerstandswaarde te laag worden.*

## Mogelijke verbeteringen en uitbreidingen

- Momenteel zijn er geen mounting holes aanwezig, dat vonden we  nog niet prioritair.
  - Mouning holes of inkepingen aan de randen van de printplaat zijn dus nog mogelijk en kunnen ook zeker van pas komen.
  - Een printplaat in de stijl van de Arduino Nano Every lijkt ons ook interessant. Dan zouden er geen componenten op de onderkant kunnen staan en zorgen we voor rat-bites aan de zijkant van de printplaat. Op deze manier kan de PCB gebruikt worden als SMD-component.
- De impedantie van het pad naar de antenne-aansluiting is niet theoretisch berekend. Dit is iets waar in een volgende versie over kan worden nagedacht.
- Er is geen LED aanwezig.
- Op het silkscreen staat een fout, `PA07` staat op het silkscreen als `PA09`. 
- Het schema bevat een fout die de LoRaWAN module onbruikbaar maakt. RX en TX van de UART-verbinding moeten omgewisseld worden.

### Tijdelijke oplossing LoRaWAN module

Een UART-verbinding heeft een TX (transmit) en RX (receive) aansluiting nodig. Logischerwijze zal je dus, bij een verbinding tussen twee apparaten, RX en TX met elkaar verbinden. Bij het ontwerpen van dit schema is door onoplettendheid TX met TX verbonden en RX met RX verbonden.

De PINMUX van de ATSAM D21 kan iedere SERCOM pin als RX instellen, maar niet iedere pin als TX schakelen. Dit maakt het onmogelijk om de oplossing geheel softwarematig te zoeken. Enkel PAD0 en PAD2 van een SERCOM poort kan je instellen als TX.

Wij hebben `PA8` (`S2TX` op het silkscreen) ingesteld als RX omdat deze verbonden is met de TX van de LoRaWAN module. `PA09` (`S2RX` op het silkscreen) hebben we hoog impedant gezet (`INPUT`) en kortgesloten met `PA10`. `PA10` is PAD2 van SERCOM2 dus kan ingesteld worden als nieuwe TX.

Het resultaat is dat we nu het baantje naar de RESET pin van de LoRaWAN module moeten onderbreken, omdat `PA10` verbonden is met deze pin. Die onderbreking is het gemakkelijkste te maken met een mesje of platte schroevendraaier net op de plek waar deze richting het pad van de module gaat.

De aanpassingen van deze pinnen is gemaakt in de ArduinoCore dus er hoeft in de code niets gewijzigd te worden.

Er is geen manier meer om de module te resetten vanaf de MCU, moest dat nodig zijn, dan kan er een kabeltje gesoldeerd worden naar een van de vrije GPIO pinnen.

## Bill of Materials

[Open BOM in nieuw tablad.](/printed-circuit-boards/assets/ibom.html ':ignore')

[poc board bill of materials](./assets/ibom.html ':include :type=iframe width=100% height=1024px')

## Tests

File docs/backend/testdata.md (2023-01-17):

# Backend

##  Testdata

Om de backend te testen moet deze gevuld worden met testdata.
De AI studenten zijn modellen aan het trainen met [bestaande historische weerdata uit Duitsland](https://figshare.com/articles/dataset/PPNN_full_data_feather_format_/13516301/1). Ze baseren zich op de paper [Neural Networks for Postprocessing Ensemble Weather Forecasts](https://journals.ametsoc.org/view/journals/mwre/146/11/mwr-d-18-0187.1.xml) door Stephan Rasp and Sebastian Lerch. Om deze testdata in de InfluxDb database te krijgen wordt gebruik gemaakt van onderstaand [Python script](./assets/InfluxDBConnect.py). In dit gedeelte wordt de werking van dit script uitgelegd.

```python
from datetime import datetime
import influxdb_client, os, time
from influxdb_client import InfluxDBClient, Point, WritePrecision
from influxdb_client.client.write_api import SYNCHRONOUS
from influxdb import DataFrameClient
import pandas as pd
import numpy as np

token = ''
org = "AP"
url = "http://localhost:8086"
bucket = "weather-ap"

client = influxdb_client.InfluxDBClient(url=url, token=token, org=org)
columns = list(data.columns)
columns.remove("date")
write_api = client.write_api(write_options=SYNCHRONOUS)

data = pd.read_feather("../data/data_RL18.feather")
data.station = pd.to_numeric(data.station, downcast = 'integer')

# drop soil moisture predictions due to missing values
# Note that self is a minor change compared to the paper, but does not have a significant effect
data = data.drop(['sm_mean', 'sm_var'], axis=1)

data_frame = data
data_frame = data_frame[(data_frame['date'].dt.year==2015)&(data_frame['station']==10)]

data_frame.index = data_frame['date']
# DataFrame must have the timestamp column as an index for the client.
write_api.write(bucket = bucket,record= data_frame,data_frame_measurement_name='obs',data_frame_tag_columns=columns)

my_token = ''
my_org = "AP"
url = "http://localhost:8086"
bucket = "weather-ap"
query= '''
from(bucket: "weather-ap")
|> range(start:-15y, stop: now())
|> filter(fn: (r) => r._measurement == "obs")
|> pivot(rowKey:["_time"], columnKey: ["_field"], valueColumn: "_value")
'''

client = InfluxDBClient(url="http://localhost:8086", token=my_token, org=my_org, debug=False)
system_stats = client.query_api().query_data_frame(org=my_org, query=query)
print(system_stats.head())
```

### Python en InfluxDb

InfluxDB bestaat uit buckets, die aangesproken kunnen worden met organisaties en tokens.

Met de python library influxdb_client kan op deze manier connectie gemaakt worden met een bestaande influxdb instance.

```python
import influxdb_client
from influxdb_client import InfluxDBClient
from influxdb_client.client.write_api import SYNCHRONOUS
```

### Dataframes inladen

[pandas.read_feather](https://pandas.pydata.org/docs/reference/api/pandas.read_feather.html)

[pandas dataframe](https://pandas.pydata.org/docs/user_guide/dsintro.html#dataframe)

Met pandas kunnen verschillende databestanden ingeladen worden in dataframes. Hierna kan het dataframe omgevormd worden tot het gewenste formaat, waarna het onder eender welk bestandstype opgeslagen kan worden of kan het bvb naar een database gestuurd worden.
De dataframe wordt hier toegewezen aan de 'data' variabele.

Vanuit feather:
```
data = pd.read_feather("../data/data_RL18.feather")
data.station = pd.to_numeric(data.station, downcast = 'integer')
data = data.drop(['sm_mean', 'sm_var'], axis=1)
```
Enkele veelgebruikte functionaliteiten:
```
data.columns --> returnt array van alle kolomnamen in de dataframe

data["column_name"] --> selecteren van enkele kolom

data.count() --> geeft overzicht van het aantal elementen in pandas object

data.isna() --> returnt pandas object waar elke waarde vervangen is door True of False, naargelang dit een missende waarde is of niet

data[[condition1==True&&condition2==False]] --> conditionele selectie van waarden uit pandas object

data.mean() --> gemiddelde van waarden in dit object, 1 van de verschillende aggregatiefuncties.
```

### Schrijven naar InfluxDB

De tijdsgebonden kolom wordt ingesteld als index (vb. date), en er wordt een _measurement aangemaakt, die dan bestaat uit meerdere _fields. Deze _fields worden gemapt aan de kolommen van de dataframe, en bevatten data voor alle gewenste features binnen een bepaalde tijdsperiode.

De token en organisatie worden mee gegeven en met een write-api kan zo tijdgebonden data doorgestuurd worden naar de bucket. In het geval van een dataframe, moet deze eerst nog omgevormd worden om door influxdb geaccepteerd te worden.

```python
client = influxdb_client.InfluxDBClient(url=url, token=token, org=org)
columns = list(data_frame.columns)
columns.remove("date")
write_api = client.write_api(write_options=SYNCHRONOUS)
data_frame.index = data_frame['date']

write_api.write(bucket = bucket,record= data_frame,data_frame_measurement_name='obs',data_frame_tag_columns=columns)
```

### Lezen uit InfluxDB

Met behulp van de [Flux](https://fluxcd.io/flux/) syntax, kunnen queries opgesteld worden om data uit een influxDB op te halen. Er wordt een tijdsrange ingesteld, alsook de measurements en fields die opgehaald moeten worden. Vervolgens kan dan opnieuw met influxdb_client een query gedaan worden naar de ifdb instance.

```python
query= '''
from(bucket: "weather-ap")
|> range(start:-15y, stop: now())
|> filter(fn: (r) => r._measurement == "obs")
|> pivot(rowKey:["_time"], columnKey: ["_field"], valueColumn: "_value")
'''

client = InfluxDBClient(url="http://localhost:8086", token=my_token, org=my_org, debug=False)
system_stats = client.query_api().query_data_frame(org=my_org, query=query)
```

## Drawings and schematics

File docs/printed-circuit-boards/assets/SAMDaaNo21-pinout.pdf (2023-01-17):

# SAMDaaNo21

# A SAMD21 Developmentboard withLoRaWAN

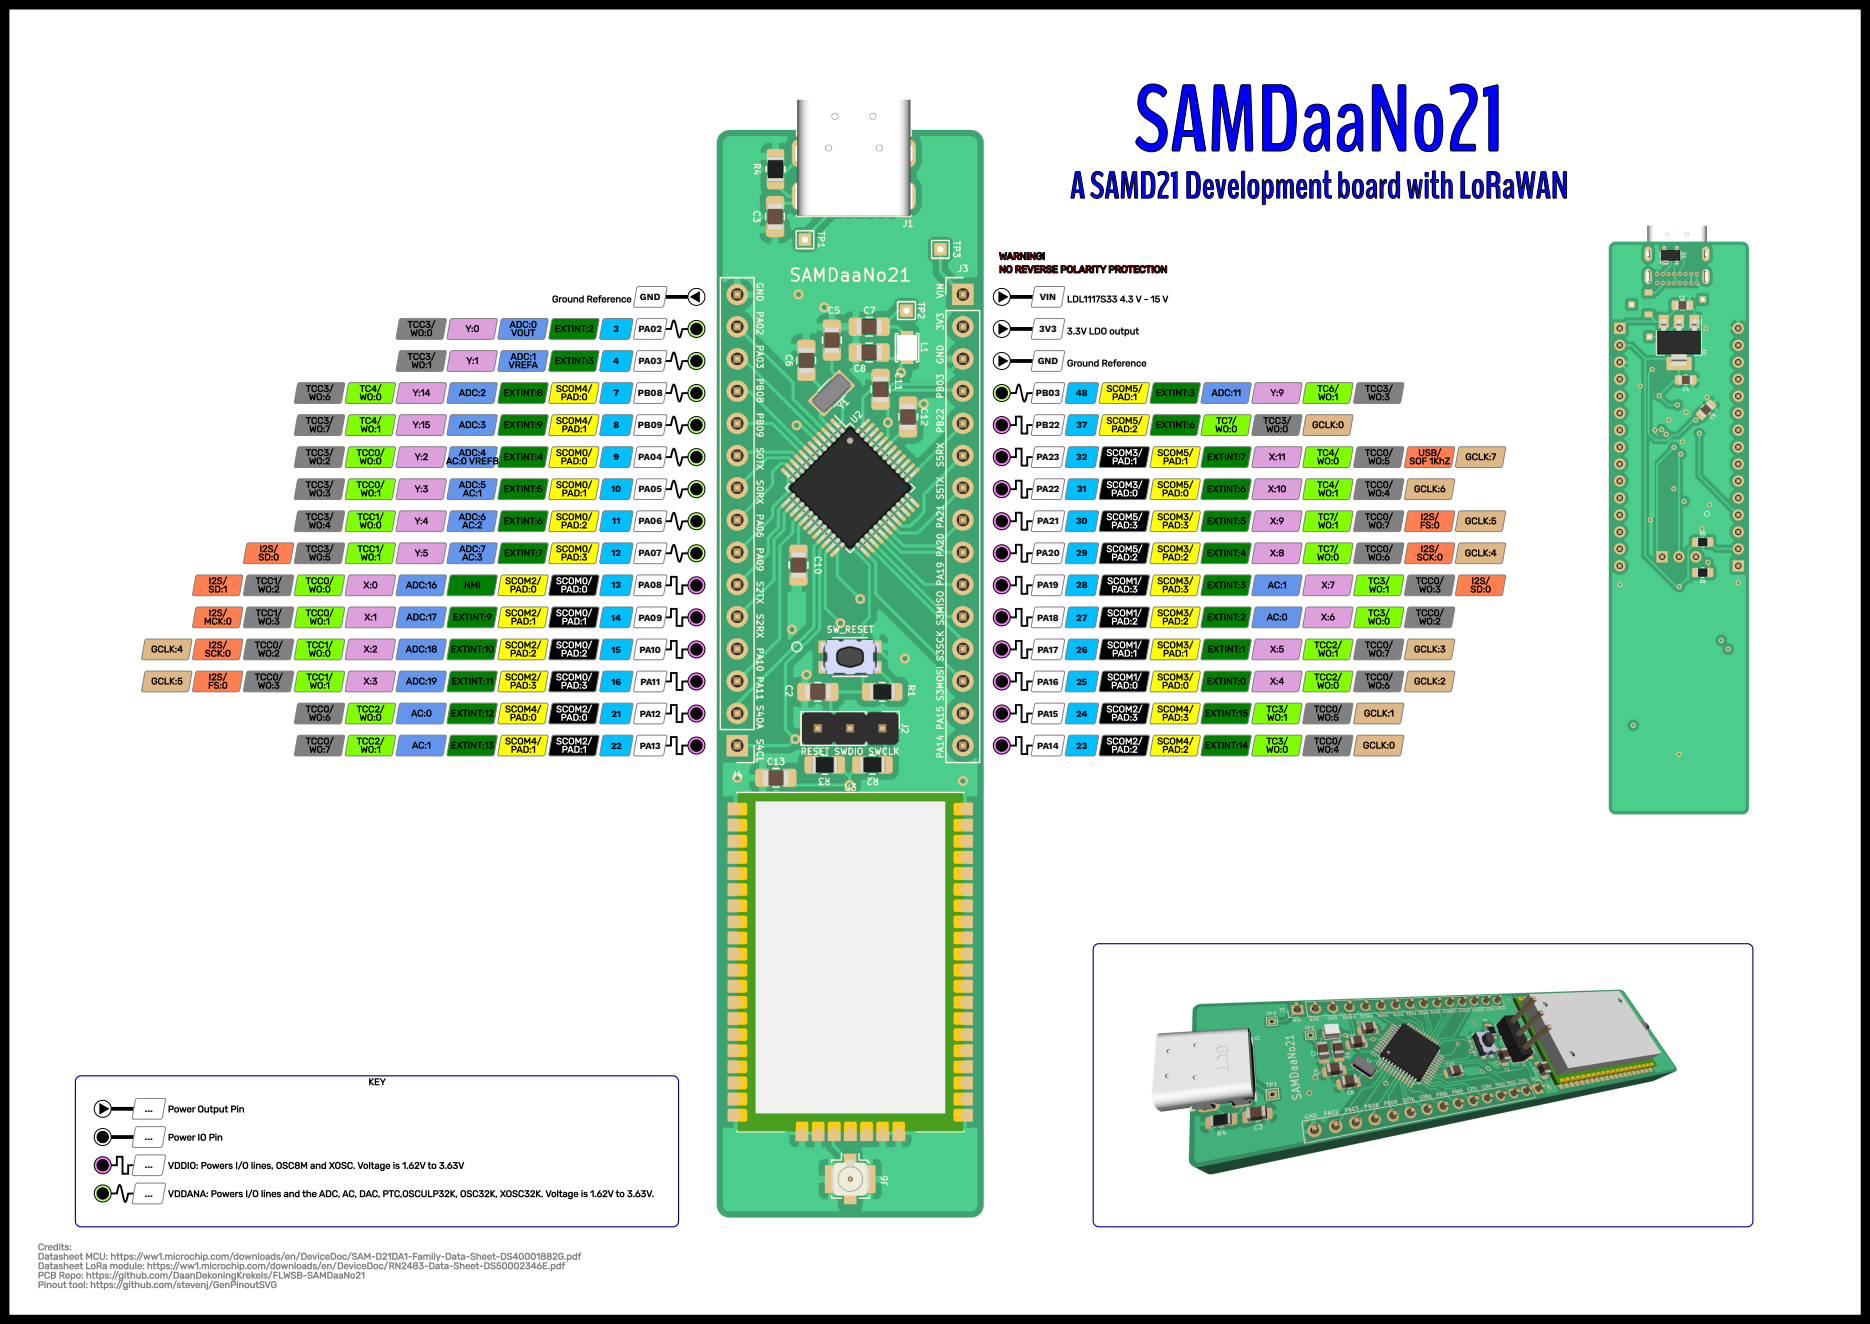
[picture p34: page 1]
EXTINT:2; PA02 ADC:0; VOUT; TCC3/ WO:0; EXTINT:3; PA03 ADC:1; VREFA; TCC3/ WO:1; SCOM4/ PAD:0; ADC:2; EXTINT:8; TCC3/ WO:6; SCOM4/ PAD:1; ADC:3; EXTINT:9; TCC3/ WO:7; SCOM0/ PAD:0; EXTINT:4 ADC:4 AC:0 VREFB; TCC0/ WO:0; TCC3/ WO:2; SCOM0/ PAD:1; EXTINT:5 ADC:5 AC:1; TCC0/ WO:1; TCC3/ WO:3; SCOM0/ PAD:2; EXTINT:6 ADC:6 AC:2; TCC1/ WO:0; TCC3/ WO:4; SCOM0/ PAD:3; EXTINT:7 ADC:7 AC:3; TCC1/ WO:1; TCC3/ WO:5; SCOM2/ PAD:0; ADC:16; NMI; TCC1/ WO:2; SCOM2/ PAD:1; ADC:17; TCC1/ WO:3; I2S/ MCK:0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

WARNING!
NO REVERSE POLARITY PROTECTION

Ground Reference GND

GND Ground Reference

Credits:
Datasheet MCU: https://ww1.microchip.com/downloads/en/DeviceDoc/SAM-D21DA1-Family-Data-Sheet-DS40001882G.pdf
Datasheet LoRa module: https://ww1.microchip.com/downloads/en/DeviceDoc/RN2483-Data-Sheet-DS50002346E.pdf
PCB Repo: https://github.com/DaanDekoningKrekels/FLWSB-SAMDaaNo21
Pinout tool: https://github.com/stevenj/GenPinoutSVG

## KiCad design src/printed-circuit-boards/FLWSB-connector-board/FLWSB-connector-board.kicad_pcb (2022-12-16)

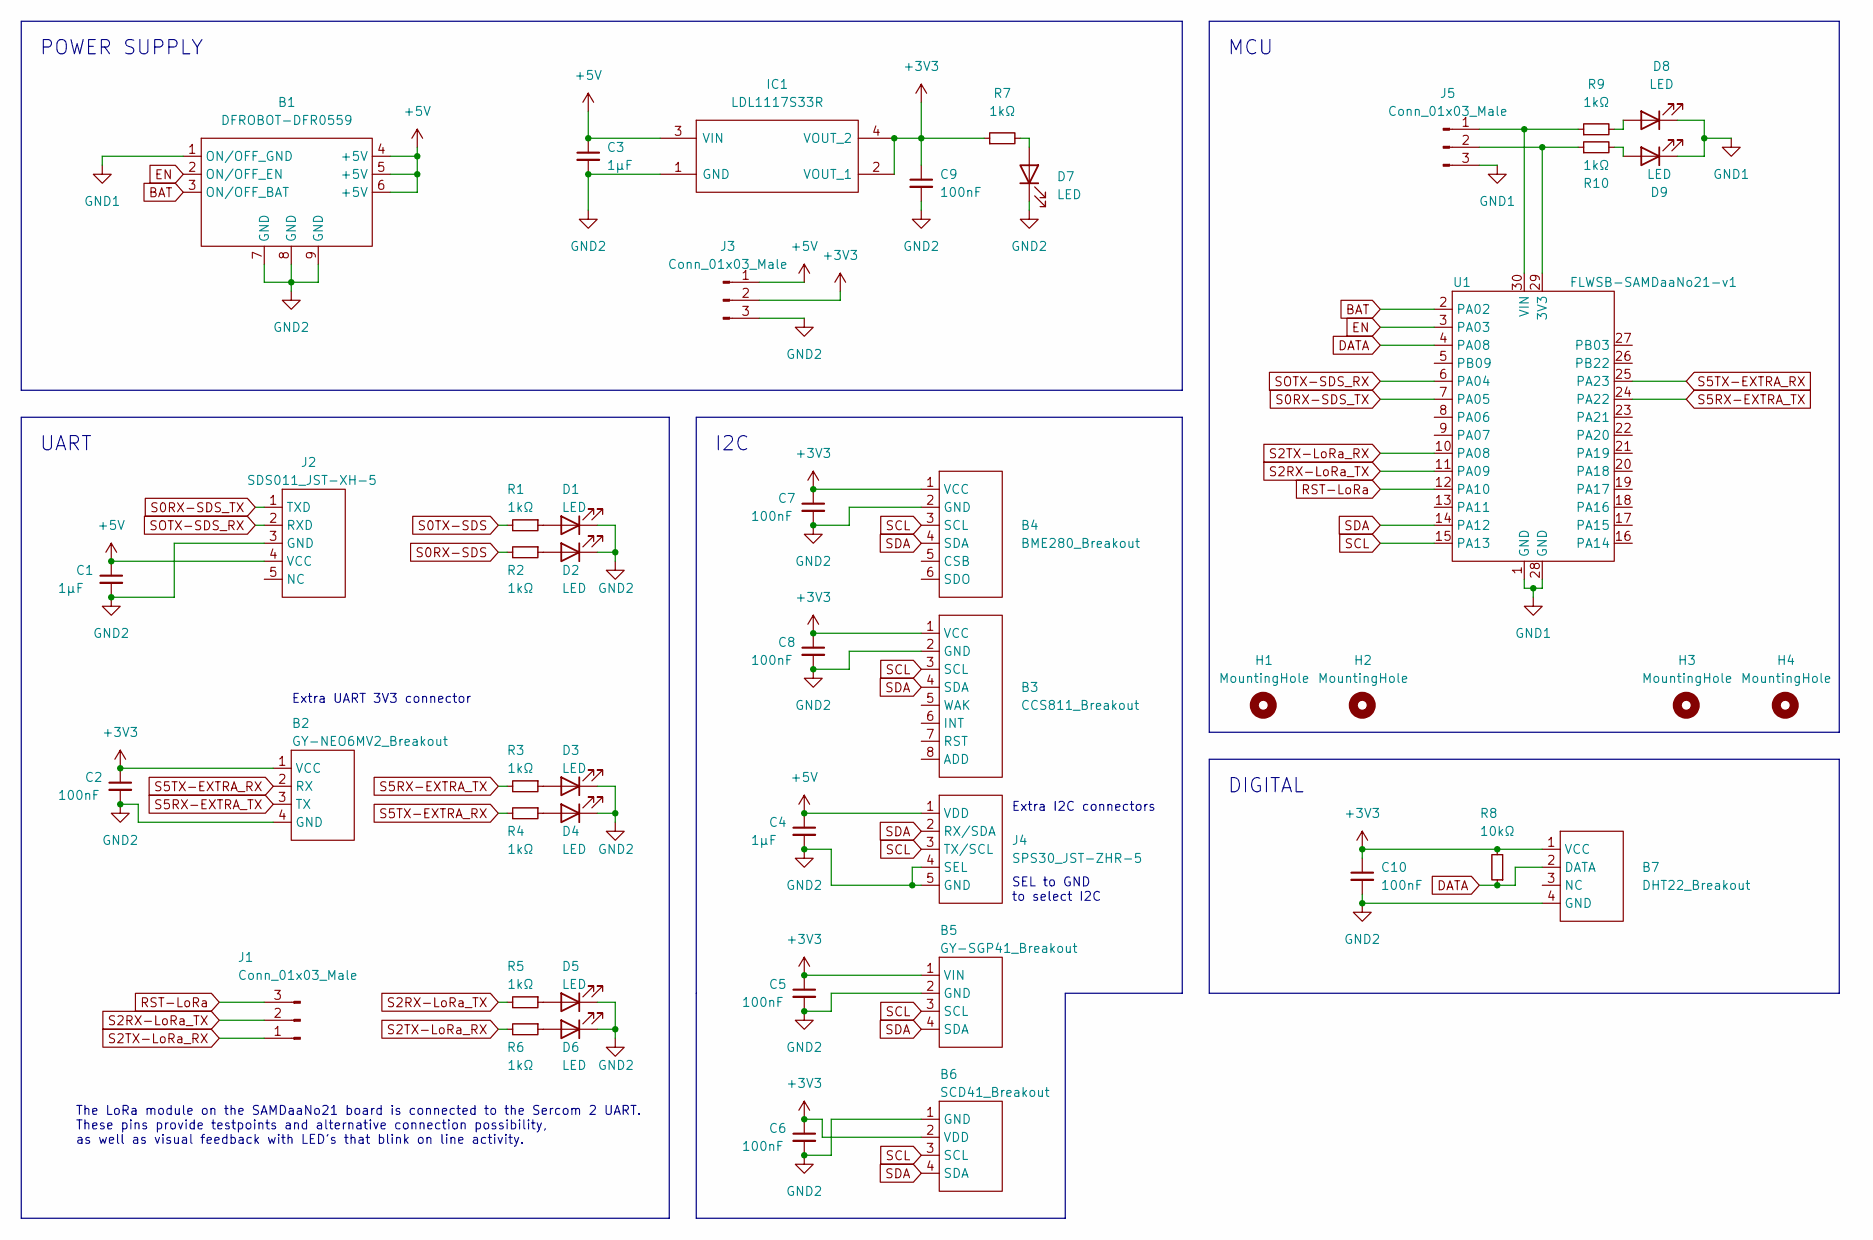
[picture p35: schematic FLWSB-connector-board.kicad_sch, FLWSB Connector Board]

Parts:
B1: DFROBOT-DFR0559
B2: GY-NEO6MV2_Breakout; PinHeader_1x04_P2.54mm_Vertical
B3: CCS811_Breakout
B4: BME280_Breakout; BM280_Breakout
B5: GY-SGP41_Breakout; PinHeader_1x04_P2.54mm_Vertical
B6: SCD41_Breakout; PinHeader_1x04_P2.54mm_Vertical
B7: DHT22_Breakout; PinHeader_1x04_P2.54mm_Vertical
C1, C3, C4: 1µF; C_0805_2012Metric_Pad1.18x1.45mm_HandSolder
C2, C5, C6, C7, C8, C9, C10: 100nF; C_0805_2012Metric_Pad1.18x1.45mm_HandSolder
D1, D2, D3, D4, D5, D6, D7, D8, D9: LED; LED_0805_2012Metric_Pad1.15x1.40mm_HandSolder
H1, H2, H3, H4: MountingHole; MountingHole_3.2mm_M3_Pad_Via
IC1: LDL1117S33R; SOT95P280X145-5N; Manufacturer_Part_Number LDL1117S33R; Mouser Part Number 511-LDL1117S33R
J1, J3, J5: Conn_01x03_Male; PinHeader_1x03_P2.54mm_Vertical
J2: SDS011_JST-XH-5; JST_XH_B5B-XH-A_1x05_P2.50mm_Vertical
J4: SPS30_JST-ZHR-5; JST_XH_B5B-XH-A_1x05_P2.50mm_Vertical
R1, R2, R3, R4, R5, R6, R7, R9, R10: 1kΩ; R_0805_2012Metric_Pad1.20x1.40mm_HandSolder
R8: 10kΩ; R_0805_2012Metric_Pad1.20x1.40mm_HandSolder
U1: FLWSB-SAMDaaNo21-v1

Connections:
+3V3: B2.1 (VCC), B3.1 (VCC), B4.1 (VCC), B5.1 (VIN), B6.2 (VDD), B7.1 (VCC), C2.1, C5.1, C6.1, C7.1, C8.1, C9.1, C10.1, IC1.2 (VOUT_1), IC1.4 (VOUT_2), J3.2, R7.1, R8.2
+5V: B1.4 (+5V), B1.5 (+5V), B1.6 (+5V), C1.1, C3.1, C4.1, IC1.3 (VIN), J2.4 (VCC), J3.1, J4.1 (VDD)
BAT: B1.3 (ON/OFF_BAT), U1.2 (PA02)
DATA: B7.2 (DATA), R8.1, U1.4 (PA08)
EN: B1.2 (ON/OFF_EN), U1.3 (PA03)
GND1: B1.1 (ON/OFF_GND), D8.1 (K), D9.1 (K), J5.3, U1.1 (GND), U1.28 (GND)
GND2: B1.7 (GND), B1.8 (GND), B1.9 (GND), B2.4 (GND), B3.2 (GND), B4.2 (GND), B5.2 (GND), B6.1 (GND), B7.4 (GND), C1.2, C2.2, C3.2, C4.2, C5.2, C6.2, C7.2, C8.2, C9.2, C10.2, D1.1 (K), D2.1 (K), D3.1 (K), D4.1 (K), D5.1 (K), D6.1 (K), D7.1 (K), IC1.1 (GND), J2.3 (GND), J3.3, J4.4 (SEL), J4.5 (GND)
unnamed: D1.2 (A), R1.1
unnamed: D2.2 (A), R2.1
unnamed: D3.2 (A), R3.1
unnamed: D4.2 (A), R4.1
unnamed: D5.2 (A), R5.1
unnamed: D6.2 (A), R6.1
unnamed: D7.2 (A), R7.2
unnamed: D8.2 (A), R9.2
unnamed: D9.2 (A), R10.2
unnamed: J5.1, R9.1, U1.30 (VIN)
unnamed: J5.2, R10.1, U1.29 (3V3)
RST-LoRa: J1.3, U1.12 (PA10)
S0RX-SDS: R2.2
S0RX-SDS_TX: J2.1 (TXD), U1.7 (PA05)
S0TX-SDS: R1.2
S2RX-LoRa_TX: J1.2, R5.2, U1.11 (PA09)
S2TX-LoRa_RX: J1.1, R6.2, U1.10 (PA08)
S5RX-EXTRA_TX: B2.3 (TX), R3.2, U1.24 (PA22)
S5TX-EXTRA_RX: B2.2 (RX), R4.2, U1.25 (PA23)
SCL: B3.3 (SCL), B4.3 (SCL), B5.3 (SCL), B6.3 (SCL), J4.3 (TX/SCL), U1.15 (PA13)
SDA: B3.4 (SDA), B4.4 (SDA), B5.4 (SDA), B6.4 (SDA), J4.2 (RX/SDA), U1.14 (PA12)
SOTX-SDS_RX: J2.2 (RXD), U1.6 (PA04)

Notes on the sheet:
SEL to GND to select I2C
MCU
DIGITAL
UART
POWER SUPPLY
Extra UART 3V3 connector
I2C
The LoRa module on the SAMDaaNo21 board is connected to the Sercom 2 UART. These pins provide testpoints and alternative connection possibility, as well as visual feedback with LED's that blink on line activity.
Extra I2C connectors

Board: 2 copper layers, 47 parts (0 on the bottom side), 27 nets, no tracks yet.

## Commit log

2022-09-30 Main Board Schema Documentatie
2022-10-28 SAMDaaNo21 pcb toegevoegd
2022-10-28 toevoegen SAMDaaNo21 PCB
2022-11-03 Eerste versie KiCad bibliotheek (symbool, footprint, 3d-model)
2022-11-04 documentatie SAMDaaNo21 KiCad lib
2022-11-25 Backend update + Connector board documentatie met blokdiagram
2022-12-04 Backend on Linux + update weather station data + update connector board
2022-12-05 Begin documentatie Arduino IDE ondersteuning SAMDaaNo21
2022-12-09 Backend verplaatst naar src folder + update connector board, schema, pcb
    [DFROBOT-DFR0559-footprint.dxf, FLWSB-connector-board.kicad_pcb, FLWSB-connector-board.kicad_sch]
2022-12-09 Correctie documentatie plaatsing
    [DFROBOT-DFR0559-footprint.dxf]
2022-12-11 SAMDaaNo21 Arduino IDE ondersteuning documentatie
2022-12-11 pinout, ArduinoCore-samd en BOSSA toegevoegd als submodule
2022-12-16 Update data structuur + backend troubleshooting + update connector board
2022-12-16 Update connector board v1.1
    [FLWSB-connector-board.kicad_pcb, FLWSB-connector-board.kicad_sch]
2022-12-18 Update backend, security, solar power
2022-12-19 Verplaatsen arduino-core documentatie
2023-01-16 Updated docs structure + added Flexibility and Boards Design + Updates
    [DFROBOT-DFR0559-footprint.dxf]
2023-01-17 Update documentatie: demo, backend, data-formatting, enclosure, intro
2023-01-19 Backup node-red flows + current deployment + update docs sis + real-data
2023-01-19 documentatie weather station, misschien dat het nu wel allemaal erbij zit???? Vorige keer was een stuk gewoon verdwenengit add .
2023-01-19 SIS implementatie ArduinoCore
